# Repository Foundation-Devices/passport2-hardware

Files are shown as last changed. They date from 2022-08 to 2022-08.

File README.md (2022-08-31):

# Passport Electromechanical Design

This repository contains the electromechanical design files for Passport.

Passport

## Folder Organization
This repo contains the following folders:

- **`electronics`** - The Passport PCB design files.
- **`mechanical`** - The Passport enclosure design files, including front cover, mid-housing, rear cover and keypad parts.
- **`bill-of-materials`** - Spreadsheet list of all custom and stock physical components used to assemble Passport.

## Licensing
License information can be found in each folder.

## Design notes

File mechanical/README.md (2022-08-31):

# Passport Mechanical

This repository contains the full production assembly for Passport, an open source Bitcoin hardware wallet made by Foundation Devices.

Passport

### Folder Organization
This repo contains the following folders:
- **`STEP Files`** - a set of 3D models for Passport in STEP format.

### Documenting Changes
This repository includes a CHANGES.txt file. We will document all design changes in this file. If you submit a pull request that makes changes to the circuit designs, please update CHANGES.txt with a brief description of your changes.

## Security Vulnerability Disclosure
Please report suspected security vulnerabilities in private to security@foundationdevices.com. Please do NOT create publicly viewable issues for suspected security vulnerabilities.

## Licensing
The hardware in this project, including all mechanical and electrical design files, is licensed under CERN-OHL-S v2 – a viral, copyleft, open source license. CERN-OHL-S v2 is similar in goals to GPLv3, but is specifically designed for hardware projects.

The software in this project, as detailed in the passport-firmware submodule, is licensed under numerous software licenses but must be treated as copyleft due to the inclusion of GPLv3 licensed code.

You are welcome to use these designs for any purpose, but you must comply with the terms of the licenses. This includes licensing derivative work as CERN-OHL-S v2 and GPLv3, preserving copyright notices, and more. Instructions are included in LICENSE_GUIDE.txt. Feel free to contact us with any questions about licensing.

Included in this repository in LICENSE.txt is the full text of CERN-OHL-S v2.

### License Notice
You may redistribute and modify this source and make products using it
under the terms of the CERN-OHL-S v2 (https://ohwr.org/cern_ohl_s_v2.txt).

This source is distributed WITHOUT ANY EXPRESS OR IMPLIED WARRANTY,
INCLUDING OF MERCHANTABILITY, SATISFACTORY QUALITY AND FITNESS FOR A
PARTICULAR PURPOSE. Please see the CERN-OHL-S v2 for applicable conditions.

Source location: foundationdevices.com/passport-assembly

As per CERN-OHL-S v2 section 4, should You produce hardware based on this
source, You must where practicable and applicable maintain the Source Location
visible (1) on the packaging of the hardware, (2) on the circuit board(s) via
silkscreen or copper, (3) on the plastic and metal components, (4) in any documentation, 
and (5) on other products you make using this source.

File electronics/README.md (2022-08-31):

# Passport Electronics

This repository contains the production circuit designs for Passport 2, an open source Bitcoin hardware wallet made by Foundation Devices.

main board block diagram

Above is a basic block diagram for Passport's circuit Board.

## Project Structure

### Folder Organization
The circuit board files are in several sub-folders under the `PCB` folder.

- Assembly
- Documentation
- Fabrication
- Source Files

**Assembly** contains data for assembling components onto a bare circuit board. It includes drawings, bill of materials, and coordinates for pick-and-place and test points.

**Documentation** contains simple PDF overview documents of the schematics and board design.

**Fabrication** contains data for the circuit board fabricator. It includes drawings, Gerber files, and coordinates for drilling and test points.

**Source Files** contains circuit board designs. It includes circuit schematics and Altium design files.

Circuit designs can only be opened with Altium. We are exploring exporting these designs in multiple file formats, including formats that can be used with open source PCB design software.

If you are interested in using KiCAD, you may try this Altium to KiCAD converter: https://github.com/thesourcerer8/altium2kicad/.

### Documenting Changes
This repository includes a CHANGES.txt file. We will document all design changes in this file. If you submit a pull request that makes changes to the circuit designs, please update CHANGES.txt with a brief description of your changes.

## Open Source Components
Passport's Main Board incorporates an open-source schematic from the [Betrusted project](https://github.com/betrusted-io/betrusted-hardware-xt). Specifically, we implemented Betrusted's [Avalance Noise Source](https://betrusted.io/avalanche-noise) design into Passport to serve as a true random number generator that does not rely on black-box silicon. Thank you to the Betrusted team for open sourcing their excellent work.

## Security Vulnerability Disclosure
Please report suspected security vulnerabilities in private to security@foundationdevices.com. Please do NOT create publicly viewable issues for suspected security vulnerabilities.

## Licensing
This project, and every file included in this repository, is licensed under CERN-OHL-S v2 – a viral, copyleft, open source license. CERN-OHL-S v2 is similar in goals to GPLv3, but is specifically designed for hardware projects.

You are welcome to use these designs for any purpose, but you must comply with the terms of the license. This includes licensing derivative work as CERN-OHL-S v2, preserving copyright notices, and more. Instructions are included in LICENSE_GUIDE.txt. Feel free to contact us with any questions about licensing.

Included in this repository in LICENSE.txt is the full text of CERN-OHL-S v2.

### License Notice
You may redistribute and modify this source and make products using it
under the terms of the CERN-OHL-S v2 (https://ohwr.org/cern_ohl_s_v2.txt).

This source is distributed WITHOUT ANY EXPRESS OR IMPLIED WARRANTY,
INCLUDING OF MERCHANTABILITY, SATISFACTORY QUALITY AND FITNESS FOR A
PARTICULAR PURPOSE. Please see the CERN-OHL-S v2 for applicable conditions.

Source location: foundationdevices.com/passport-electronics

As per CERN-OHL-S v2 section 4, should You produce hardware based on this
source, You must where practicable and applicable maintain the Source Location
visible (1) on the packaging of the hardware, (2) on the circuit board(s) via
silkscreen or copper, (3) in any documentation, and (4) on other products you
make using this source.

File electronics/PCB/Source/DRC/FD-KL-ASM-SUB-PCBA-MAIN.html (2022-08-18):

Altium

# Design Rule Verification Report

Date: | | 12/11/2021
Time: | | 8:59:33 PM
Elapsed Time: | | 00:00:12
Filename: | | C:\Users\matth\AppData\Local\TempReleases\Snapshot\6\FD-KL-ASM-SUB-PCBA-MAIN.PcbDoc

Warnings: | | 0
Rule Violations: | | 0

## Summary

Warnings | Count
Total | 0

Rule Violations | Count
Clearance Constraint (Gap=0.1mm) ((InNetClass('DCMI') or InNet('DCMI_VREF1') or InNet('DCMI_VREF2') or InNet('+DCMI_AVDD') or InNet('+DCMI_DOVDD') or InNet('I2C1_SDA') or InNet('I2C1_SCL')) and Onlayer('L4') or InNet('+2V8_CAM_AVDD')),(All) | 0
Clearance Constraint (Gap=0.15mm) (InComponent('SW*')),(All) | 0
Clearance Constraint (Gap=0.1mm) (InNet('+VBAT') or InNet('+VBAT_MCU')),(All) | 0
Clearance Constraint (Gap=0.1mm) (InComponent('FID1') or InComponent('FID2') or InComponent('FID3') or InComponent('FID4') or InComponent('FID5') or InComponent('FID6')),(All) | 0
Clearance Constraint (Gap=0.2mm) (All),(All) | 0
Short-Circuit Constraint (Allowed=No) (All),(All) | 0
Un-Routed Net Constraint ( (All) ) | 0
Modified Polygon (Allow modified: No), (Allow shelved: No) | 0
Width Constraint (Min=0.1mm) (Max=1mm) (Preferred=0.1mm) (InNetClass('DCMI') or InNet('I2C1_SCL') or InNet('I2C1_SDA') or InNet('GND')) | 0
Width Constraint (Min=0.1mm) (Max=5mm) (Preferred=0.15mm) (All) | 0
Routing Layers(All) | 0
Routing Via (MinHoleWidth=0.2mm) (MaxHoleWidth=0.4mm) (PreferredHoleWidth=0.3mm) (MinWidth=0.4mm) (MaxWidth=0.8mm) (PreferedWidth=0.6mm) (All) | 0
Differential Pairs Uncoupled Length using the Gap Constraints (Min=0.2mm) (Max=0.2mm) (Prefered=0.2mm) and Width Constraints (Min=0.2mm) (Max=0.2mm) (Prefered=0.2mm) (All) | 0
SMD Neck-Down Constraint (Percent=100%) (All) | 0
Power Plane Connect Rule(Relief Connect )(Expansion=0.508mm) (Conductor Width=0.254mm) (Air Gap=0.254mm) (Entries=4) (All) | 0
Minimum Annular Ring (Minimum=0.099mm) (All) | 0
Hole Size Constraint (Min=0.2mm) (Max=5.5mm) (All) | 0
Pads and Vias to follow the Drill pairs settings | 0
Hole To Hole Clearance (Gap=0.2mm) (All),(All) | 0
Minimum Solder Mask Sliver (Gap=0.049mm) (All),(All) | 0
Silk To Solder Mask (Clearance=0.08mm) (IsPad),(All) | 0
Silk to Silk (Clearance=0.1mm) (All),(All) | 0
Net Antennae (Tolerance=0mm) (All) | 0
Board Clearance Constraint (Gap=0mm) (All) | 0
Board Clearance Constraint (Gap=0mm) (OnLayer('Top Overlay')) | 0
Vias Under SMD Constraint (Allowed=Not Allowed) ((not InNet('GND'))) | 0
Component Clearance Constraint ( Horizontal Gap = -1mm, Vertical Gap = -1mm ) (InComponent('R53')),(InComponent('R57')) | 0
Component Clearance Constraint ( Horizontal Gap = -1mm, Vertical Gap = -1mm ) (InComponent('R54')),(InComponent('R61')) | 0
Component Clearance Constraint ( Horizontal Gap = -1mm, Vertical Gap = -1mm ) (InComponent('R63')),(InComponent('R68')) | 0
Component Clearance Constraint ( Horizontal Gap = -1mm, Vertical Gap = -1mm ) (InComponent('R71')),(InComponent('R72')) | 0
Component Clearance Constraint ( Horizontal Gap = -1mm, Vertical Gap = -1mm ) (InComponent('R2')),(InComponent('R64')) | 0
Component Clearance Constraint ( Horizontal Gap = -1mm, Vertical Gap = -1mm ) (InComponent('R58')),(InComponent('R67')) | 0
Component Clearance Constraint ( Horizontal Gap = -1mm, Vertical Gap = -1mm ) (Identifier='FD-1842_Assem_v05_2020-06-12'),(All) | 0
Component Clearance Constraint ( Horizontal Gap = -1mm, Vertical Gap = -1mm ) (InComponent('R9')),(InComponent('R73')) | 0
Component Clearance Constraint ( Horizontal Gap = -1mm, Vertical Gap = -1mm ) ((Identifier='FD-KL-HOUSING-FRONT') or (Identifier='FD-KL-FG-HOUSING-MID') or (Identifier='FD-KL-LATCH-BATTERY') or (Identifier='FD-KL-LENS-LIGHTPIPE') or (Identifier='FD-KL-ASM-FG-DISPLAY-LCD-IPS-2-INCH') or (Identifier='FD-KL-ASM-FG-KEYPAD') or (Identifier='FD-KL-ACTUATOR-BUTTON-POWER') or (Identifier='FD-KL-FG-COVER-REAR')),(All) | 0
Component Clearance Constraint ( Horizontal Gap = 0.1mm, Vertical Gap = 0.1mm ) (All),(All) | 0
Component Clearance Constraint ( Horizontal Gap = -1mm, Vertical Gap = -1mm ) (InComponent('R53')),(InComponent('R54')) | 0
Component Clearance Constraint ( Horizontal Gap = -1mm, Vertical Gap = -1mm ) (InComponent('R62')),(InComponent('C51')) | 0
Component Clearance Constraint ( Horizontal Gap = -1mm, Vertical Gap = -1mm ) (InComponent('R69')),(InComponent('R70')) | 0
Height Constraint (Min=0mm) (Max=25.4mm) (Prefered=12.7mm) (All) | 0
Height Constraint (Min=0mm) (Max=1mm) (Prefered=0.5mm) (TouchesRoom('BatteryClearance')) | 0
Total | 0

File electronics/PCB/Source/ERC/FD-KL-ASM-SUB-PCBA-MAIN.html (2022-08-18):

Altium

# Electrical Rule Check Report

Date: | | 12/11/2021
Time: | | 8:59:49 PM
Filename: | | C:\Users\matth\AppData\Local\TempReleases\Snapshot\6\Sources\ERC\FD-KL-ASM-SUB-PCBA-MAIN.html

Class | Document | Message
Warning | STM32H753.SchDoc | Net BRDREV0 has no driving source (Pin R2-1, Pin R64-2, Pin TP53-1, Pin U2-58)
Warning | Title.SchDoc | Net LCD_TE has no driving source (Pin J2-2, Pin TP66-1, Pin U2-91)
Warning | Charger.SchDoc | Net NetC66_2 has no driving source (Pin C66-2, Pin R84-1, Pin U27-D3)
Warning | Charger.SchDoc | Net NetC67_1 has no driving source (Pin C67-1, Pin C68-2, Pin R87-2, Pin U27-A1)
Warning | Charger.SchDoc | Net NetC67_2 has no driving source (Pin C67-2, Pin C69-1, Pin R88-2, Pin U27-B1)
Warning | Charger.SchDoc | Net NetR86_1 has no driving source (Pin R86-1, Pin TP73-1, Pin U23-5)
Warning | Power.SchDoc | Net PS_3V0_FB has no driving source (Pin C54-2, Pin R30-1, Pin R32-1, Pin U11-10)
Warning | Title.SchDoc | Net PWR_SW_MCU has no driving source (Pin D1-A, Pin R37-2, Pin TP75-1, Pin U2-34)
Warning | Title.SchDoc | Net SYS_RST# has no driving source (Pin C52-1, Pin J4-8, Pin R3-1, Pin TP43-1, Pin U2-14)
Warning | Title.SchDoc | Net USART2_RX has no driving source (Pin J4-11, Pin TP46-1, Pin U2-25)
Warning | Camera.SchDoc | Nets Wire GND has multiple names (Power Object GND (123), Power Object GND_A (6))

Back to top

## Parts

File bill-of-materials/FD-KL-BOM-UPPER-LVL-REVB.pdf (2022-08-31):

Assembly / Sub Assembly | LVL CAD Name / Foundation SKU | REV | Description | QTY | Custom Manufacturer | MFG P/N
1 FD-KL Asm Sub PCBA Main | 1 | FD-KL-ASM-SUB-PCBA-MAIN | A5.2 | Populated main circuit board sub assembly | 1 | N/A | -- | FD-KL-ASM-SUB-PCBA-MAIN
1 FD-KL Asm Sub PCBA Main | 2 | FD-KL-PCB-MAIN | A3 | Unpopulated, bare, main circuit board | 1 | Y | -- | FD-KL-PCB-MAIN
1 FD-KL Asm Sub PCBA Main | 2 | FD-KL-EE-BOM | A | All electronic components that get placed on the bare PCB | 1 | N | See PCBA BOM | See PCBA BOM
2 FD-KL Asm Sub Housing Mid | 1 | FD-KL-ASM-SUB-HOUSING-MID | B | Completed mid housing sub assembly | 1 | N/A | -- | FD-KL-ASM-SUB-HOUSING-MID
2 FD-KL Asm Sub Housing Mid | 2 | FD-KL-FG-HOUSING-MID
| | (FD-KL-MAGNET-DISC-0.125-0.625-REV-A x4) (FD-KL-ACTUATOR-BUTTON-POWER-REV-B x1) (FD-KL-LEAF-SPRING-0.15-REV-B x1) | A | Die casted zinc alloy that is sandblasted, polished, electroplated with copper, and then e-coated with protective clear coating
| | | | 4x magnets , a thin sheet metal leaf spring, and a metal power button (same process as above) get installed into this mid housing component | 1 | Y | -- | FD-KL-FG-HOUSING-MID
2 FD-KL Asm Sub Housing Mid | 2 | FD-KL-LENS-CAMERA | B | Optically clear PC plastic camera lens, printed black one side | 1 | Y | -- | FD-KL-LENS-CAMERA
2 FD-KL Asm Sub Housing Mid | 2 | FD-KL-ASM-SUB-PCBA-MAIN | A | Populated main circuit board sub assembly | 1 | Y | -- | FD-KL-ASM-SUB-PCBA-MAIN
2 FD-KL Asm Sub Housing Mid | 2 | FD-KL-SCREW-18-8-M1.6 | A | M1.6-0.35 x 6 mm Machine Screw / Phillips / Flat Head / 18-8 | 4 | N | Fastener Superstore 577418
2 FD-KL Asm Sub Housing Mid | 2 | FD-KL-KAPTON-TAPE | A | Kapton® Tape - 1 Mil, 1 ⁄" | 1 | N | ULINE | S-17210
2 FD-KL Asm Sub Housing Mid | 2 | FD-KL-MEMBRANE | B | Clear polyester film membrane with adhesive | 1 | Y | -- | FD-KL-MEMBRANE
2 FD-KL Asm Sub Housing Mid | 2 | FD-KL-FOAM-KEYPAD | D | Black compressible EPDM foam with adhesive | 4 | Y | -- | FD-KL-FOAM-KEYPAD
2 FD-KL Asm Sub Housing Mid | 2 | FD-KL-DISPLAY-BACKER | A | Clear PETG plastic rails with adhesive | 2 | Y | -- | FD-KL-DISPLAY-BACKER
2 FD-KL Asm Sub Housing Mid | 2 | FD-KL-ASM-FG-DISPLAY-LCD-IPS-2-INCH
| | (FD-KL-SCREEN-LCD-IPS-2-INCH-REV-C x1) (FD-KL-GASKET-LCD-IPS-2-INCH-REV-A x1) (FD-KL-DISPLAY-LCD-IPS-2-INCH-REV-A x1) | C | LCD module with strong cover glass, perimeter gasket, LCD display with backlight, and FPC connector | 1 | Y | -- | FD-KL-ASM-FG-DISPLAY-LCD-IPS-2-INCH
3 FD-KL Asm Sub Housing Front | 1 | FD-KL-ASM-SUB-HOUSING-FRONT | B | Completed front housing sub assembly | 1 | N/A | -- | FD-KL-ASM-SUB-HOUSING-FRONT
3 FD-KL Asm Sub Housing Front | 2 | FD-KL-FG-HOUSING-FRONT
| | (FD-KL-LENS-LIGHTPIPE x1) | B | Black PC/ABS plastic front housing with heat-staked lightpipe lens for LED light diffusion | 1 | Y | -- | FD-KL-HOUSING-FRONT
3 FD-KL Asm Sub Housing Front | 2 | FD-KL-KEYPAD-UPPER
| | (FD-KL-NAV-CENTER-REV-B x1) (FD-KL-NAV-RIGHT-REV-A x1) (FD-KL-NAV-LEFT-REV-A x1) | B | Die casted zinc alloy that is sandblasted, polished, electroplated in copper, and then e-coated with protective clear coating | 1 | Y | -- | FD-KL-NAV-CENTER FD-KL-NAV-RIGHT FD-KL-NAV-LEFT
3 FD-KL Asm Sub Housing Front | 2 | FD-KL-KEYPAD-LOWER | B | Black ABS plastic keys overmolded with black TPE material, pad printed with white text, and UV coated with a protective clear coating | 1 | Y | -- | FD-KL-KEYPAD-LOWER
4 FD-KL Asm Sub Rear Cover | 1 | FD-KL-ASM-SUB-COVER-REAR | D | Completed rear cover sub assembly | 1 | N/A | -- | FD-KL-ASM-SUB-COVER-REAR
4 FD-KL Asm Sub Rear Cover | 2 | FD-KL-FG-COVER-REAR
| | (FD-KL-COVER-REAR x1) (FD-KL-MAGNET-DISC-0.125-0.625 x4) | D | White PC/ABS plastic rear cover with heat transfer wordmark and 4x magnets installed | 1 | Y | -- | FD-KL-FG-COVER-REAR
5 FD-KL ASM TOP LVL DEVICE | 1 | FD-KL-ASM-TOP-LVL-DEVICE | B | Sub-assembled top level device ready for packout/shipping | 1 | N/A | -- | FD-KL-ASM-TOP-LVL-DEVICE
5 FD-KL Asm Sub Rear Cover | 2 | FD-KL-SCREW-THREADFORMING-0-.25 | A | No. 0 - 1/4" Flat Head Torx Plus Threadforming Screw 18-8 | 2 | N | DB Roberts | 3BT-F9030-00
5 FD-KL ASM TOP LVL DEVICE | 2 | FD-KL-LABEL-COVER | A | Battery area regulatory/informational cover label | 1 | Y | -- | FD-KL-LABEL-COVER
5 FD-KL ASM TOP LVL DEVICE | 2 | FD-KL-BATTERY-LITHIUM-RECHARGEABLE | A | Rechargeable and user-removeable lithium ion battery | 1 | Y | -- | BL-5C
6 FD-KL Asm Sub Packout Box | 1 | FD-KL-ASM-SUB-PACKOUT | B | Completed packout sub assembly | 1 | N/A | -- | FD-KL-ASM-SUB-PACKOUT
6 FD-KL Asm Sub Packout Box | 2 | FD-KL-FG-BOX-SETUP-BRANDED
| | (FD-KL-PKG-BOX-LID x1) (FD-KL-PKG-INSERT-STYRENE-TOP x1) (FD-KL-PKG-INSERT-STYRENE-BOTTOM x1) (FD-KL-PKG-BOX-BOTTOM x1) | A | Branded setup box with base, lid, and two plastic trays that hold the accessories, paper collateral, and the final device | 1 | Y | -- | FD-KL-BOX-SETUP-BRANDED
6 FD-KL Asm Sub Packout Box | 2 | FD-KL-CABLE-USBC | A | Black power-only USBC to USBC cable | 1 | Y | -- | FD-KL-CABLE-USBC
6 FD-KL Asm Sub Packout Box | 2 | FD-KL-CASE-&-CARD-MICROSD | A | Industrial grade MicroSD card with clear plastic carrying case 1 | N | Western Digital | SDSDQAF3-008G-XI-J
6 FD-KL Asm Sub Packout Box | 2 | FD-KL-READER-USBC-MICROSD | A | Black MicroSD card reader/adapter for USBC devices | 1 | Y | -- | FD-KL-READER-USBC-MICROSD
6 FD-KL Asm Sub Packout Box | 2 | FD-KL-READER-LIGHTNING-MICROSD | A | Black MicroSD card reader/adapter for Apple devices | 1 | Y | -- | FD-KL-READER-LIGHTNING-MICROSD
6 FD-KL Asm Sub Packout Box | 2 | FD-KL-CARD-QS | A | Premium card stock quick start guide | 1 | Y | -- | FD-KL-CARD-QS
6 FD-KL Asm Sub Packout Box | 2 | FD-KL-CARD-BACKUP | B | Premium card stock backup card (perforated) | 1 | Y | -- | FD-KL-CARD-SECURITY
6 FD-KL Asm Sub Packout Box | 2 | FD-KL-STICKERS-LOGO | A | 2x Foundation logo stickers on a release film | 1 | Y | -- | FD-KL-STICKERS-LOGO
6 FD-KL Asm Sub Packout Box | 2 | FD-KL-SHRINK | A | Shrink wrap that seals branded packaging box | 1 | N | ULINE | S-16357
7 FD-KL ASM TOP LVL PRODUCT | 1 | FD-KL-PRODUCT-PP | A | Final QC'd device, in branded packaging with accessories and paper collateral, shrink wrapped, ready for shipping | 1 | N/A | -- | FD-KL-PRODUCT-PP
7 FD-KL ASM TOP LVL PRODUCT | 2 | FD-KL-BOX-OVERPACK | A | White indestructo cardboard overpack box mailer | 1 | N | ULINE | S-430
7 FD-KL ASM TOP LVL PRODUCT | 2 | FD-KL-TAPE-TAMPER | A | Blue tamper evident tape used to seal overpack box | 1 | N | ULINE | S-16981BLU
7 FD-KL ASM TOP LVL PRODUCT | 2 | FD-KL-LABEL-AIR-LITHIUM | A | Regulatory lithium air label for shipping >2 devices at once | 1 | N | ULINE | S-23263

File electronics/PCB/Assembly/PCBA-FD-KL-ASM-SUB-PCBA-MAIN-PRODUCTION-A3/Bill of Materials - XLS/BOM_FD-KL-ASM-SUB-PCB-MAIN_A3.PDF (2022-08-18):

Line # | Rev | Fitted | Name | Description | Designator | Quantity | Manufacturer 1 | Manufacturer Part Number 1 | Manufacturer 2 | Manufacturer Part Number 2 | Manufacturer 3 | Manufacturer Part Number 3
1 | A3 | Fitted | FD-KL-ASM-SUB-PCB-MAIN | Printed Circuit Board | PCB1 | 1
2 | Fitted | 114-00841-68 | 10 (8 + 2) Position Card Connector Secure Digital - microSD™ Surface Mount, Right Angle Gold | J1 | | 1 Amphenol | 114-00841-68
3 | Fitted | 503480-2200 | 22 Position FFC, FPC Connector Contacts, Top and Bottom 0.020" (0.50mm) Surface Mount, Right Angle | J2 | | 1 Molex | 503480-2200
4 | Fitted | 009155003301006-2 | 3 Position Spring Battery Contact Connector Surface Mount, Right Angle | J3 | | 1 AVX | 009155003301006
5 | Fitted | ADP2503ACPZ-R7 | Buck-Boost Switching Regulator IC Positive Adjustable 2.8V 1 Output 600mA 10-VFDFN Exposed Pad, CSP | U11 | | 1 Analog Devices | ADP2503ACPZ-R7
6 | Fitted | ADP5587ACPZ-R7 | I/O Expander 18 I²C 400kHz 24-LFCSP-WQ (4x4) | U4 | | 1 Analog Devices | ADP5587ACPZ-R7
7 | Not Fitted | ATECC608A-MAHCZ-T | Cryptographic Co-Processor with Secure Hardware-Based Key Storage 1-Wire Interface 8-Pin UDFN T/R | U10 | | 0 Microchip | ATECC608A-MAHCZ-T
8 | Fitted | ATECC608A-SSHCZ-T | Cryptographic Co-Processor with Secure Hardware-Based Key Storage 1-Wire Interface 8-Pin SOIC T/R | U5 | | 1 Microchip | ATECC608A-SSHCZ-T
9 | Fitted | BCR421UFD-7 | LED Driver IC 1Output Linear - PWM Dimming 350mA U-DFN2020-6 | U32 | | 1 Diodes | BCR421UFD-7
10 | Fitted | BLM18PG221SH1D | FERRITE BEAD 220OHM 0603 1LN | L5, L6 | | 2 Murata | BLM18PG221SH1D | Bourns | MH1608-221Y
11 | Fitted | BQ25050DQCR | Charger IC Lithium Ion 10-WSON (3x2) | U23 | | 1 Texas Instruments BQ25050DQCR | | Texas Instruments BQ25050DQCT
12 | Fitted | BQ27520YZFR-G4 | Battery Battery Monitor IC Lithium Ion 15-DSBGA | U27 | | 1 Texas Instruments BQ27520YZFR-G4
13 | Fitted | BZT585B15T-7 | Zener Diode 15V 350mW ±2% Surface Mount SOD-523 | D2, D3 | | 2 Diodes | DDZ9703T-7 | MCC | BZT52C15T-TP | Diodes | BZT585B15T-7
14 | Fitted | CAP CER 0.01uF 50V 10% X7R 0402 | 10000pF ±10% 50V Ceramic Capacitor X7R 0402 (1005 Metric) | C2, C34 | | 2 Samsung | CL05B103KB5NNNC | Yageo | CC0402KRX7R9BB103 | Murata | GRM155R71H103KA88D
15 | Fitted | CAP CER 0.033uF 25V 10% X7R 0402 | 0.033µF ±10% 25V Ceramic Capacitor X7R 0402 (1005 Metric) | C64 | | 1 Yageo | CC0402KRX7R8BB333 | KEMET | C0402C333K3RACTU | Murata | GCM155R71E333KA55D
16 | Fitted | CAP CER 0.047uF 10V 10% X7R 0402 | 0.047µF ±10% 10V Ceramic Capacitor X7R 0402 (1005 Metric) | C53, C84, C88 | | 3 Murata | GRM155R71A473KA01D | Yageo | CC0402KRX7R6BB473 | KEMET | C0402C473K8RACTU
17 | Fitted | CAP CER 0.1uF 16V 10% X7R 0402 | 0.1µF ±10% 16V Ceramic Capacitor X7R 0402 (1005 Metric) | C3, C5, C6, C7, C8, C9, C10, C11, C12, C14, C15, C18, C20, C21, C22, C23, C25, C28, C29, C33, C37, C38, C39, C43, C48, C52, C56, C60, C61, C62, C65, C66, C67, C68, C69, C72, C73, C76, C77, C79, C80, C82, C87 | 43 Murata | | GCM155R71C104KA55D | TDK | C1005X7R1C104K050BC | KEMET | C0402C104K4RACAUTO
17 | Not Fitted | CAP CER 0.1uF 16V 10% X7R 0402 | 0.1µF ±10% 16V Ceramic Capacitor X7R 0402 (1005 Metric) | C26 | | 0 Murata | GCM155R71C104KA55D | TDK | C1005X7R1C104K050BC | KEMET | C0402C104K4RACAUTO
18 | Fitted | CAP CER 1uF 25V 10% X5R 0402 | 1uF ±10% 25V Ceramic Capacitor X5R 0402 (1005 Metric) | C44, C45, C59, C63 | | 4 Yageo | CC0402KRX5R8BB105 | Taiyo Yuden | UMK105CBJ105KV-F | Samsung | CL05A105KA5NQNC
18 | Not Fitted | CAP CER 1uF 25V 10% X5R 0402 | 1uF ±10% 25V Ceramic Capacitor X5R 0402 (1005 Metric) | C86 | | 0 Yageo | CC0402KRX5R8BB105 | Taiyo Yuden | UMK105CBJ105KV-F | Samsung | CL05A105KA5NQNC
19 | Fitted | CAP CER 1.5pF 50V C0G 0402 | 1.5pF ±0.25pF 50V Ceramic Capacitor C0G, NP0 0402 (1005 Metric) | C49, C55 | | 2 Kyocera AVX | 04025A1R5CAT2A | KEMET | C0402C159C5GACTU | Murata | GJM1555C1H1R5CB01D
19 | Not Fitted | CAP CER 1.5pF 50V C0G 0402 | 1.5pF ±0.25pF 50V Ceramic Capacitor C0G, NP0 0402 (1005 Metric) | C54 | | 0 Kyocera AVX | 04025A1R5CAT2A | KEMET | C0402C159C5GACTU | Murata | GJM1555C1H1R5CB01D
20 | Fitted | CAP CER 4.7UF 10V 20% X5R 0402 | 4.7µF ±20% 10V Ceramic Capacitor X5R 0402 (1005 Metric) | C16, C35, C36, C70, C71, C74, C75, C81, C89 | | 9 Samsung | CL05A475MP5NRNC | Murata | ZRB15XR61A475ME01D | TDK | C1005X5R1A475M050BC
21 | Fitted | CAP CER 10uF 6.3V 20% X5R 0603 | 10µF ±20% 6.3V Ceramic Capacitor X5R 0603 (1608 Metric) | C30, C31, C32 | | 3 Murata | GRM188R60J106ME47D | Kyocera AVX | 06036D106MAT2A | Yageo | CC0603MRX5R5BB106
22 | Not Fitted | CAP CER 10uF 10V 20% X5R 0402 | 10µF ±20% 10V Ceramic Capacitor X5R 0402 (1005 Metric) | C85 | | 0 Samsung | CL05A106MP8NUB8
23 | Fitted | CAP CER 22uF 6.3V 20% X5R 0603 | 22µF ±20% 6.3V Ceramic Capacitor X5R 0603 (1608 Metric) | C19, C78 | | 2 Samsung | CL10A226MQ8NRNE
23 | Not Fitted | CAP CER 22uF 6.3V 20% X5R 0603 | 22µF ±20% 6.3V Ceramic Capacitor X5R 0603 (1608 Metric) | C24, C27 | | 0 Samsung | CL10A226MQ8NRNE
24 | Fitted | CAP CER 220pF 50V 5% C0G 0402 | 220pF ±5% 50V Ceramic Capacitor C0G, NP0 0402 (1005 Metric) | C42, C47 | | 2 Samsung | CL05C221JB5NNNC | Kyocera AVX | 04025A221JAT2A | Murata | GCM1555C1H221JA16D
25 | Fitted | CAP CER 1000pF 1000V 10% X7R 0805 | 1000pF ±10% 1000V (1kV) Ceramic Capacitor X7R 0805 (2012 Metric) | C17, C57 | | 2 KEMET | C0805C102KDRACTU
26 | Fitted | CAP CER 1500pF 50V 10% X7R 0402 | 1500pF ±10% 50V Ceramic Capacitor X7R 0402 (1005 Metric) | C41, C46, C51 | | 3 Murata | GCM155R71H152KA37D
27 | Fitted | CAP CER 2.2uF 6.3V 10% X5R 0402 | 2.2µF ±10% 6.3V Ceramic Capacitor X5R 0402 (1005 Metric) | C4, C13, C40, C50, C58, C83 | | 6 KEMET | C0402C225K9PACTU | Samsung | CL05A225KQ5NSNC | Kyocera AVX | 04026D225KAT2A
28 | Fitted | CAT24C04C4ATR | EEPROM Memory IC 4Kb (512 x 8) I²C 400kHz 900ns 4-WLCSP (0.84x0.86) | U3 | | 1 ON Semiconductor | CAT24C04C4ATR
29 | Fitted | CSTNE8M00G550000R0 | 8MHz Ceramic Resonator Built in Capacitor 33pF ±0.2% 40 Ohms -40°C ~ 85°C Surface Mount | X2 | | 1 Murata | CSTNE8M00G550000R0 | Abracon | AWSCR-8.00CELB-C10-T3 | ECS International | ECS-CTE-8.00-10-TR
30 | Fitted | D5V0M1U2S9-7 | 12V Clamp 9A (8/20µs) Ipp Tvs Diode Surface Mount SOD-923 | D5, D6 | | 2 Diodes | D5V0M1U2S9-7
31 | Fitted | DMP2104LP-7 | P-Channel 20 V 1.5A (Ta) 500mW (Ta) Surface Mount 3-DFN1411 (1.4x1.1) | Q1, Q2 | | 2 Diodes | DMP2104LP-7
32 | Fitted | ECS-.327-6-12-TR | Parallel - Fundamental Quartz Crystal, 0.032768MHz Nom | X1 | | 1 ECS International | ECS-.327-6-12-C-TR | ECS International | ECS-.327-6-12-TR
33 | Not Fitted | FH34SRJ-16S-0.5SH(50) | 16 Position FFC, FPC Connector Contacts, Top and Bottom 0.020" (0.50mm) Surface Mount, Right Angle | J4 | | 0 Hirose | FH34SRJ-16S-0.5SH(50)
34 | Fitted | IN-S63AT5A | Amber 605nm LED Indication - Discrete 1.9V 0603 (1608 Metric) | LED9 | | 1 Inolux | IN-S63AT5A
34 | Not Fitted | IN-S63AT5A | Amber 605nm LED Indication - Discrete 1.9V 0603 (1608 Metric) | LED8 | | 0 Inolux | IN-S63AT5A
35 | Fitted | IN-S63AT5UW | White - LED Indication - Discrete 3V 0603 (1608 Metric) | LED10 | | 1 Inolux | IN-S63AT5UW
36 | Fitted | KB DELPS2.DI-THVG-2J8L-Z555 | Blue 466nm LED Indication - Discrete 2.8V 2-SMD 0603 | LED2 | | 1 Osram Opto | KB DELPS2.DI-THVG-2J8L-Z555
37 | Fitted | KRL3216T4A-M-R010-F-T1 | Fixed Resistor, Metal Foil, 1W, 0.01ohm, 1% +/-Tol, 35ppm/Cel, Surface Mount, 1206 | R89 | | 1 Susumu | KRL3216T4A-M-R010-F-T1
38 | Fitted | LMV981TLX/NOPB | General Purpose Amplifier 1 Circuit Rail-to-Rail 6-DSBGA (1.5x1.3) | U16, U18 | | 2 TI National Semiconductor | LMV981TLX/NOPB
39 | Fitted | LTST-C191KRKT | Red 631nm LED Indication - Discrete 2V 0603 (1608 Metric) | LED1 | | 1 Vishay Lite-On | LTST-C191KRKT
40 | Fitted | MAKK2016T1R0M | 1 µH Shielded Wirewound Inductor 2.2 A 75mOhm Max 0806 (2016 Metric) | L2 | | 1 Taiyo Yuden | MAKK2016T1R0M
41 | Fitted | MAKK2520H1R5M | 1.5 µH Shielded Wirewound Inductor 2.4 A 78mOhm Max 1008 (2520 Metric) | L1 | | 1 Taiyo Yuden | MAKK2520H1R5M
42 | Fitted | MCP1501T-25E/RW | Series Voltage Reference IC 2.5V ±0.1% 8-WDFN (2x2) | U20 | | 1 Microchip | MCP1501T-25E/RW
43 | Fitted | MLZ1608M220WT000 | 22µH Shielded Multilayer Inductor 150mA 2.4Ohm 0603 (1608 Metric) | L4 | | 1 TDK | MLZ1608M220WT000
44 | Fitted | NCP15WB473F03RC | NTC Thermistor 47k 0402 (1005 Metric) | R86 | | 1 Murata | NCP15WB473F03RC
45 | Fitted | NTCG103JF103FT1 | NTC Thermistor 10k 0402 (1005 Metric) | R85 | | 1 TDK | NTCG103JF103FT1
46 | Fitted | NTK3043NT1G | N-Channel 20V 210mA (Ta) 310mW (Ta) Surface Mount SOT-723 | U8, U14, U22, U28 | | 4 ON Semiconductor | NTK3043NT1G
46 | Not Fitted | NTK3043NT1G | N-Channel 20V 210mA (Ta) 310mW (Ta) Surface Mount SOT-723 | U26 | | 0 ON Semiconductor | NTK3043NT1G
47 | Fitted | OVM7690-RYAA | SENSOR CAMERA CMOS 20CAMERACUBE | U29 | | 1 OmniVision Technologies | OVM7690-RYAA | OmniVision Technologies | OVM7690-R20A
48 | Fitted | PTS530GN055SMTRLFS | Tactile Switch SPST-NO Top Actuated Surface Mount | SW1, SW2, SW3, SW4, SW5, SW6, SW7, SW8, SW9, SW10, SW11, SW12, SW13, SW14, SW15, SW16, SW17, SW18 | 18 ITT C&K | | PTS530GN055SMTRLFS
49 | Fitted | PUSB3AB4Z | TVS DIODE 3.3V 5V DFN2510A-10 | U6, U7 | | 2 Nexperia | PUSB3AB4Z | Nexperia | PUSB3FR4Z
50 | Fitted | RB751S40T1G | Diode Schottky 30V 30mA (DC) Surface Mount SOD-523 | D1, D4 | | 2 ON Semiconductor | RB751S40T1G
51 | Fitted | RES 0OHM JUMPER 1/10W 0603 | 0Ohms Jumper 0.1W, 1/10W Chip Resistor 0603 (1608 Metric) | R71 | | 1 Stackpole Electronics | RMCF0603ZT0R00 | Vishay | CRCW06030000ZSTA
51 | Not Fitted | RES 0OHM JUMPER 1/10W 0603 | 0Ohms Jumper 0.1W, 1/10W Chip Resistor 0603 (1608 Metric) | R72, R79 | | 0 Stackpole Electronics | RMCF0603ZT0R00 | Vishay | CRCW06030000ZSTA
52 | Fitted | RES 0OHM JUMPER 1/16W 0402 | 0Ohms Jumper 0.063W, 1/16W Chip Resistor 0402 (1005 Metric) | R9, R57, R61, R75 | | 4 Stackpole Electronics | RMCF0402ZT0R00 | Yageo | RC0402JR-070RP | Vishay | CRCW04020000Z0ED
52 | Not Fitted | RES 0OHM JUMPER 1/16W 0402 | 0Ohms Jumper 0.063W, 1/16W Chip Resistor 0402 (1005 Metric) | R53, R54, R62, R73 | | 0 Stackpole Electronics | RMCF0402ZT0R00 | Yageo | RC0402JR-070RP | Vishay | CRCW04020000Z0ED
53 | Fitted | RES 1.0K 1/16W 1% 0402 | 1 kOhms ±0.5% 0.063W, 1/16W Chip Resistor 0402 (1005 Metric) Automotive AEC-Q200 Thin Film | R77, R84 | | 2 Vishay Dale | CRCW04021K00DHEDP | Yageo | RC0402FR-071KL | Panasonic | ERA-2AED102X
53 | Not Fitted | RES 1.0K 1/16W 1% 0402 | 1 kOhms ±0.5% 0.063W, 1/16W Chip Resistor 0402 (1005 Metric) Automotive AEC-Q200 Thin Film | R78 | | 0 Vishay Dale | CRCW04021K00DHEDP | Yageo | RC0402FR-071KL | Panasonic | ERA-2AED102X
54 | Fitted | RES 1.0M 1/4W 5% 1206 | 1 MOhms ±5% 0.25W, 1/4W Chip Resistor 1206 (3216 Metric) Moisture Resistant Thick Film | R8, R24 | | 2 KOA Speer | RK73B2BTTD105J | Yageo | RC1206JR-071ML
55 | Fitted | RES 1.8M 1/16W 1% 0402 | 1.8 MOhms ±1% 0.063W, 1/16W Chip Resistor 0402 (1005 Metric) | R76 | | 1 Stackpole Electronics | RMCF0402FT1M80 | Vishay | CRCW04021M80FKED
56 | Fitted | RES 2.2K 1/16W 1% 0402 | 2.2 kOhms ±1% 0.063W, 1/16W Chip Resistor 0402 (1005 Metric) | R10, R11, R27, R34 | | 4 Bourns | CR0402-FX-2201GLF | Samsung | RC1005F222CS | Yageo | AC0402FR-072K2L
57 | Fitted | RES 4.7K 1/16W 1% 0402 | 4.7 kOhms ±1% 0.063W, 1/16W Chip Resistor 0402 (1005 Metric) Automotive AEC-Q200 Thick Film | R7, R12, R13, R36, R55, R59, R60, R66 | | 8 Yageo | RC0402FR-134K7L | Stackpole Electronics | RMCF0402FT4K70
57 | Not Fitted | RES 4.7K 1/16W 1% 0402 | 4.7 kOhms ±1% 0.063W, 1/16W Chip Resistor 0402 (1005 Metric) Automotive AEC-Q200 Thick Film | R14, R15, R26, R35 | | 0 Yageo | RC0402FR-134K7L | Stackpole Electronics | RMCF0402FT4K70
58 | Fitted | RES 5.1K 1/16W 1% 0402 | 5.1 kOhms ±1% 0.063W, 1/16W Chip Resistor 0402 (1005 Metric) | R23, R28 | | 2 Yageo | RC0402FR-075K1L | Bourns | CR0402-FX-5101GLF | Vishay | CRCW04025K10FKED
59 | Fitted | RES 5.1M 1/16W 1% 0402 | 5.1 MOhms ±1% 0.1W, 1/10W Chip Resistor 0402 (1005 Metric) | R43, R48 | | 2 Yageo | RC0402FR-075M1L | Bourns | CR0402-JW-515GLF | Vishay | CRCW04025M10FKED
60 | Fitted | RES 10K 1/16W 1% 0402 | 10 kOhms ±1% 0.063W, 1/16W Chip Resistor 0402 (1005 Metric) | R3, R16, R17, R18, R19, R20, R21, R22, R33, R37, R46, R51, R64, R67, R68, R70 | 16 Yageo | | AC0402FR-0710KL | Bourns | CR0402-FX-1002GLF | Samsung | RC1005F103CS
60 | Not Fitted | RES 10K 1/16W 1% 0402 | 10 kOhms ±1% 0.063W, 1/16W Chip Resistor 0402 (1005 Metric) | R2, R58, R63, R82 | | 0 Yageo | AC0402FR-0710KL | Bourns | CR0402-FX-1002GLF | Samsung | RC1005F103CS
61 | Fitted | RES 15OHM 1% 1/16W 0402 | 15Ohms ±1% 0.063W, 1/16W Chip Resistor 0402 (1005 Metric) | R5, R41, R74 | | 3 TE Connectivity | CRGCQ0402F15R | Stackpole Electronics | RMCF0402FT15R0 | Yageo | RC0402FR-0715RL
62 | Fitted | RES 18.2K 1/16W 1% 0402 | 18.2 kOhms ±1% 0.063W, 1/16W Chip Resistor 0402 (1005 Metric) | R83 | | 1 Yageo | RC0402FR-0718K2L | Vishay | CRCW040218K2FKED
63 | Fitted | RES 21.5K 1/16W 1% 0402 | 21.5 kOhms ±1% 0.063W, 1/16W Chip Resistor 0402 (1005 Metric) | R6, R25, R32, R52 | | 4 Vishay | CRCW040221K5FKED | Stackpole Electronics | RMCF0402FT21K5
64 | Fitted | RES 100OHM 1/16W 1% 0402 | 100Ohms ±1% 0.063W, 1/16W Chip Resistor 0402 (1005 Metric) Thick Film | R87, R88 | | 2 Yageo | RC0402FR-07100RL | Vishay Dale | CRCW0402100RFKED
65 | Fitted | RES 100K 1/16W 1% 0402 | 100 kOhms ±1% 0.063W, 1/16W Chip Resistor 0402 (1005 Metric) Automotive AEC-Q200 Thick Film | R4, R30, R38, R39, R40, R42, R47, R56, R65, R69, R90, R91 | 12 Stackpole | Electronics | RMCF0402FT100K | Yageo | AC0402FR-07100KL | Vishay Dale | CRCW0402100KFKTD
66 | Fitted | RES 220K 1/16W 1% 0402 | 220 kOhms ±1% 0.063W, 1/16W Chip Resistor 0402 (1005 Metric) | R29, R31, R45, R50 | | 4 Vishay | CRCW0402220KFKED | Yageo | RC0402FR-07220KL
67 | Fitted | RES 470K 1/16W 1% 0402 | 470 kOhms ±1% 0.063W, 1/16W Chip Resistor 0402 (1005 Metric) | R44, R49 | | 2 Yageo | RC0402JR-07470KL | Vishay | CRCW0402470KFKED
68 | Fitted | STM32H753VIT6 | ARM® Cortex®-M7 STM32H7 Microcontroller IC 32-Bit 480MHz 2MB (2M x 8) FLASH 100-LQFP (14x14) | U2 | | 1 STMicroelectronic s | STM32H753VIT6
69 | Fitted | TL1014BF160QG | Tactile Switch SPST-NO Side Actuated Surface Mount, Right Angle | SW19 | | 1 E-Switch | TL1014BF160QG
70 | Not Fitted | TPS22930AYZVR | IC PWR SWITCH P-CHAN 1:1 4DSBGA | U31 | | 0 Texas Instruments TPS22930AYZVR
71 | Fitted | TPS61158DRVR | LED Driver IC 1Output DC DC Regulator Step-Up (Boost) PWM Dimming 30mA 6-WSON (2x2) | U17 | | 1 Texas Instruments TPS61158DRVR
72 | Fitted | TPS61253YFFR | Boost Switching Regulator IC Positive Fixed 5V 1Output 3.9A (Switch) 9-UFBGA, DSBGA | U13 | | 1 Texas Instruments TPS61253YFFR | | Texas Instruments TPS61253YFFT
73 | Fitted | TPS79928YZUR | Linear Voltage Regulator IC 1Output 200mA 5-DSBGA (1x1.37) | U21, U30 | | 2 Texas Instruments TPS79928YZUR
74 | Fitted | UJC-HP-3-SMT-TR | USB-C (USB TYPE-C) - Receptacle Connector 24 (6+18 Dummy) Position Surface Mount, Right Angle; Through Hole | CN1 | | 1 CUI Devices | UJC-HP-3-SMT-TR
75 | Fitted | W25Q64JVZPIQ TR | FLASH - NOR Memory IC 64Mb (8M x 8) SPI - Quad I/O 133 MHz 8-WSON (6x5) | U9 | | 1 Winbond | W25Q64JVZPIQ TR
76 | Fitted | TPS79920YZUT | Linear Voltage Regulator IC Positive Fixed 1Output 2.0V 200mA 5-DSBGA (1x1.37) | U1 | | 1 Texas Instruments TPS79920YZUT
77 | Fitted | XC6192AA05ER-G | Power Switch/Driver 1:1 P-Channel 400mA USP-8B06 | U12 | | 1 Torex | XC6192AA05ER-G | Torex | XC6192AA10ER-G

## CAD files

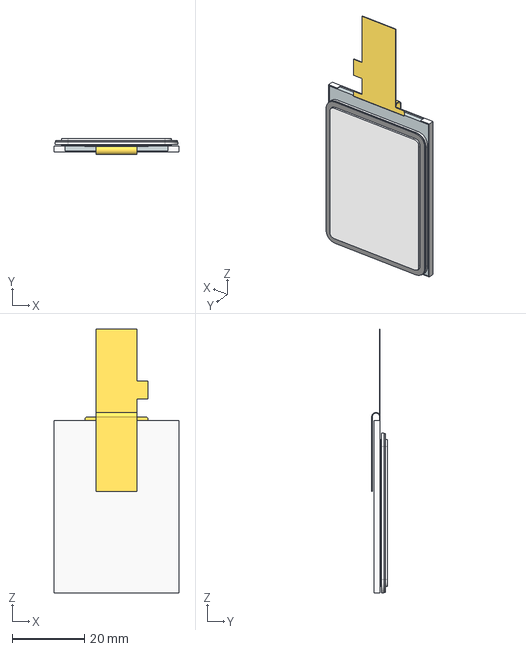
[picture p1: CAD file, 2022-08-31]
mechanical/STEP Files/FD-KL-ASM-FG-DISPLAY-LCD-IPS-2-INCH.stp
34.6 x 4.34 x 73.2 mm

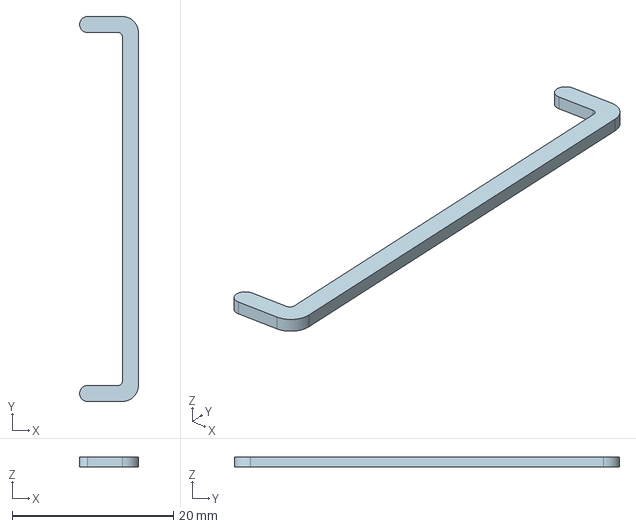
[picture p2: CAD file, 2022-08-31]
mechanical/STEP Files/FD-KL-DISPLAY-BACKER-REV-A.stp
7.30 x 47.8 x 1.20 mm

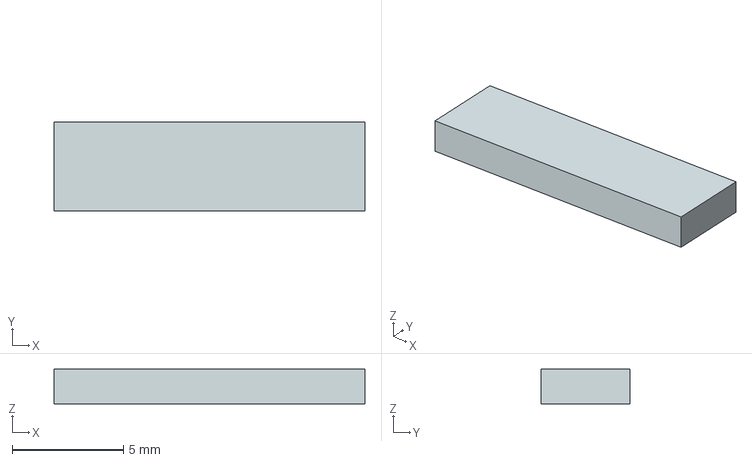
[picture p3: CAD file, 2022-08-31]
mechanical/STEP Files/FD-KL-FOAM-KEYPAD-REV-D.stp
14.0 x 4.00 x 1.57 mm

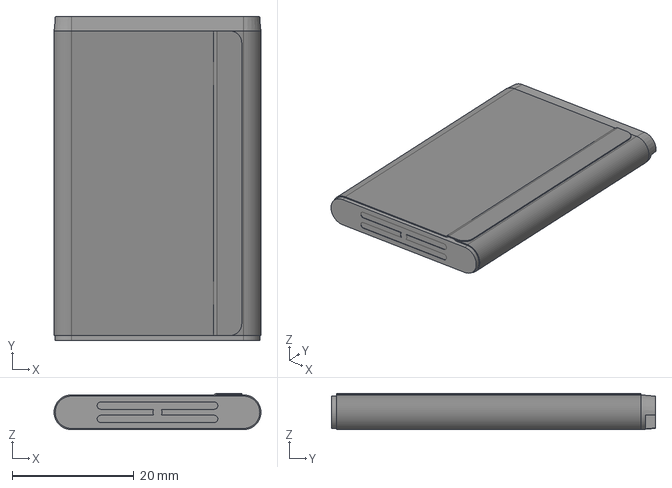
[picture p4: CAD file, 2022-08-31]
mechanical/STEP Files/FD-KL-BATTERY-LITHIUM-RECHARGEABLE.stp
34.0 x 53.1 x 5.95 mm

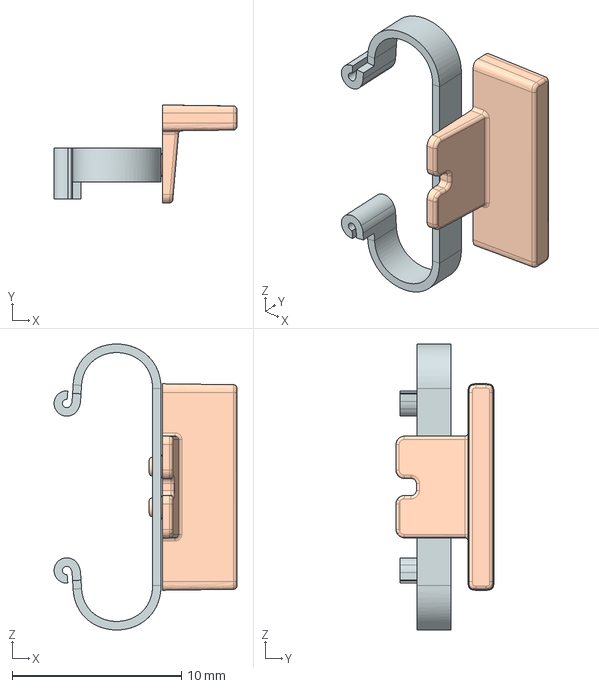
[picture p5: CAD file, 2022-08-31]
mechanical/STEP Files/FD-KL-ACTUATOR-BUTTON-POWER-REV-B.stp
10.8 x 5.79 x 16.9 mm

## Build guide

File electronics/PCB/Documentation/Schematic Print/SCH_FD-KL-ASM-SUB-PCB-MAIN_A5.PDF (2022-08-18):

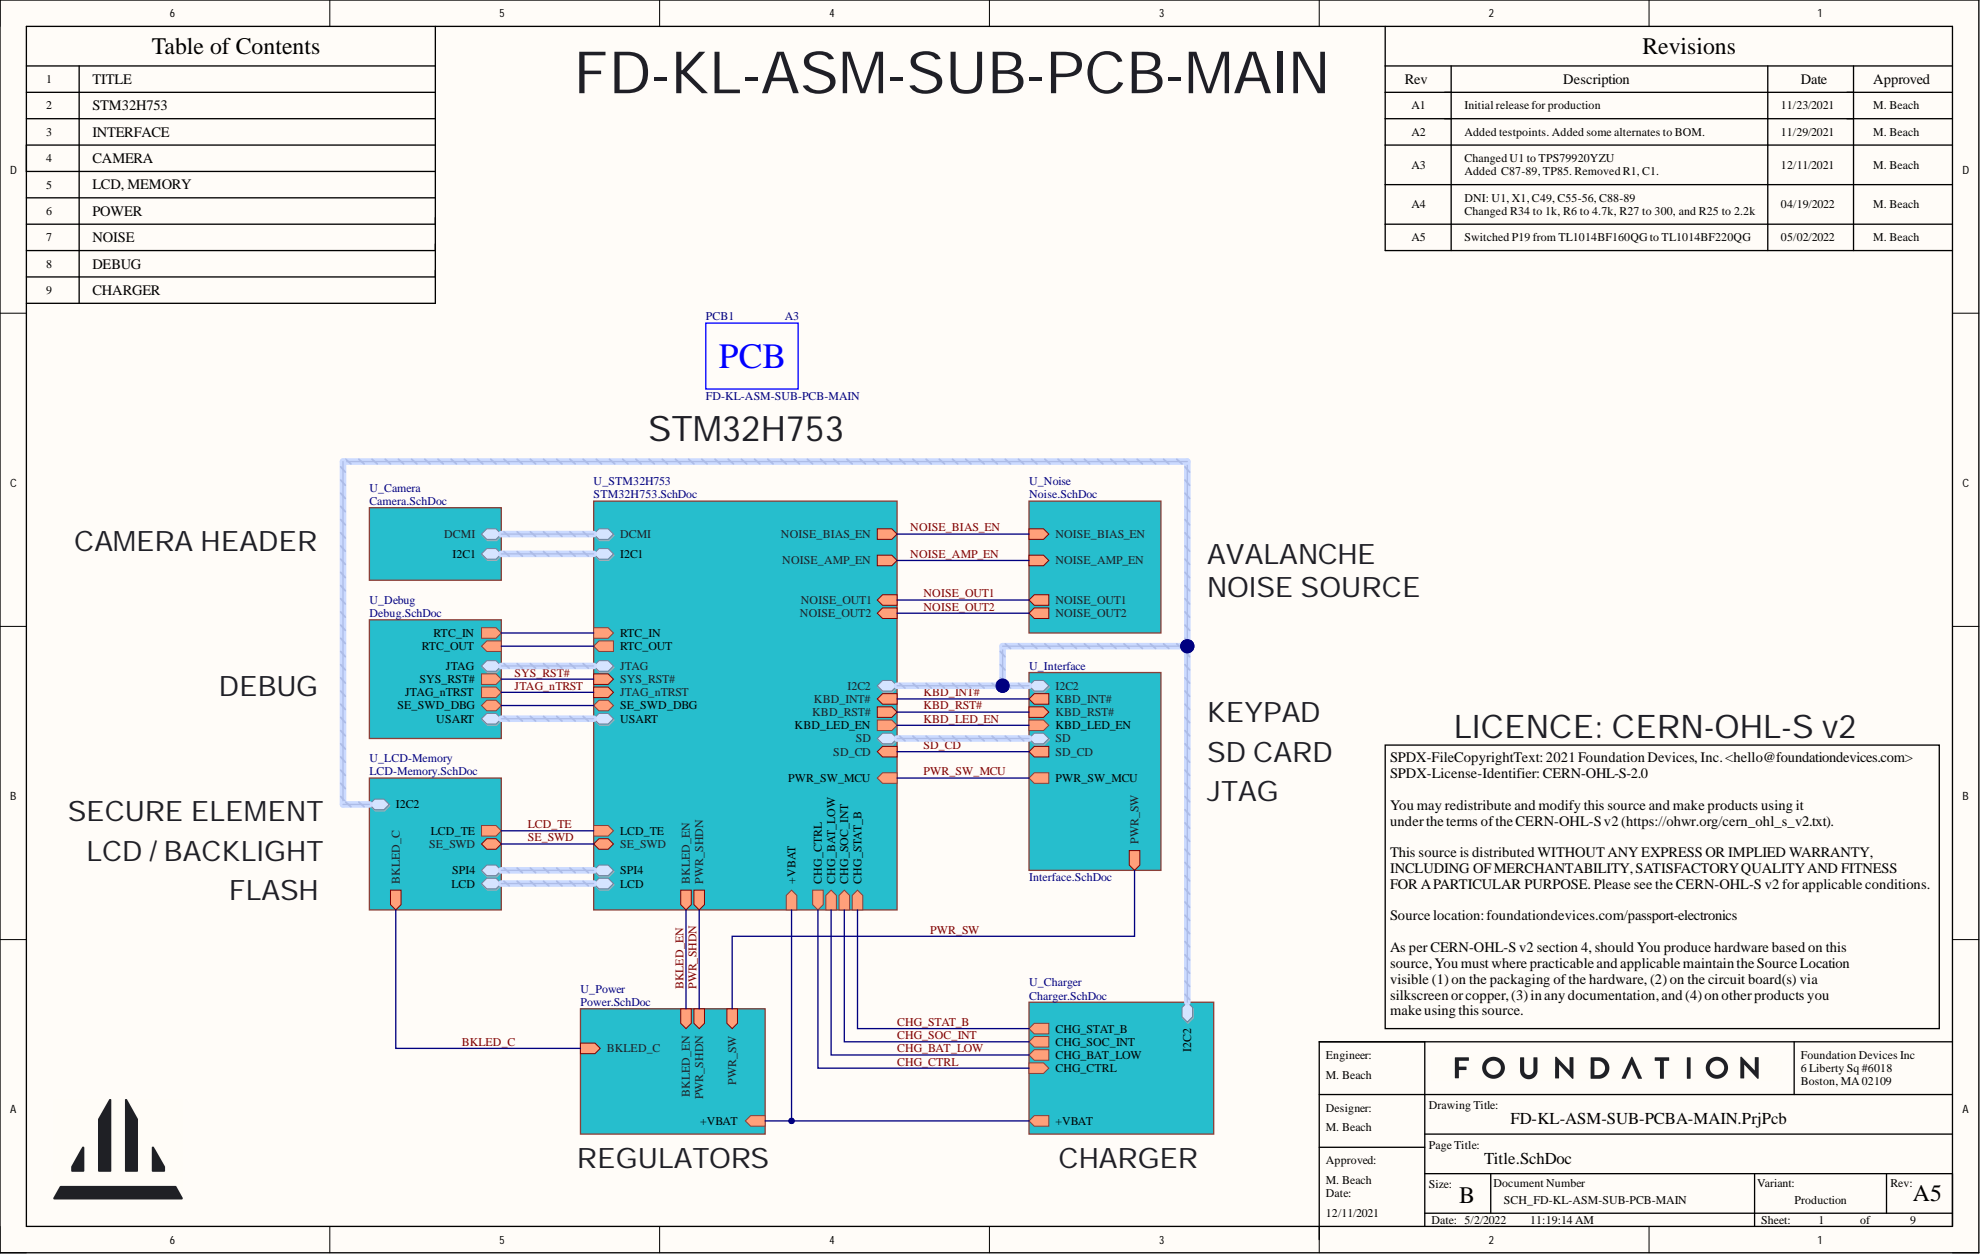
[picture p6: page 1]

Table of Contents | PCB1 A3 | Revisions

FD-KL-ASM-SUB-PCB-MAIN

TITLE | | Rev | Description | Date | Approved

STM32H753 | | A1 | Initial release for production | 11/23/2021 | M. Beach

3 | INTERFACE | | A2 | Added testpoints. Added some alternates to BOM. | 11/29/2021 | M. Beach

4 | CAMERA | | | Changed U1 to TPS79920YZU A3 | 12/11/2021 | M. Beach Added C87-89, TP85. Removed R1, C1.

5 | LCD, MEMORY

A4 | Changed R34 to 1k, R6 to 4.7k, R27 to 300, and R25 to 2.2k | 04/19/2022 | M. Beach DNI: U1, X1, C49, C55-56, C88-89

6 | POWER

7 | NOISE | | A5 | Switched P19 from TL1014BF160QG to TL1014BF220QG | 05/02/2022 | M. Beach

8 | DEBUG

9 | CHARGER

STM32H753

SPDX-FileCopyrightText: 2021 Foundation Devices, Inc. <hello@foundationdevices.com>
SPDX-License-Identifier: CERN-OHL-S-2.0

You may redistribute and modify this source and make products using it
under the terms of theCERN-OHL-S v2 (https://ohwr.org/cern_ohl_s_v2.txt).

This source is distributed WITHOUT ANY EXPRESS OR IMPLIED WARRANTY,
INCLUDING OF MERCHANTABILITY, SATISFACTORYQUALITY AND FITNESS
FOR APARTICULAR PURPOSE. Please see the CERN-OHL-S v2 for applicable conditions.

Source location: foundationdevices.com/passport-electronics

As per CERN-OHL-S v2 section 4, should You produce hardware based on this
source, You must where practicable and applicablemaintain the Source Location
visible (1) on the packaging of the hardware, (2) on the circuit board(s) via
silkscreen or copper, (3) in any documentation, and (4) on other products you
make using this source.

FD-KL-ASM-SUB-PCBA-MAIN.PrjPcb

B Size: | Document Number SCH_FD-KL-ASM-SUB-PCB-MAIN | Variant: Production | Rev: A5

Date: 5/2/2022 11:19:14 AM | | Sheet: 1 of 9

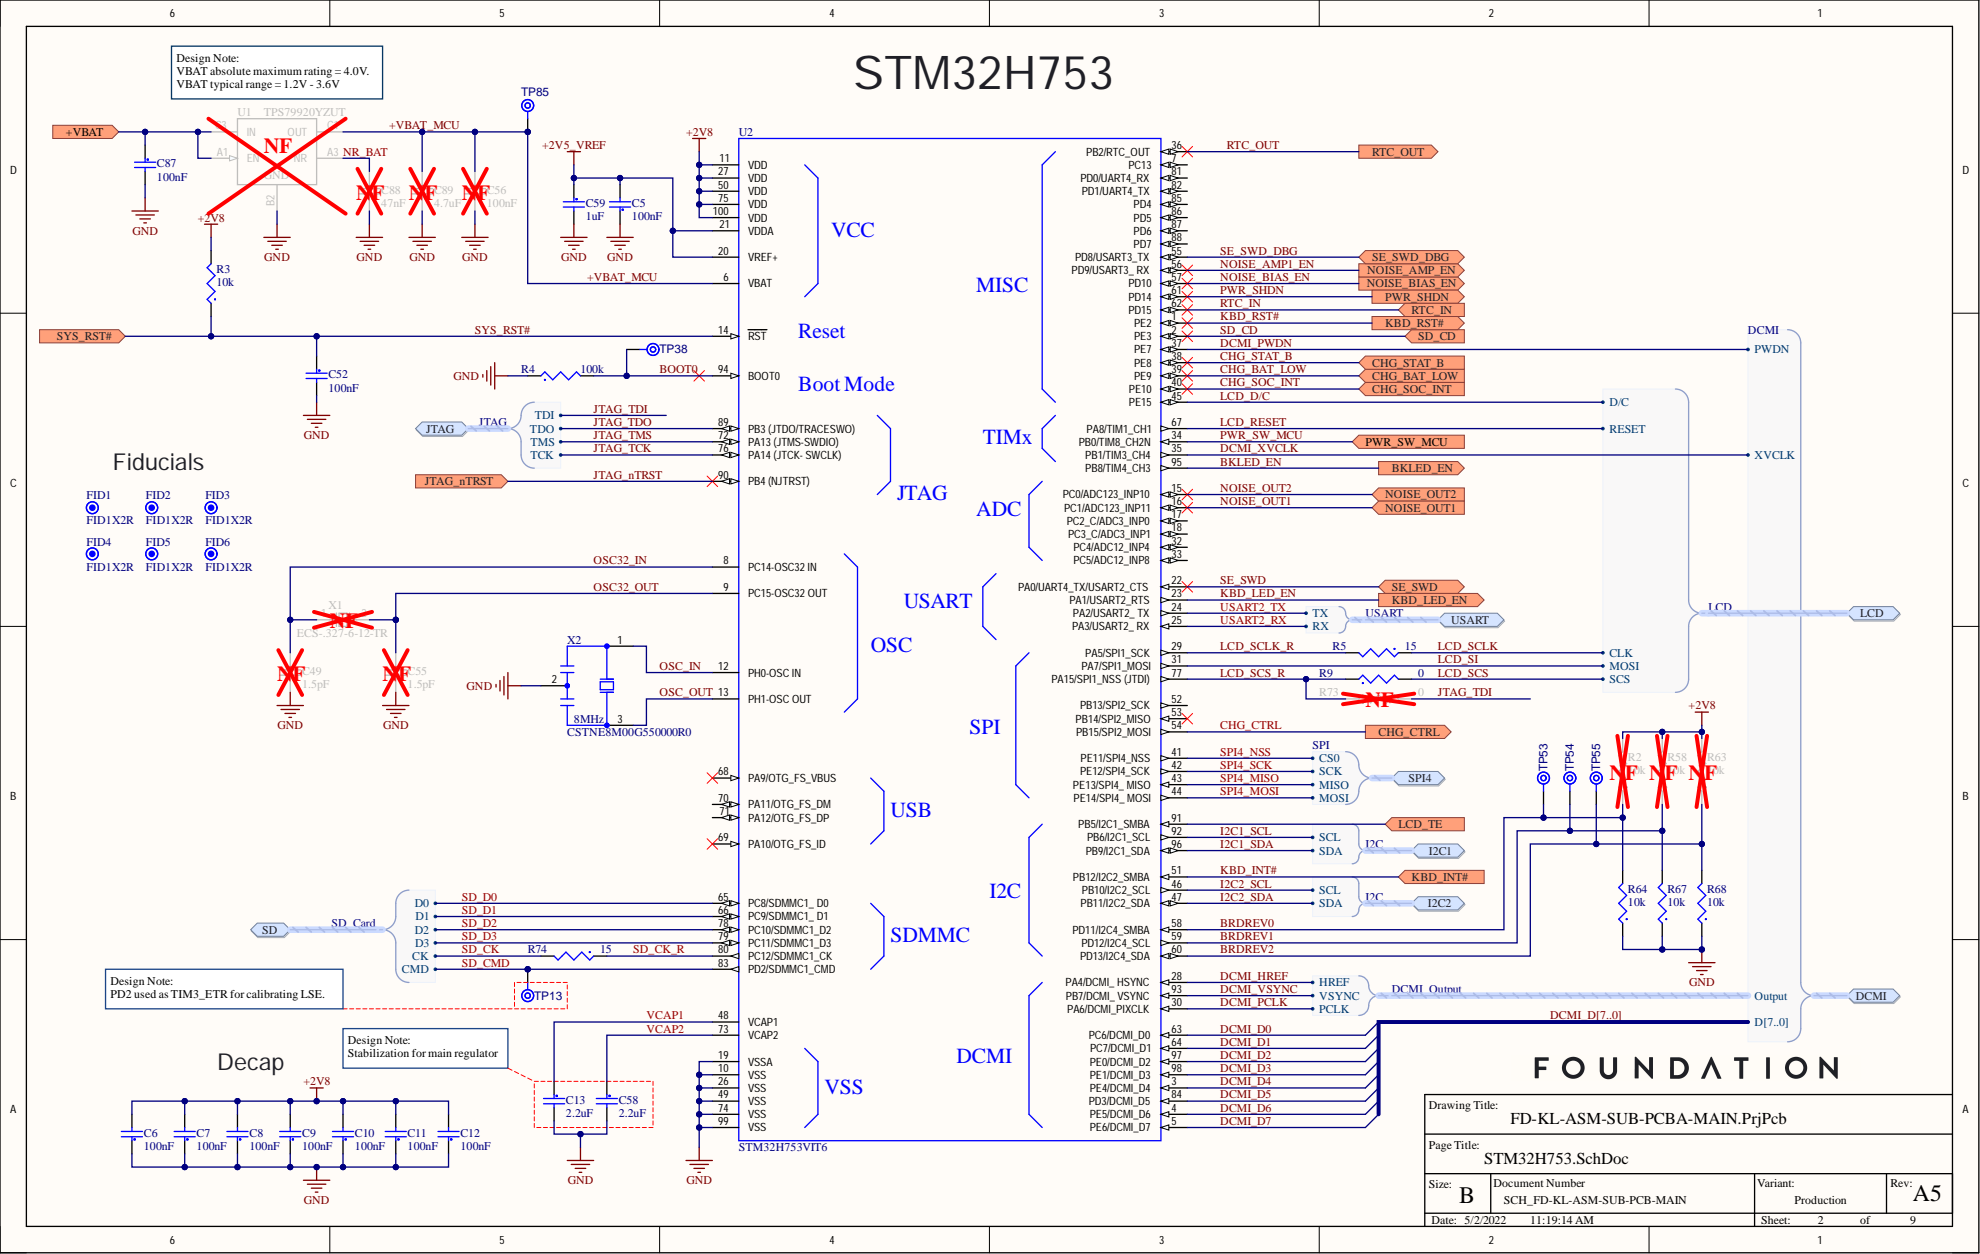
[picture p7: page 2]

OSC3 2 _ O U T

1 X 2 | PH0-OSC IN 12

VCA P 2 | VCAP2 73

VSSA 19

FD-KL-ASM-SUB-PCBA-MA

B Size : | D ocumen N umb er SCH _FD-K L-ASM-SUB-PCB-MA IN | Varian t Pro d uct i o n | Rev

Dat e / 2 A M | | Sheet f

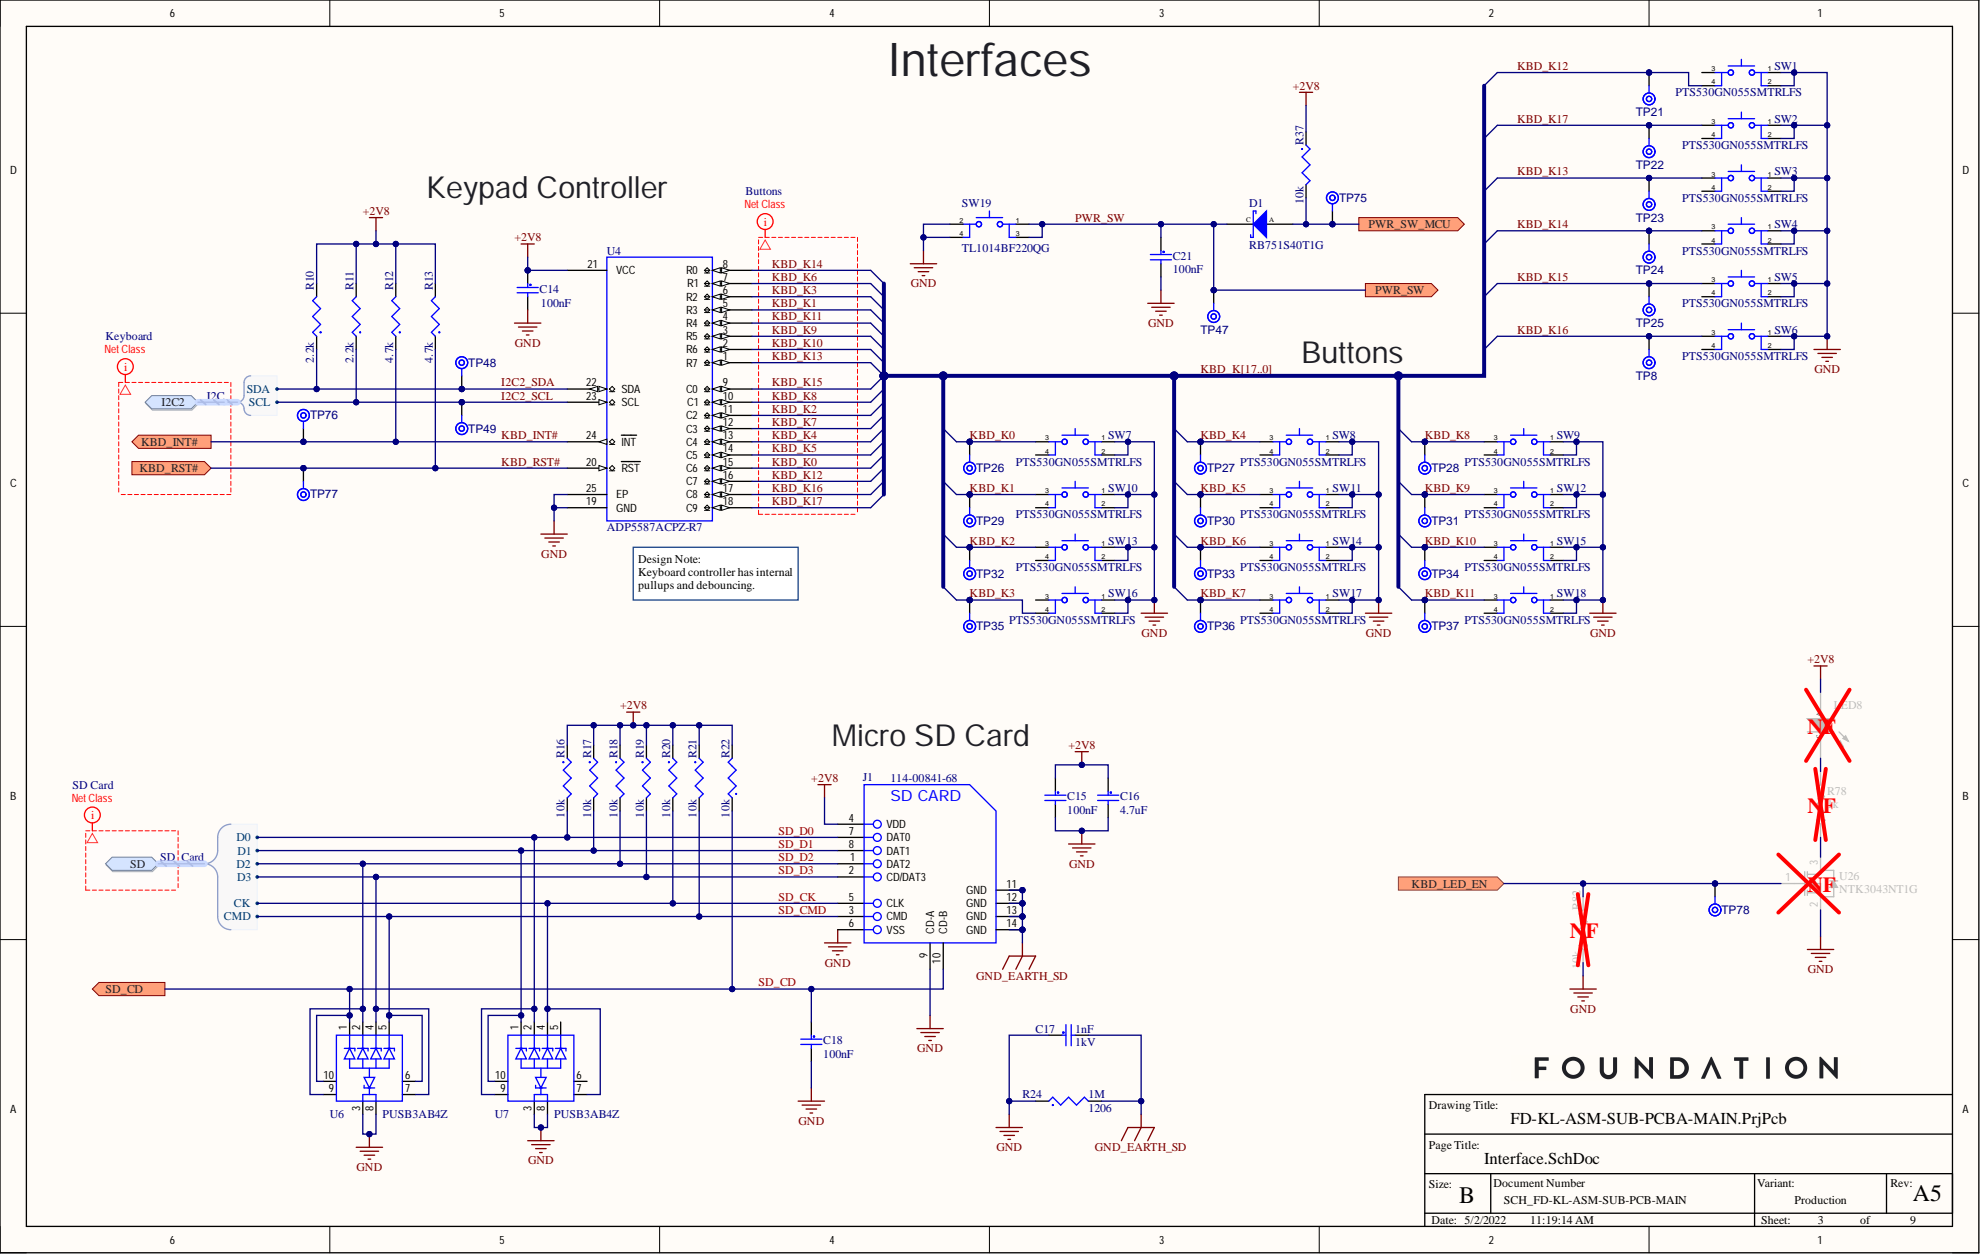
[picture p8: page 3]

Design Note:
Keyboard controller has internal
pullups and debouncing.

FD-KL-ASM-SUB-PCBA-MAIN.PrjPcb

B | | Rev: A5 Variant:

Date: 5/2/2022 11:19:14 AM | Sheet: 3 of 9

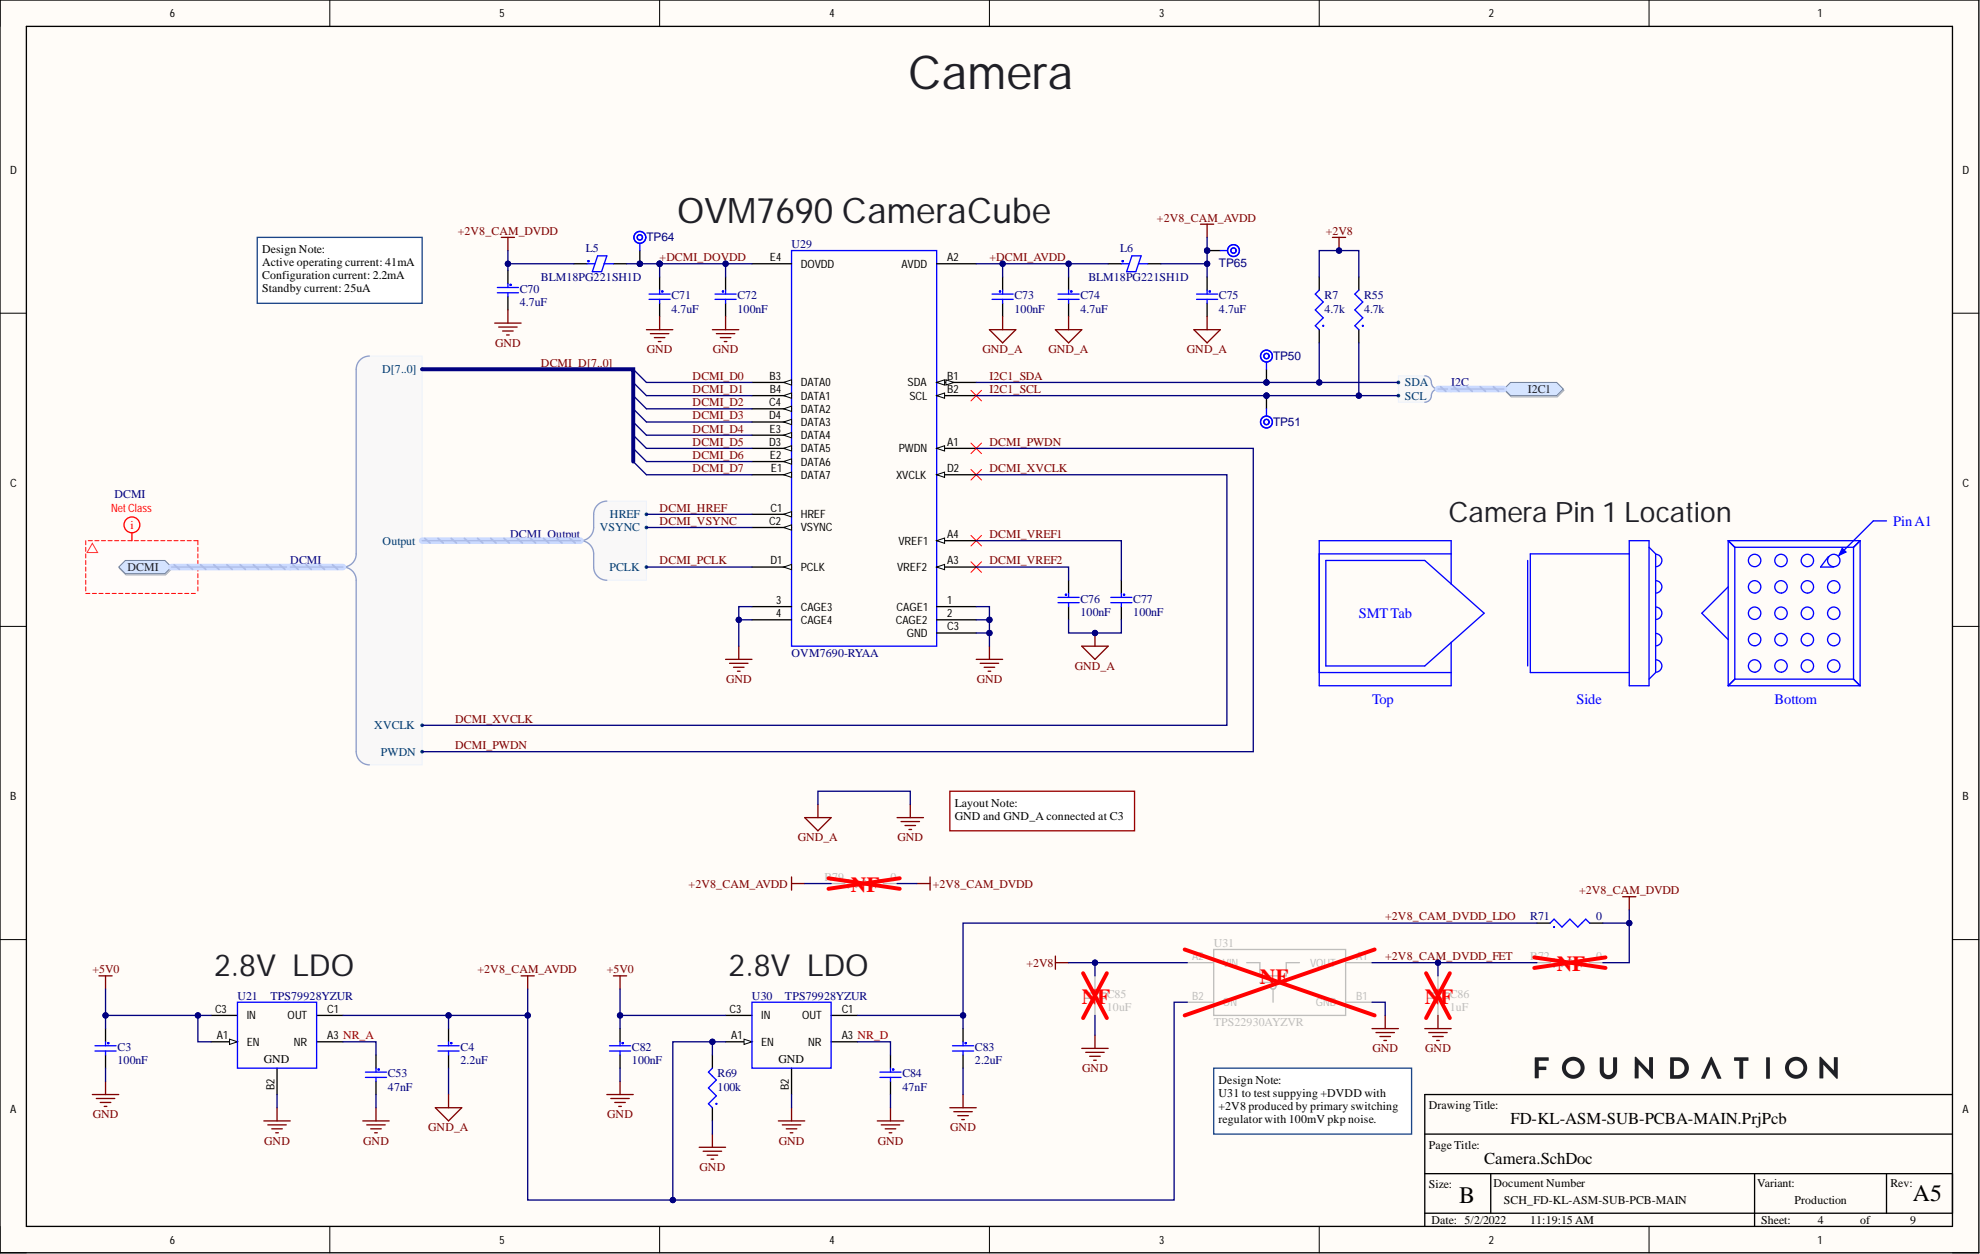
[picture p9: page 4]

DCMI_D7 | DATA7 E1 DATA6 E2 XVCLK | D2 DCMI_XVCLK

DCMI_XVCLK | HREF C1 VSYNC C2 VREF1 PCLK D1 CAGE2 | A4 DCMI_VREF1 2 CAGE3 3

Layout Note:
GND and GND_A connected at C3

Design Note:
U31 to test suppying +DVDD with
+2V8 produced by primary switching
regulator with 100mV pkp noise.

FD-KL-ASM-SUB-PCBA-MAIN.PrjPcb

B | | Rev: A5 Variant:

Date: 5/2/2022 11:19:15 AM | Sheet: 4 of 9

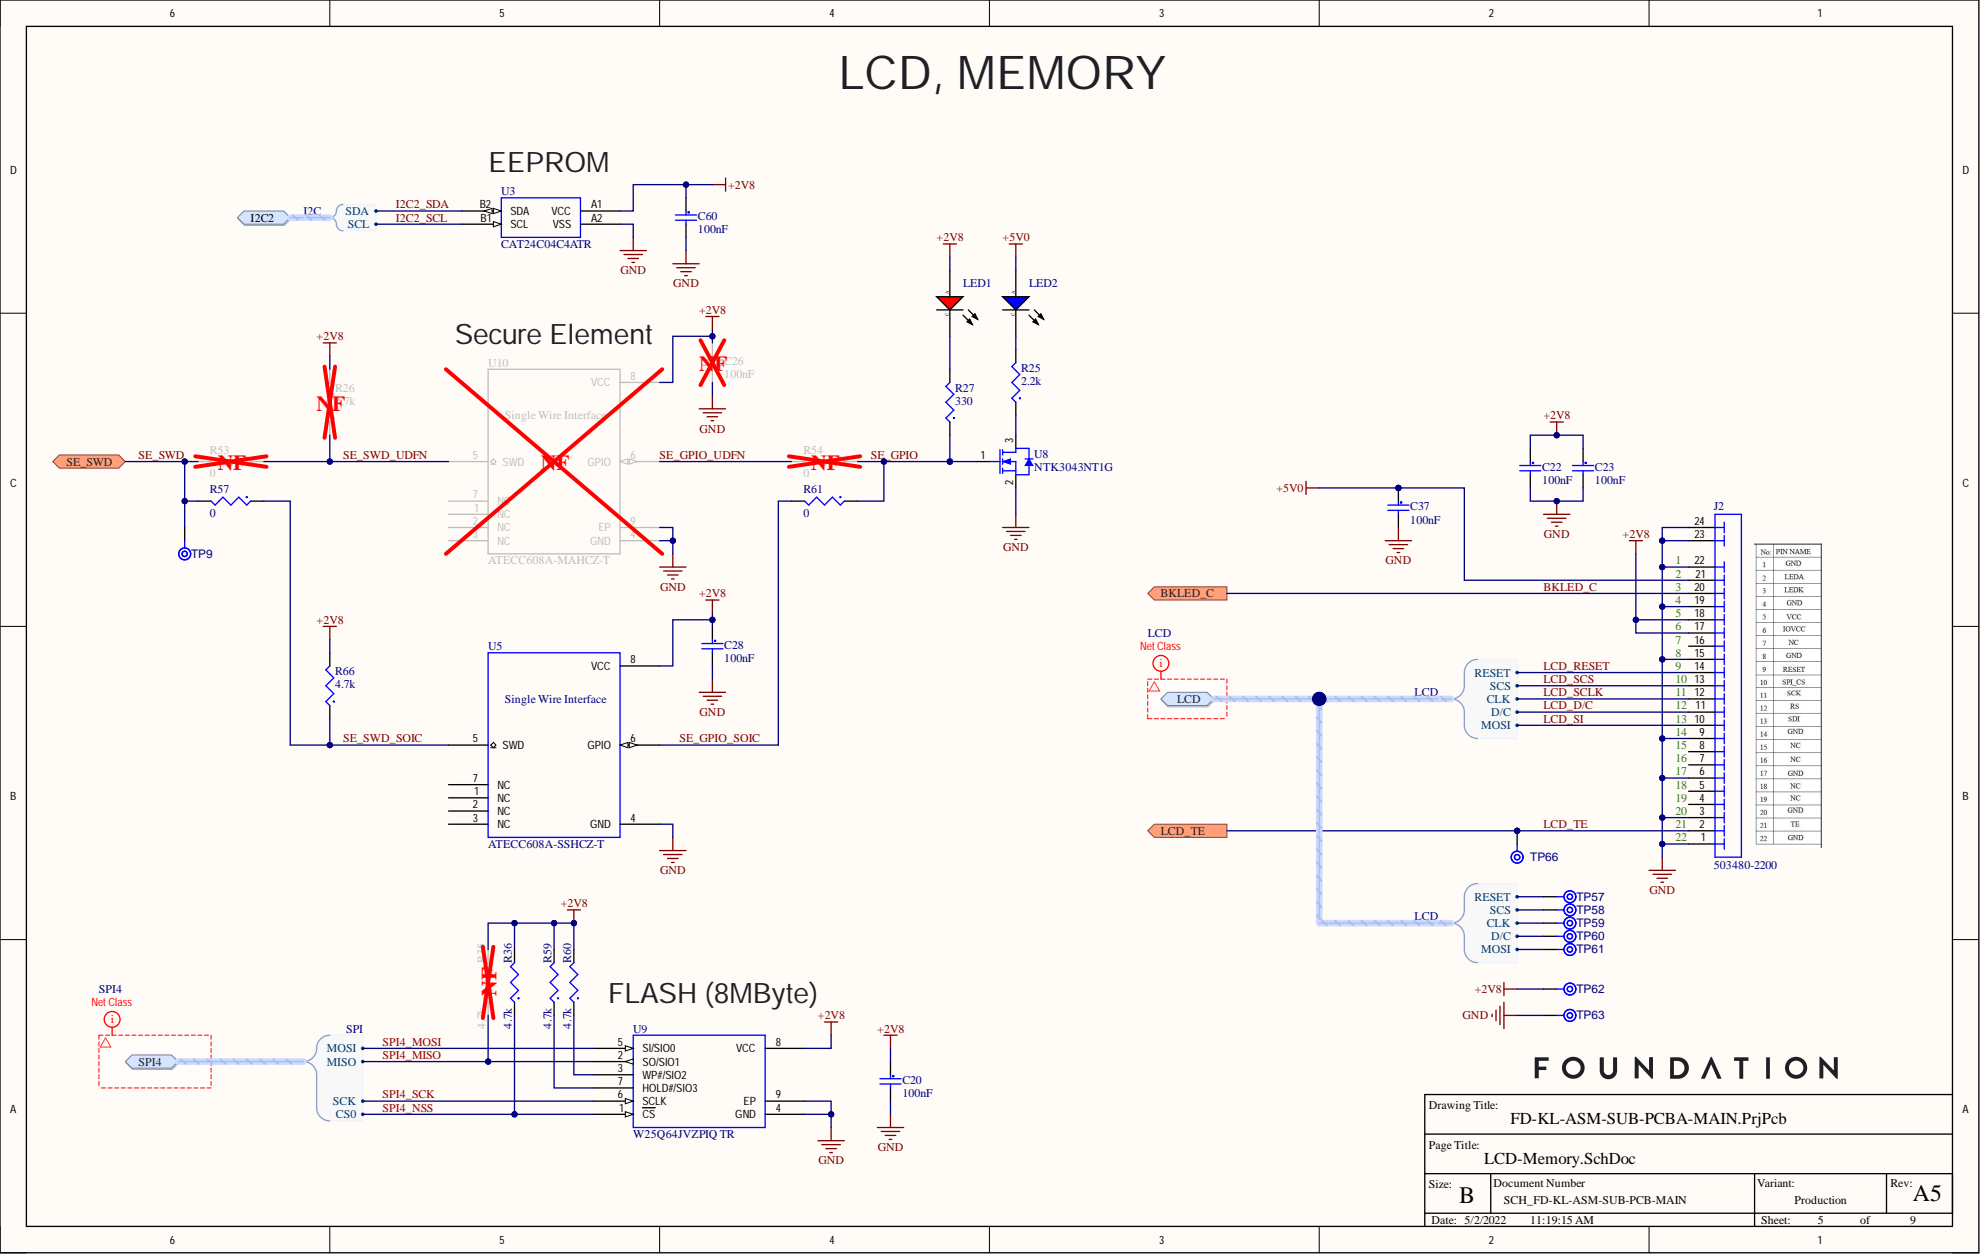
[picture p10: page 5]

2 1
2 2

FD-KL-ASM-SUB-PCBA-MA

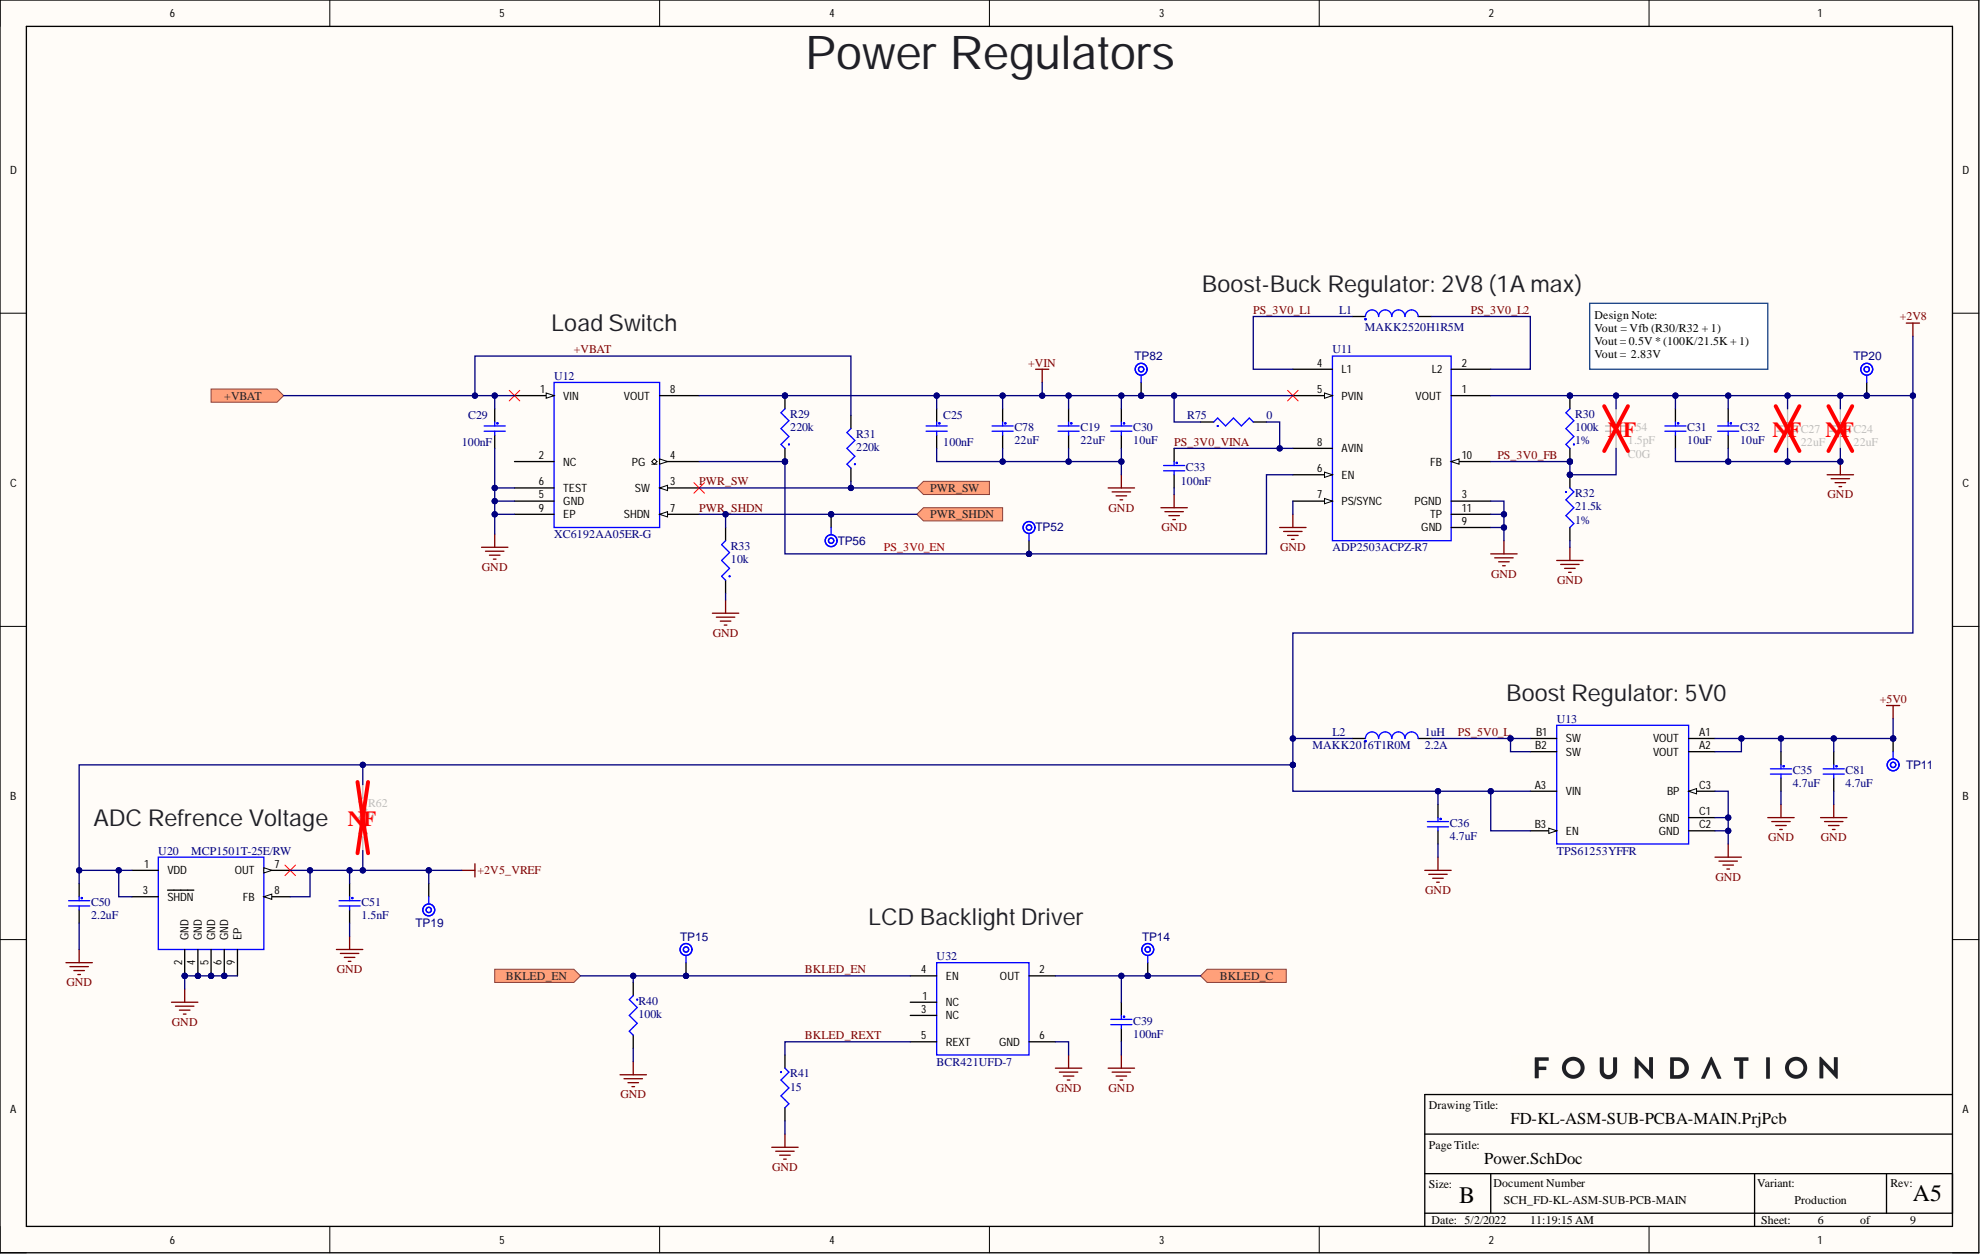
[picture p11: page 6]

Boost-Buck Regulator: 2V8 (1A max)

AVIN 8 | 100k C32 C27 +5V0

SW B2 GND

ADC Refrence Voltage NF

FD-KL-ASM-SUB-PCBA-MAIN.PrjPcb

B | | Rev: A5 Variant:

Date: 5/2/2022 11:19:15 AM | Sheet: 6 of 9

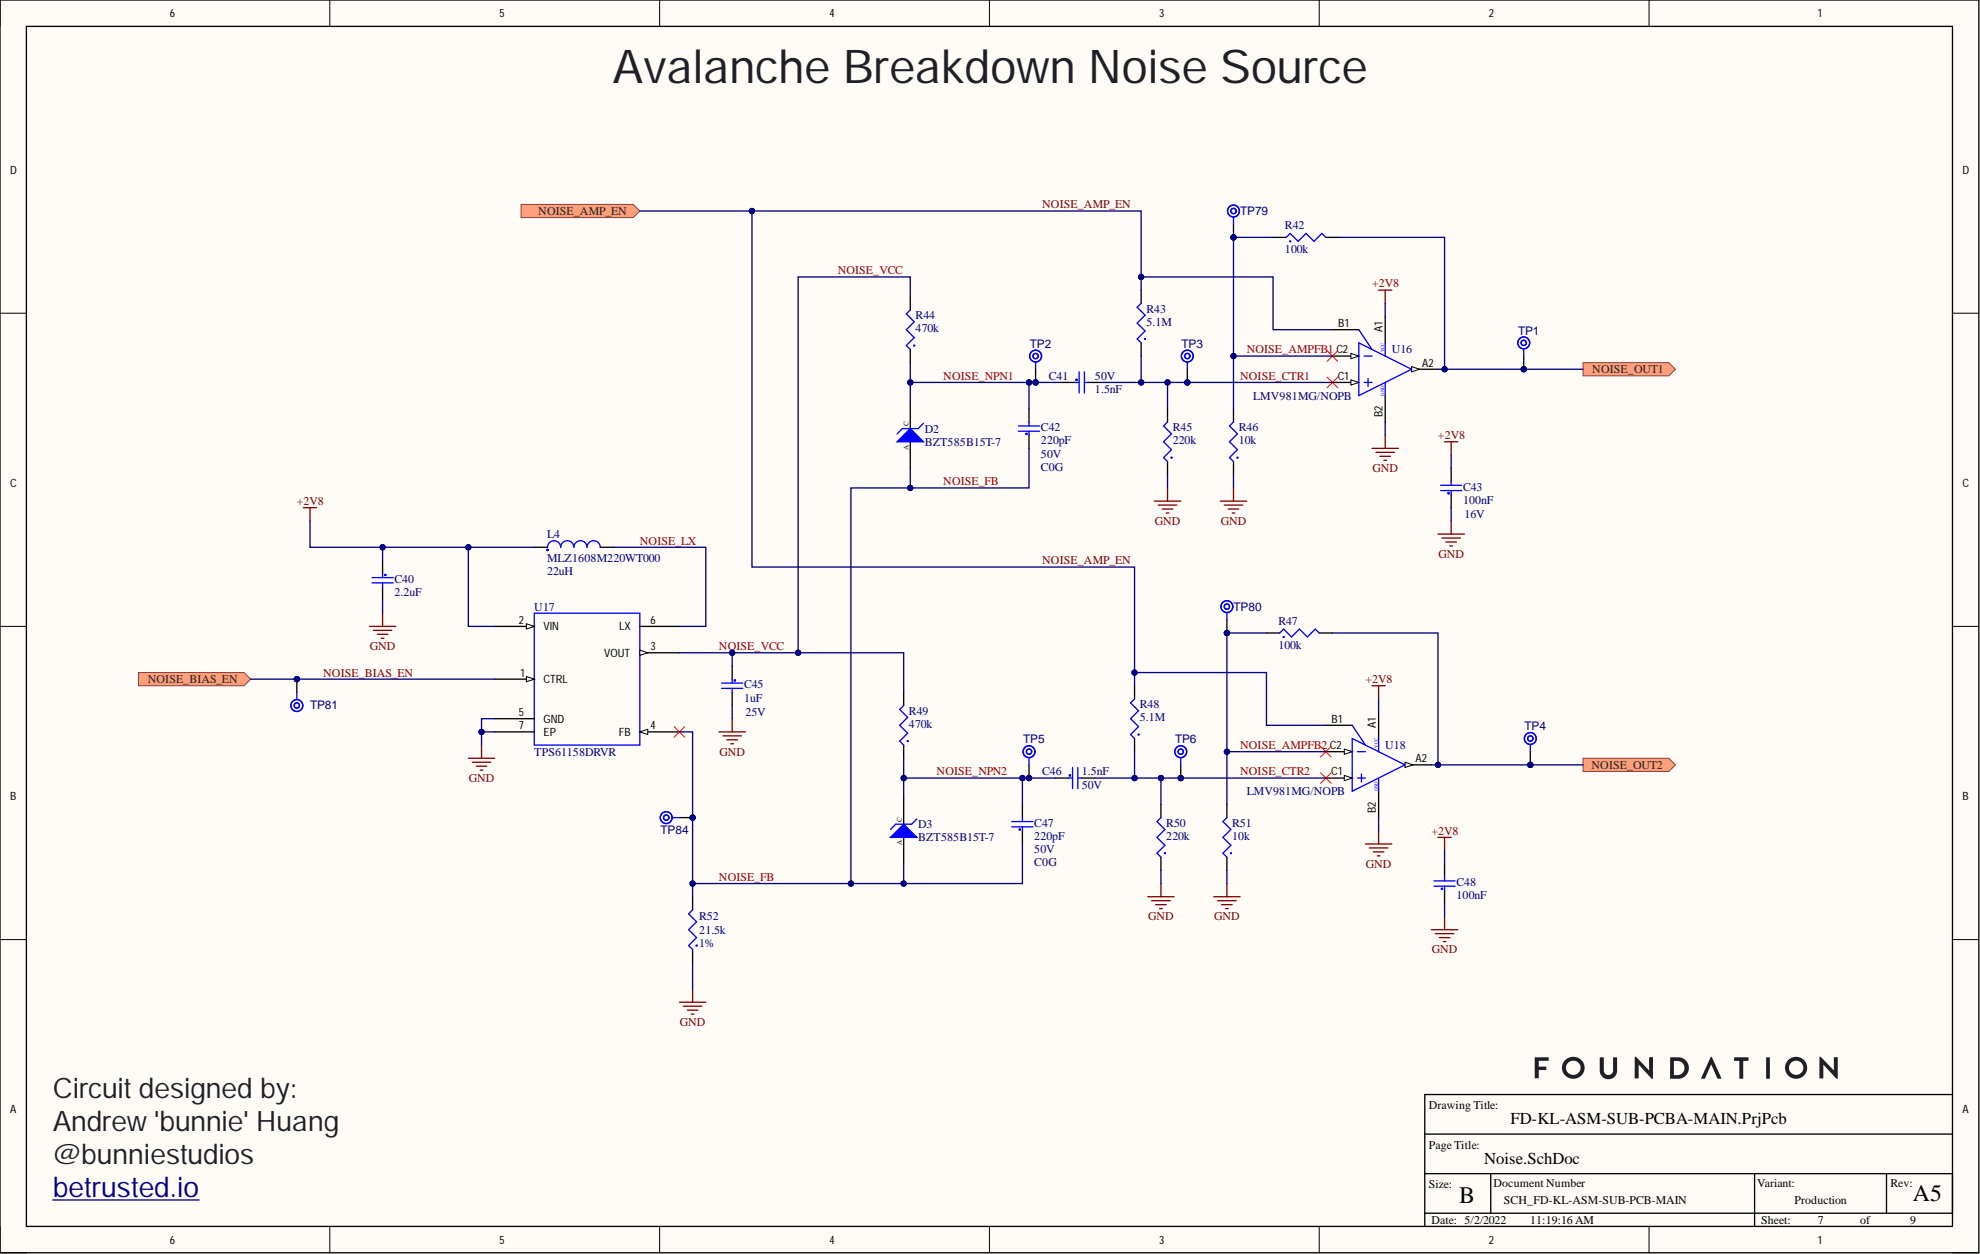
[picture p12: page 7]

Avalanche Breakdown Noise Source

N OISE _ V C C

N OISE | _ AMPF B 1

N OISE _CT R 1

N OISE | _ AMPF B 2

N OISE _CT R 2

D 3 | | | LMV 9 8 1MG/ N

FD-KL-ASM-SUB-PCBA-MA

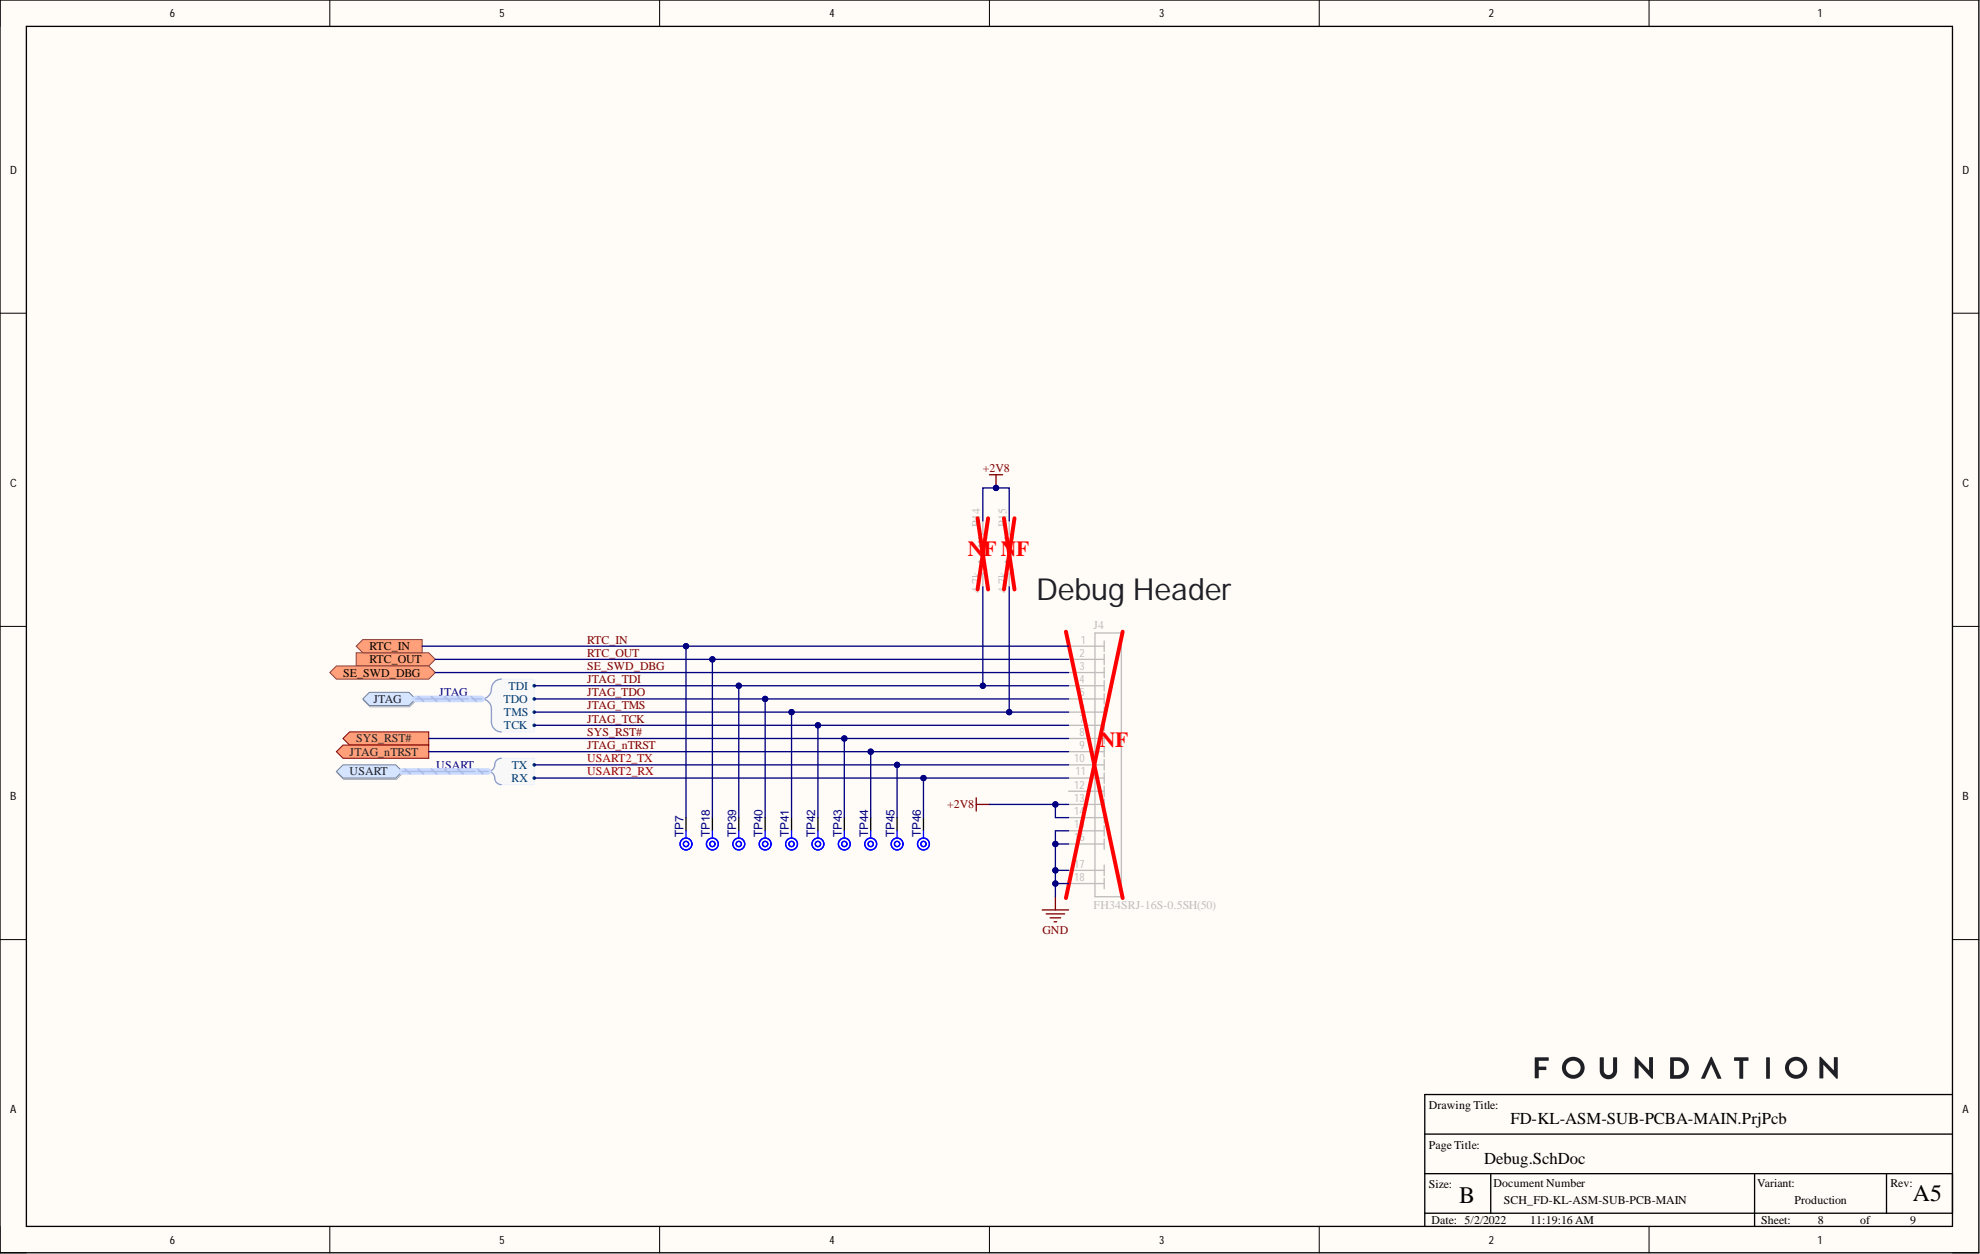
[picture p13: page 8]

FD-KL-ASM-SUB-PCBA-MA

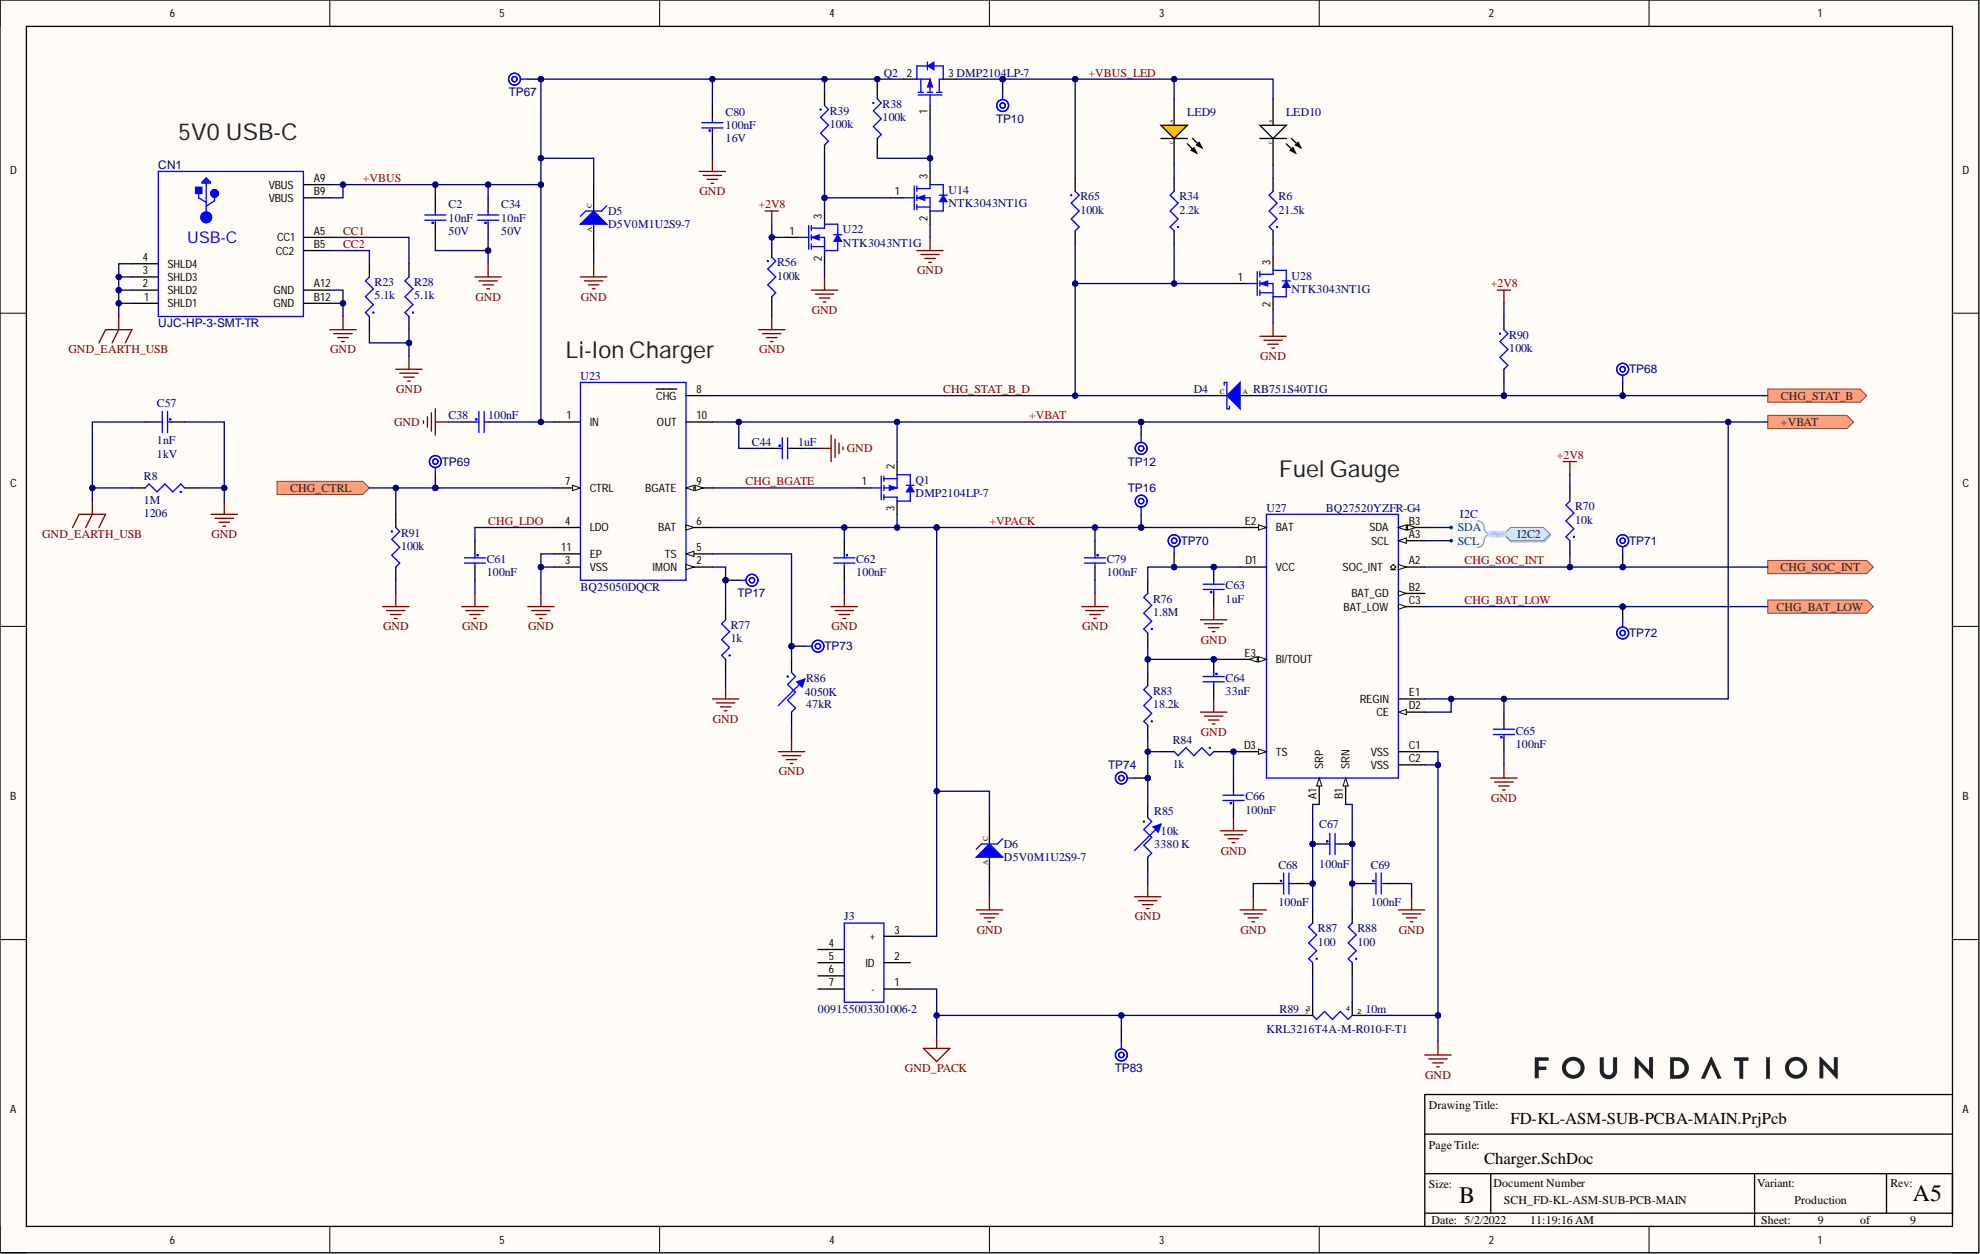
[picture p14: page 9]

FD-KL-ASM-SUB-PCBA-MA

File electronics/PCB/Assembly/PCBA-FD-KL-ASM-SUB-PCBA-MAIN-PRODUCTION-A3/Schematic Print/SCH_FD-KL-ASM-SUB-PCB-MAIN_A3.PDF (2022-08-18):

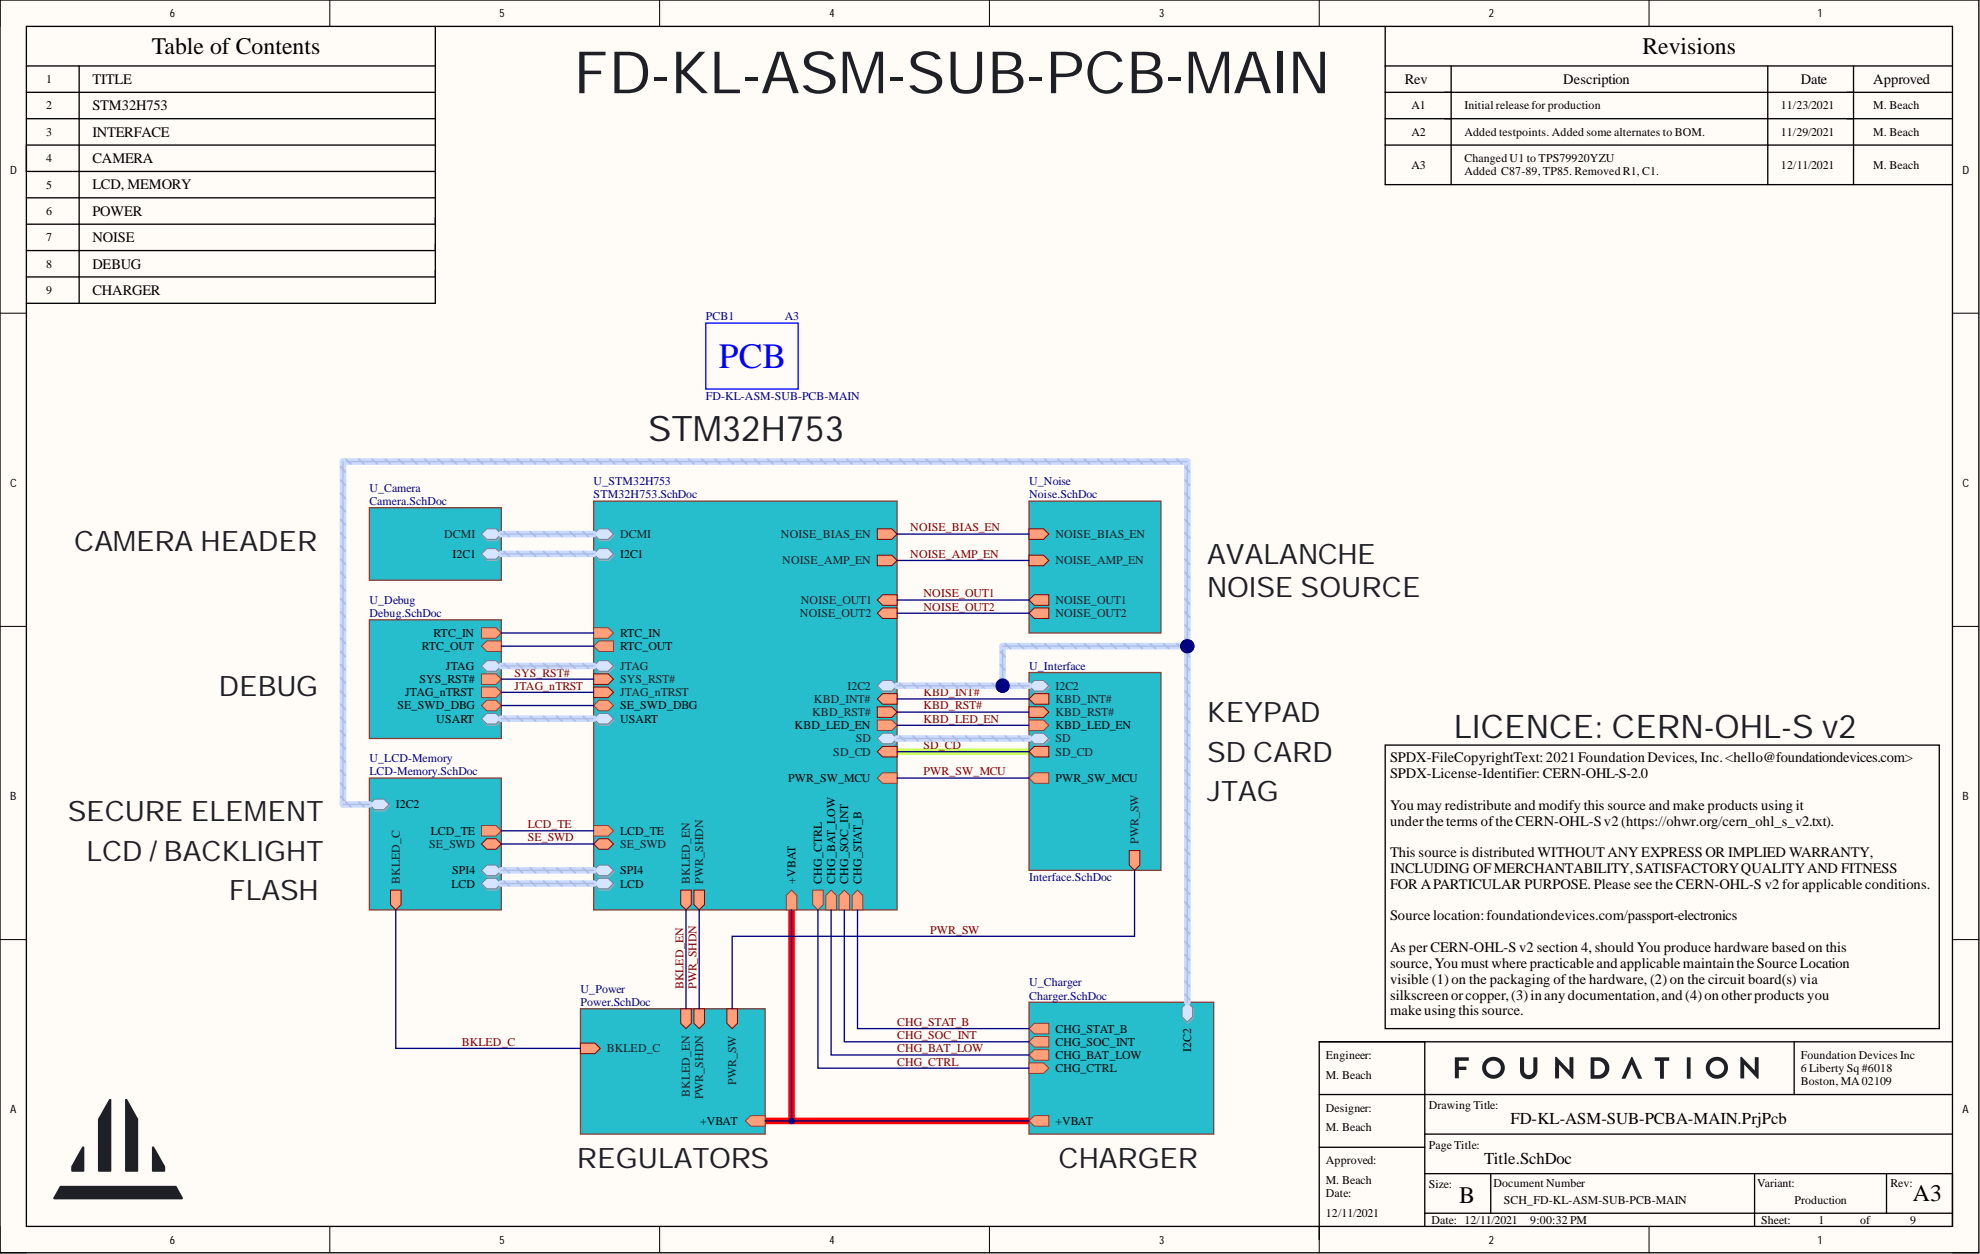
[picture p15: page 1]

Table of Contents | PCB1 A3 | Revisions

FD-KL-ASM-SUB-PCB-MAIN

TITLE | | Rev | Description | Date | Approved

STM32H753 | | A1 | Initial release for production | 11/23/2021 | M. Beach

3 | INTERFACE | | A2 | Added testpoints. Added some alternates to BOM. | 11/29/2021 | M. Beach

4 | CAMERA | | | Changed U1 to TPS79920YZU A3 | 12/11/2021 | M. Beach Added C87-89, TP85. Removed R1, C1.

5 | LCD, MEMORY

6 | POWER

7 | NOISE

8 | DEBUG

9 | CHARGER

STM32H753

SPDX-FileCopyrightText: 2021 Foundation Devices, Inc. <hello@foundationdevices.com>
SPDX-License-Identifier: CERN-OHL-S-2.0

You may redistribute and modify this source and make products using it
under the terms of theCERN-OHL-S v2 (https://ohwr.org/cern_ohl_s_v2.txt).

This source is distributed WITHOUT ANY EXPRESS OR IMPLIED WARRANTY,
INCLUDING OF MERCHANTABILITY, SATISFACTORYQUALITY AND FITNESS
FOR APARTICULAR PURPOSE. Please see the CERN-OHL-S v2 for applicable conditions.

Source location: foundationdevices.com/passport-electronics

As per CERN-OHL-S v2 section 4, should You produce hardware based on this
source, You must where practicable and applicablemaintain the Source Location
visible (1) on the packaging of the hardware, (2) on the circuit board(s) via
silkscreen or copper, (3) in any documentation, and (4) on other products you
make using this source.

FD-KL-ASM-SUB-PCBA-MAIN.PrjPcb

B Size: | Document Number SCH_FD-KL-ASM-SUB-PCB-MAIN | Variant: Production | Rev: A3

Date: 12/11/2021 9:00:32 PM | | Sheet: 1 of 9

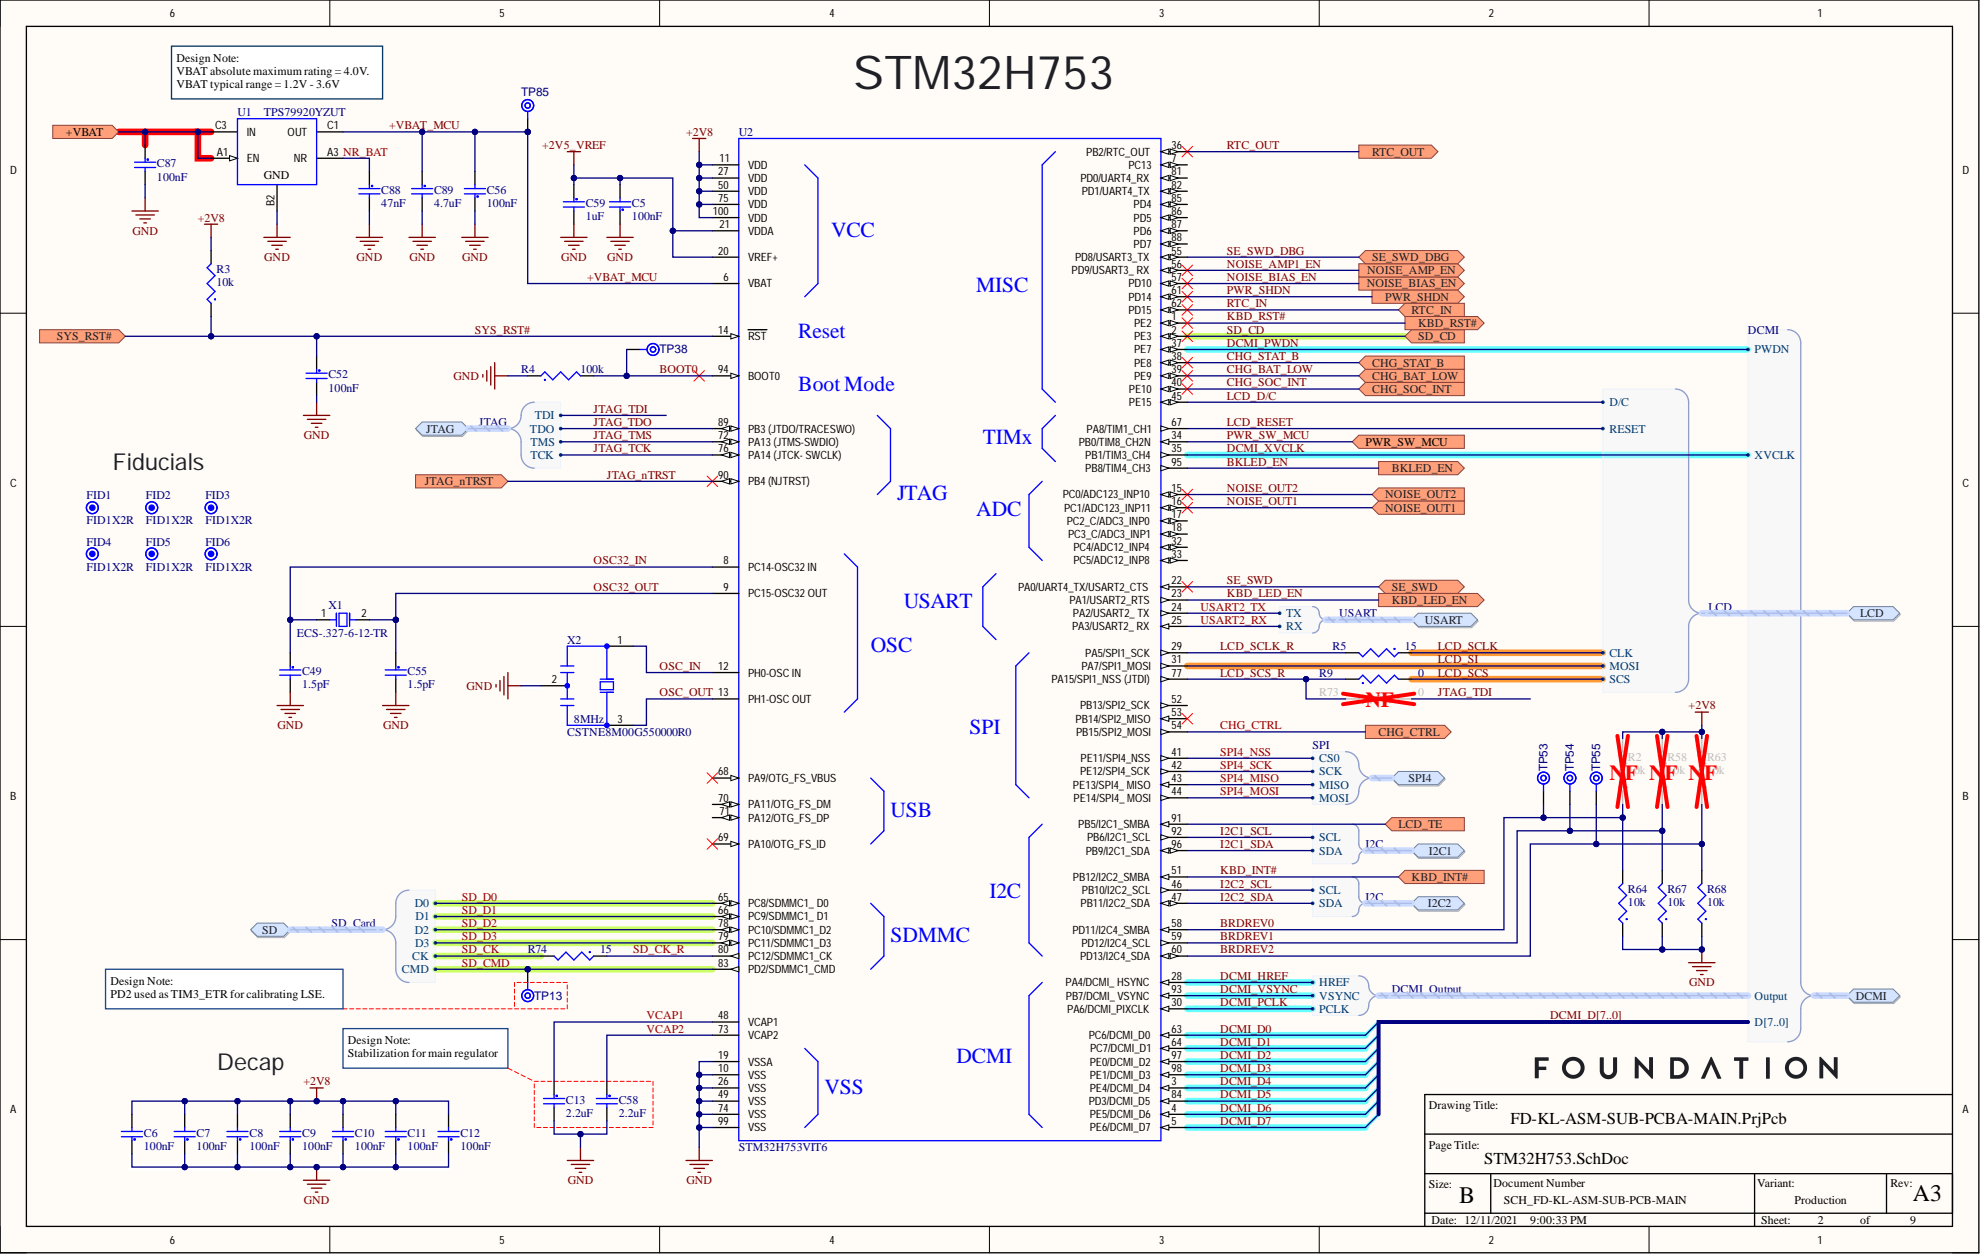
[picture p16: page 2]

OSC3 2 _ O U T

1 X 2 | PH0-OSC IN 12

VCA P 2 | VCAP2 73

VSSA 19

FD-KL-ASM-SUB-PCBA-MA

B Size : | D ocumen N umb er SCH _FD-K L-ASM-SUB-PCB-MA IN | Varian t Pro d uct i o n | Rev

Dat e / 1 PM | | Sheet f

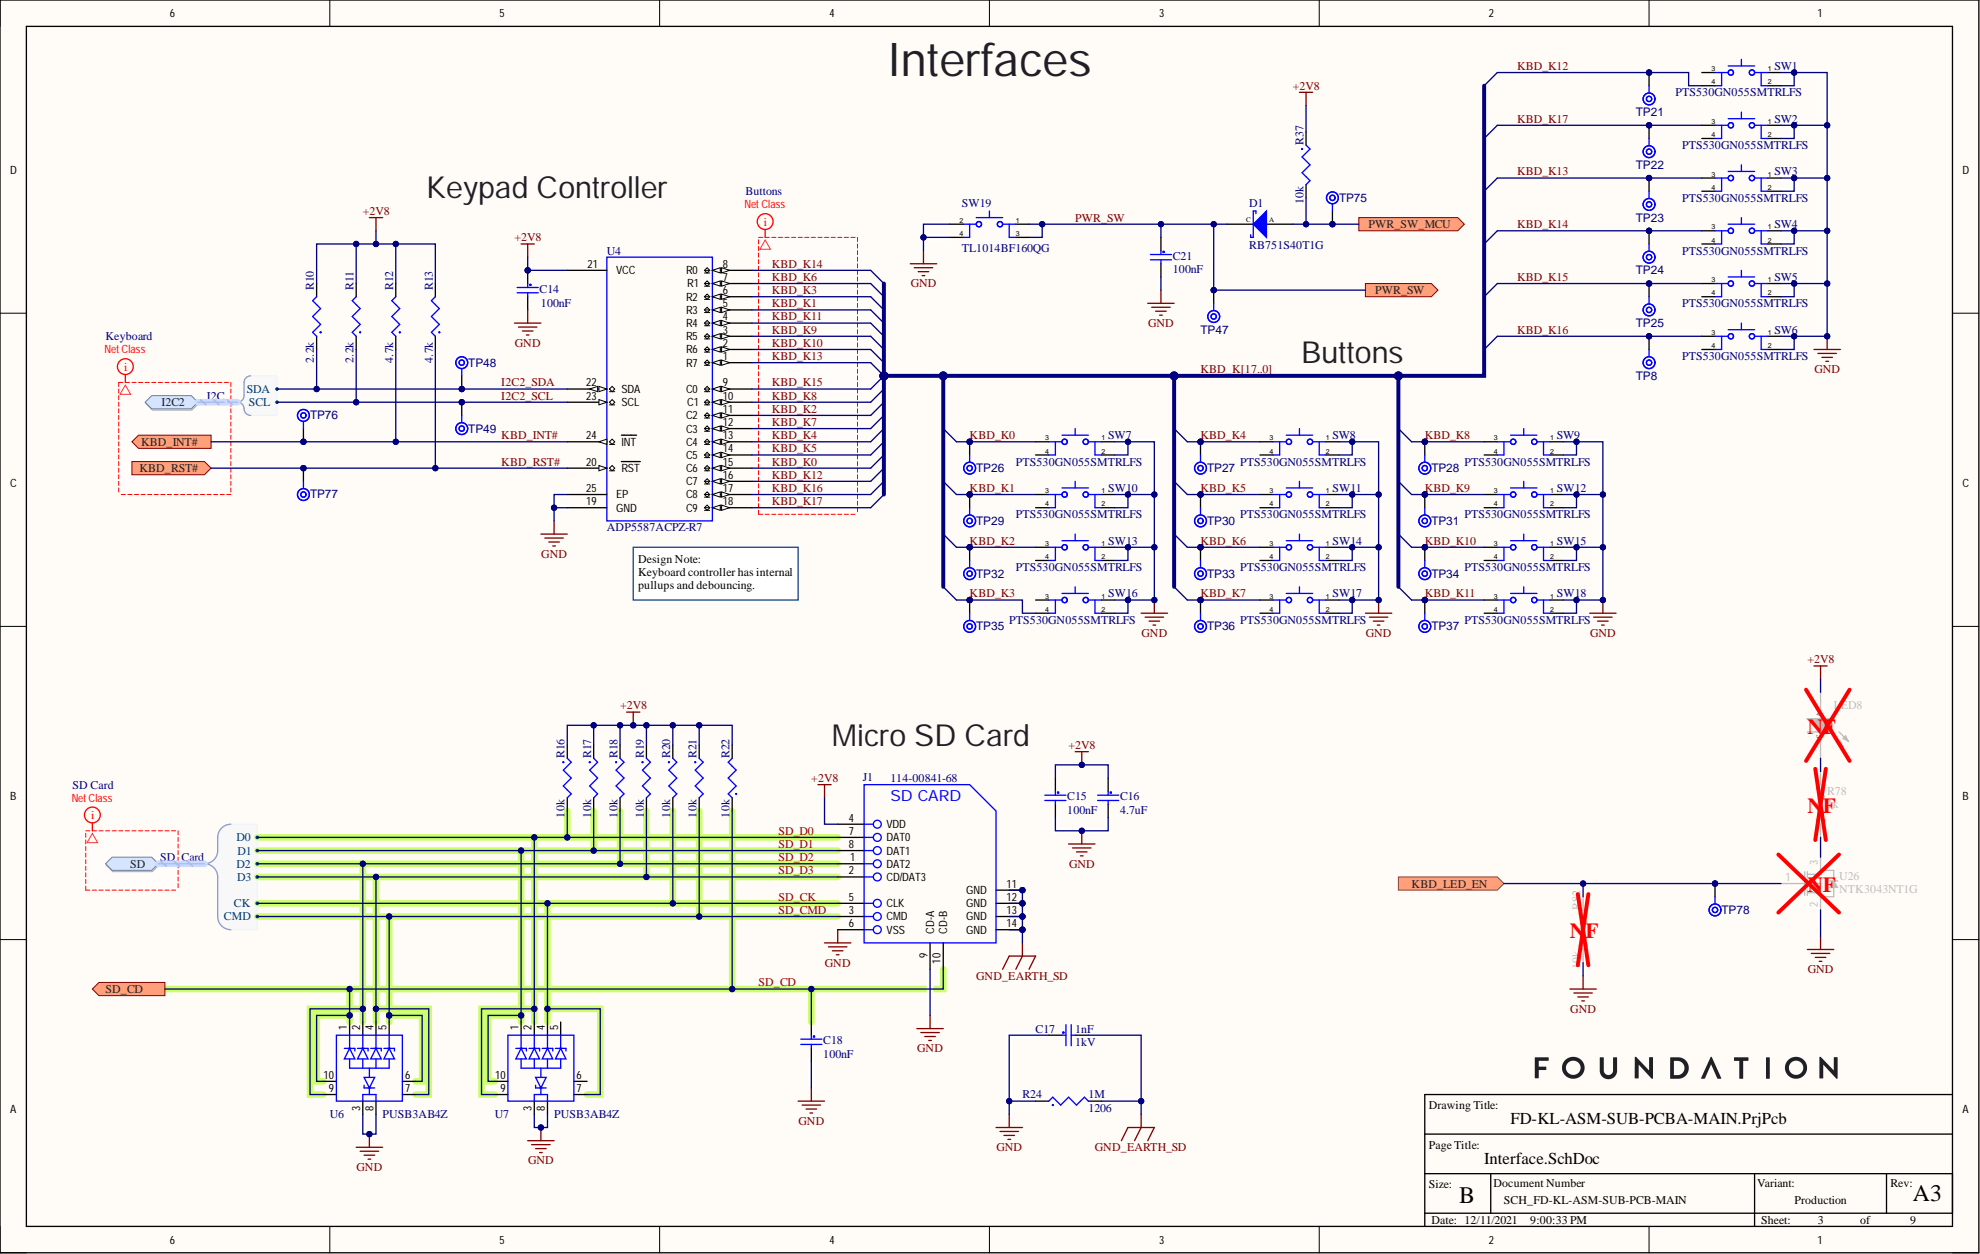
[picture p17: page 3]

Design Note:
Keyboard controller has internal
pullups and debouncing.

FD-KL-ASM-SUB-PCBA-MAIN.PrjPcb

B | | Rev: A3 Variant:

Date: 12/11/2021 9:00:33 PM | Sheet: 3 of 9

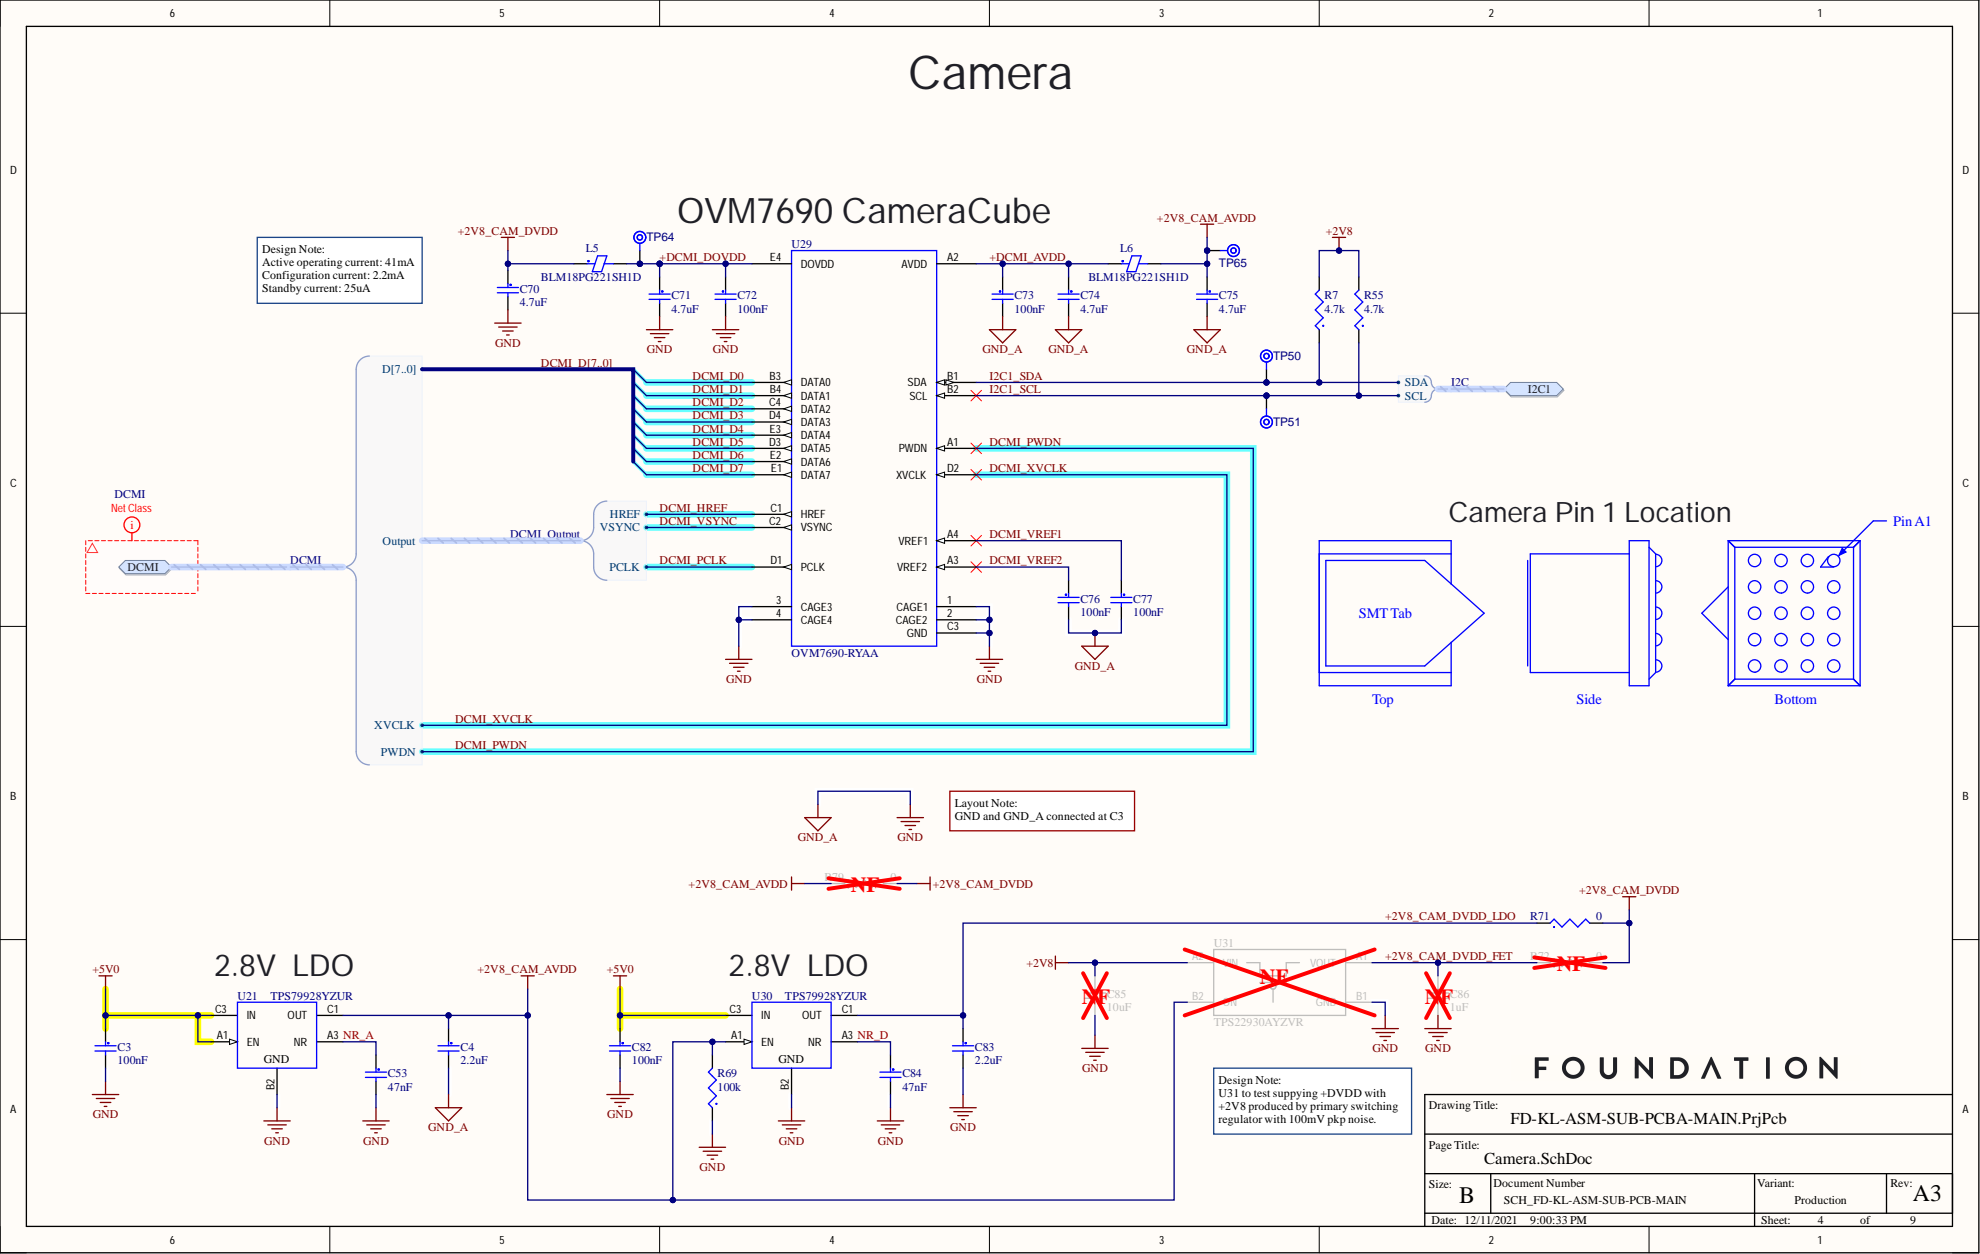
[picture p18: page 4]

DCMI_D7 | DATA7 E1 DATA6 E2 XVCLK | D2 DCMI_XVCLK

DCMI_XVCLK | HREF C1 VSYNC C2 VREF1 PCLK D1 CAGE2 | A4 DCMI_VREF1 2 CAGE3 3

Layout Note:
GND and GND_A connected at C3

Design Note:
U31 to test suppying +DVDD with
+2V8 produced by primary switching
regulator with 100mV pkp noise.

FD-KL-ASM-SUB-PCBA-MAIN.PrjPcb

B | | Rev: A3 Variant:

Date: 12/11/2021 9:00:33 PM | Sheet: 4 of 9

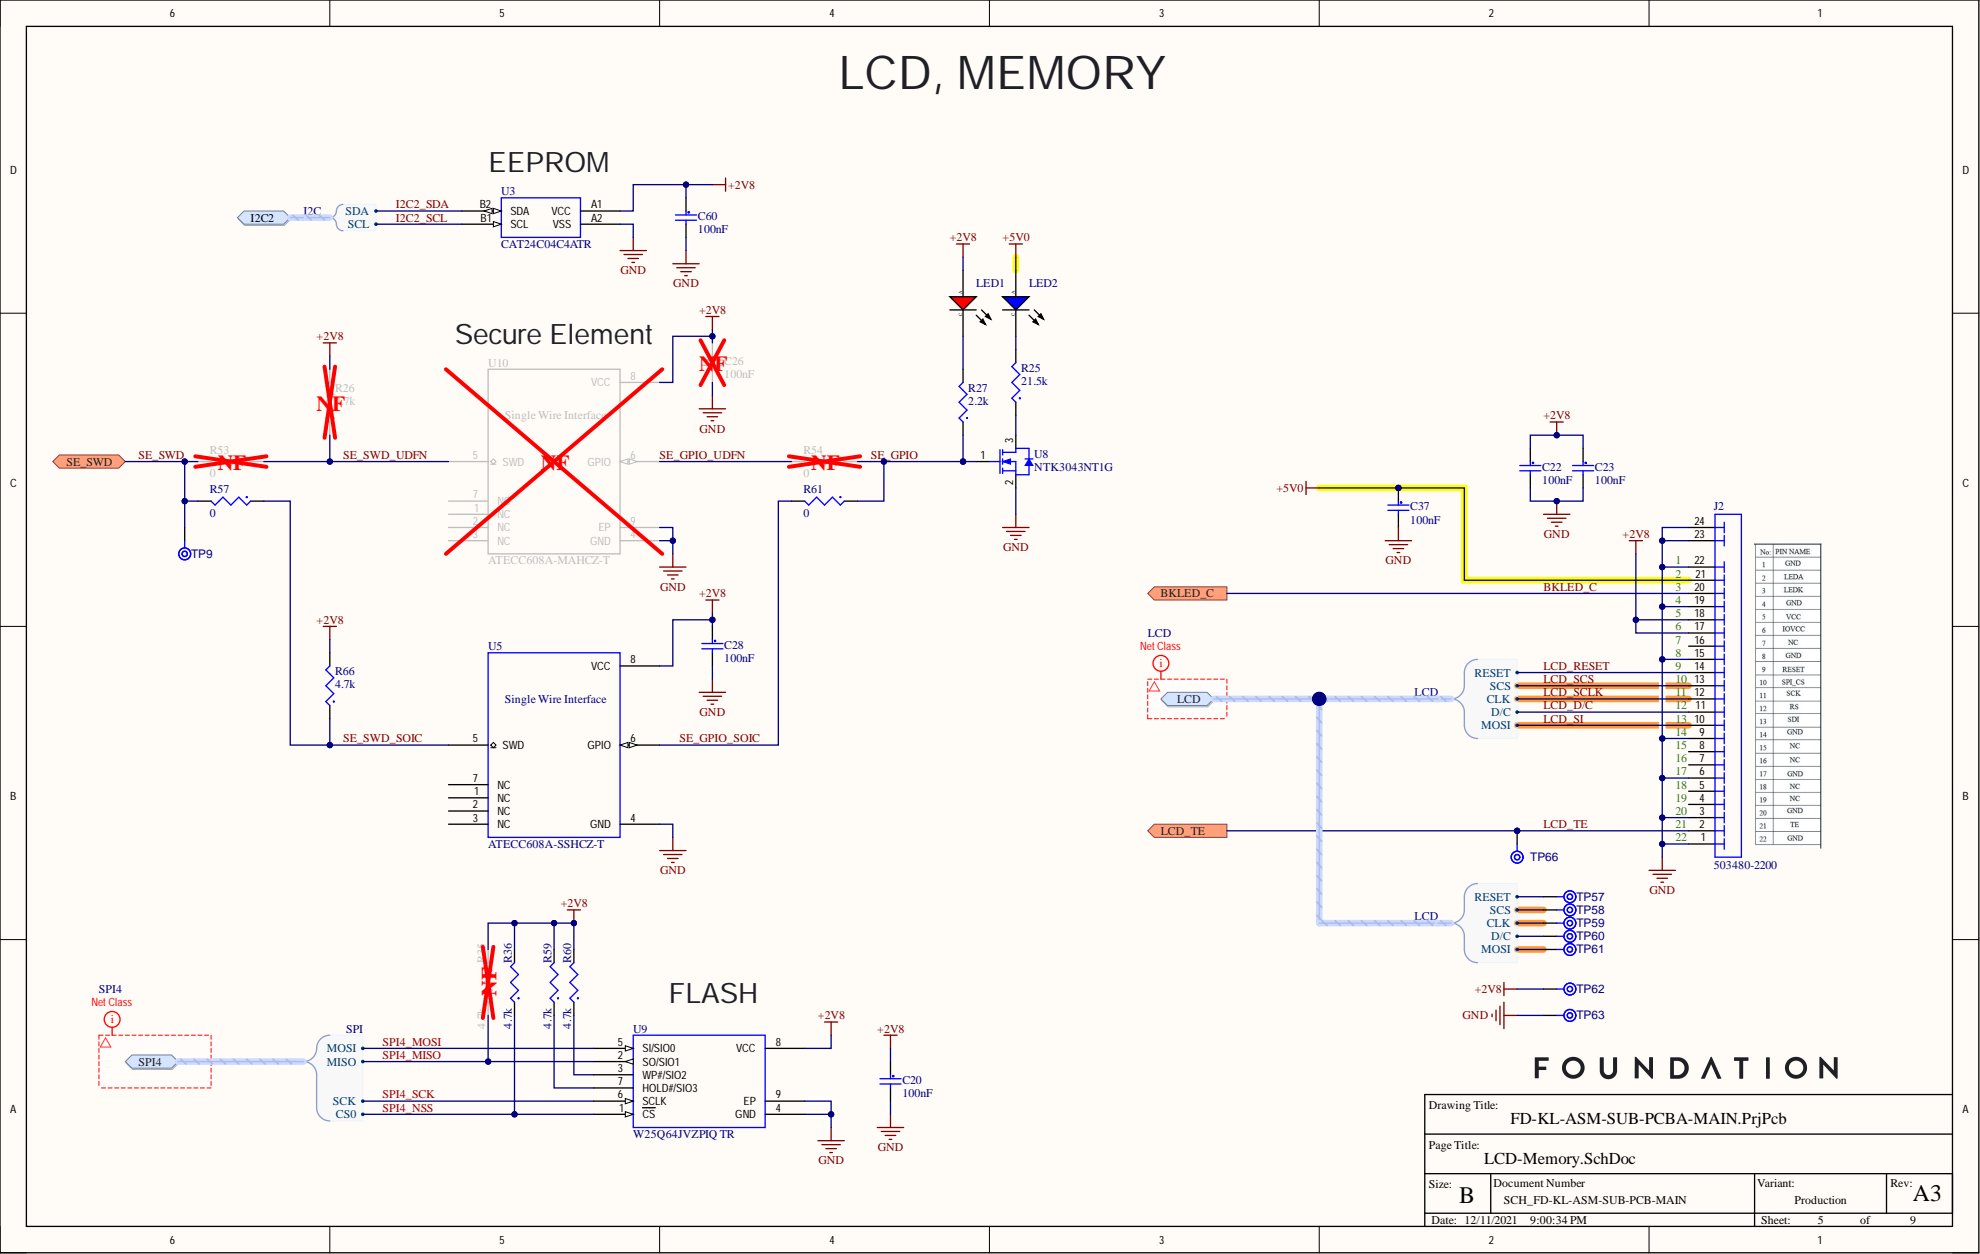
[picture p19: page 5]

2 1
2 2

FD-KL-ASM-SUB-PCBA-MA

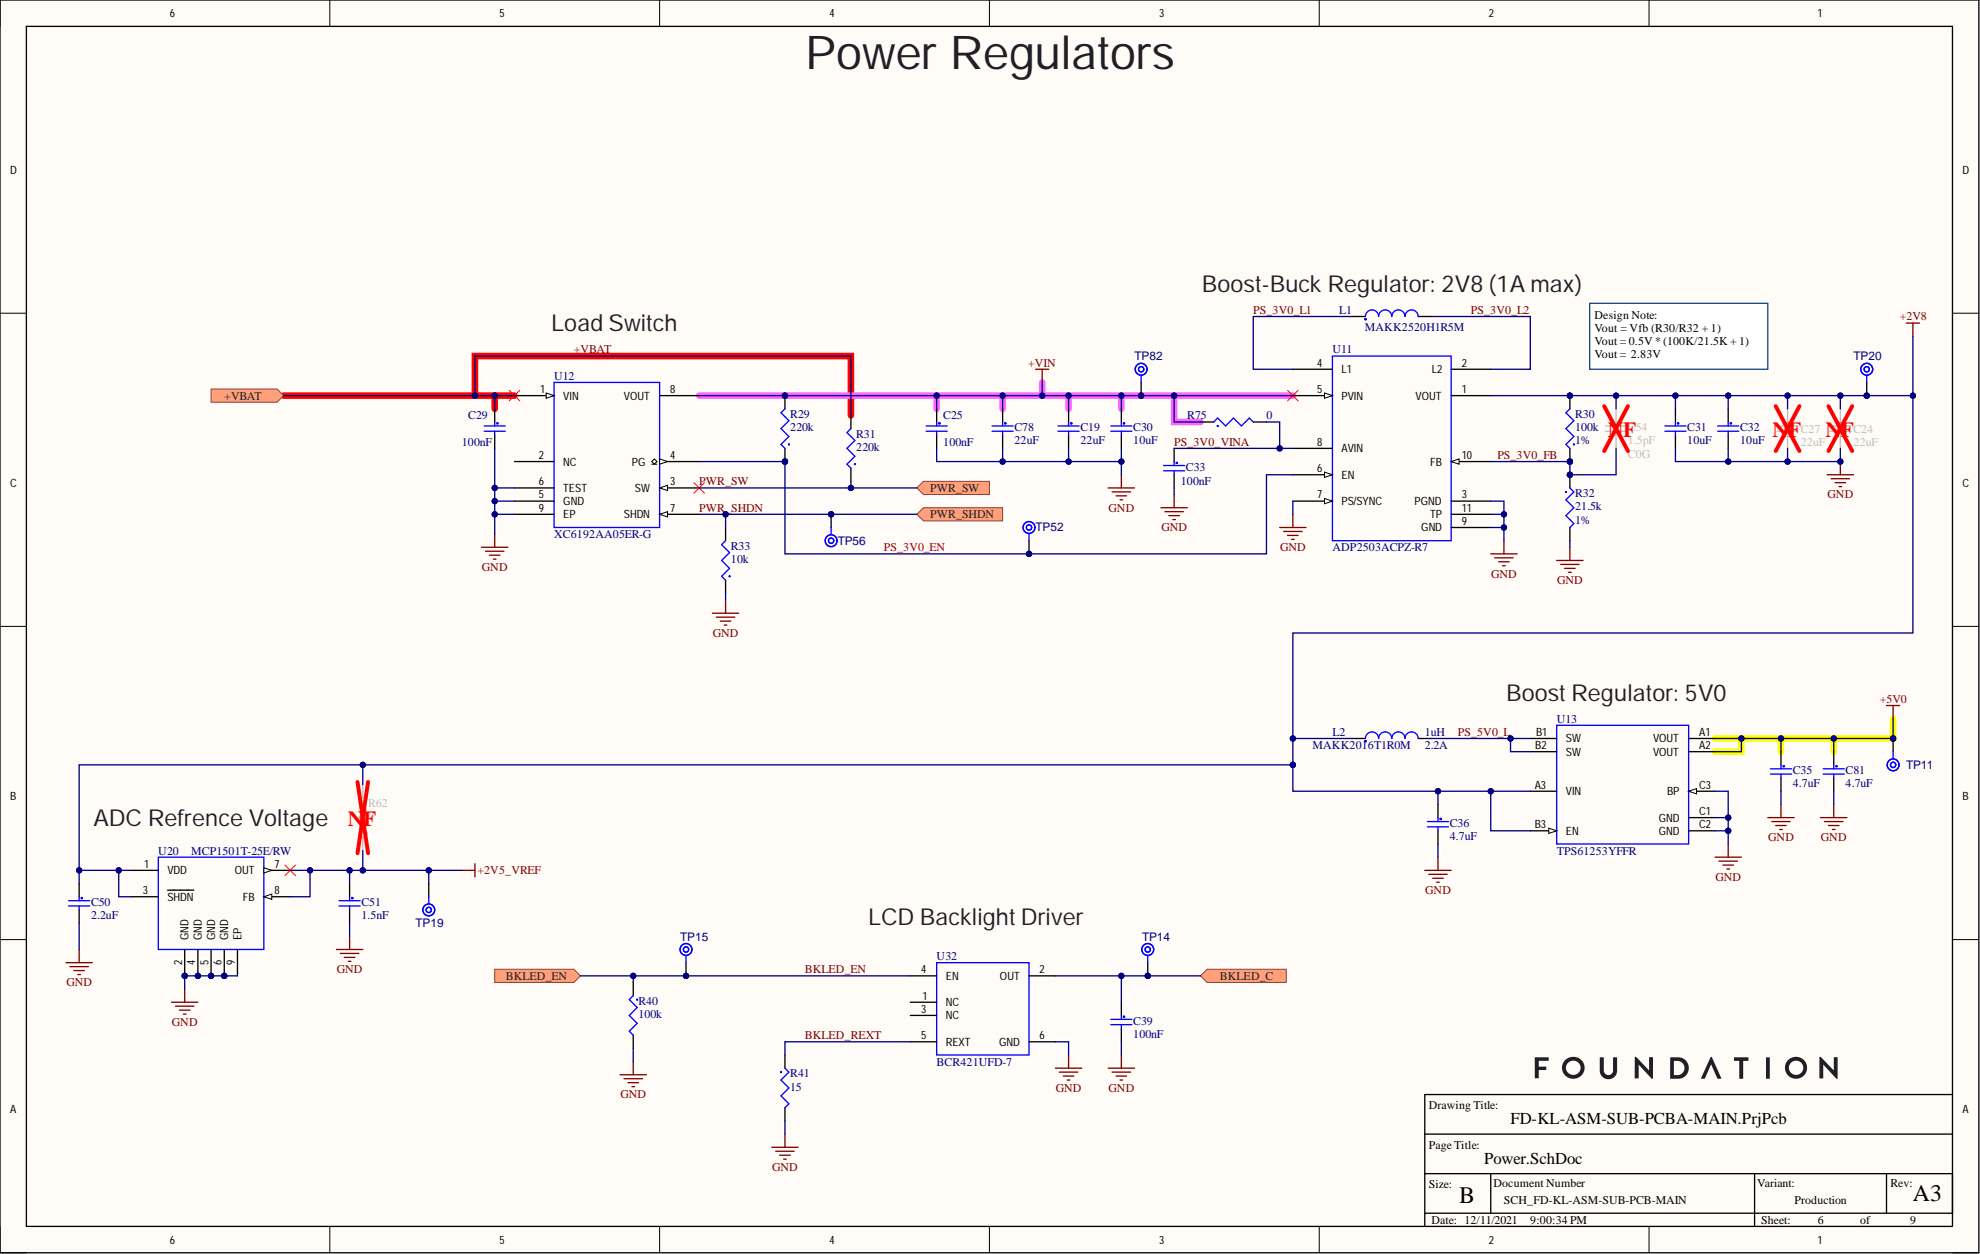
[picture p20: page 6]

Boost-Buck Regulator: 2V8 (1A max)

AVIN 8 | 100k C32 C27 +5V0

SW B2 GND

ADC Refrence Voltage NF

FD-KL-ASM-SUB-PCBA-MAIN.PrjPcb

B | | Rev: A3 Variant:

Date: 12/11/2021 9:00:34 PM | Sheet: 6 of 9

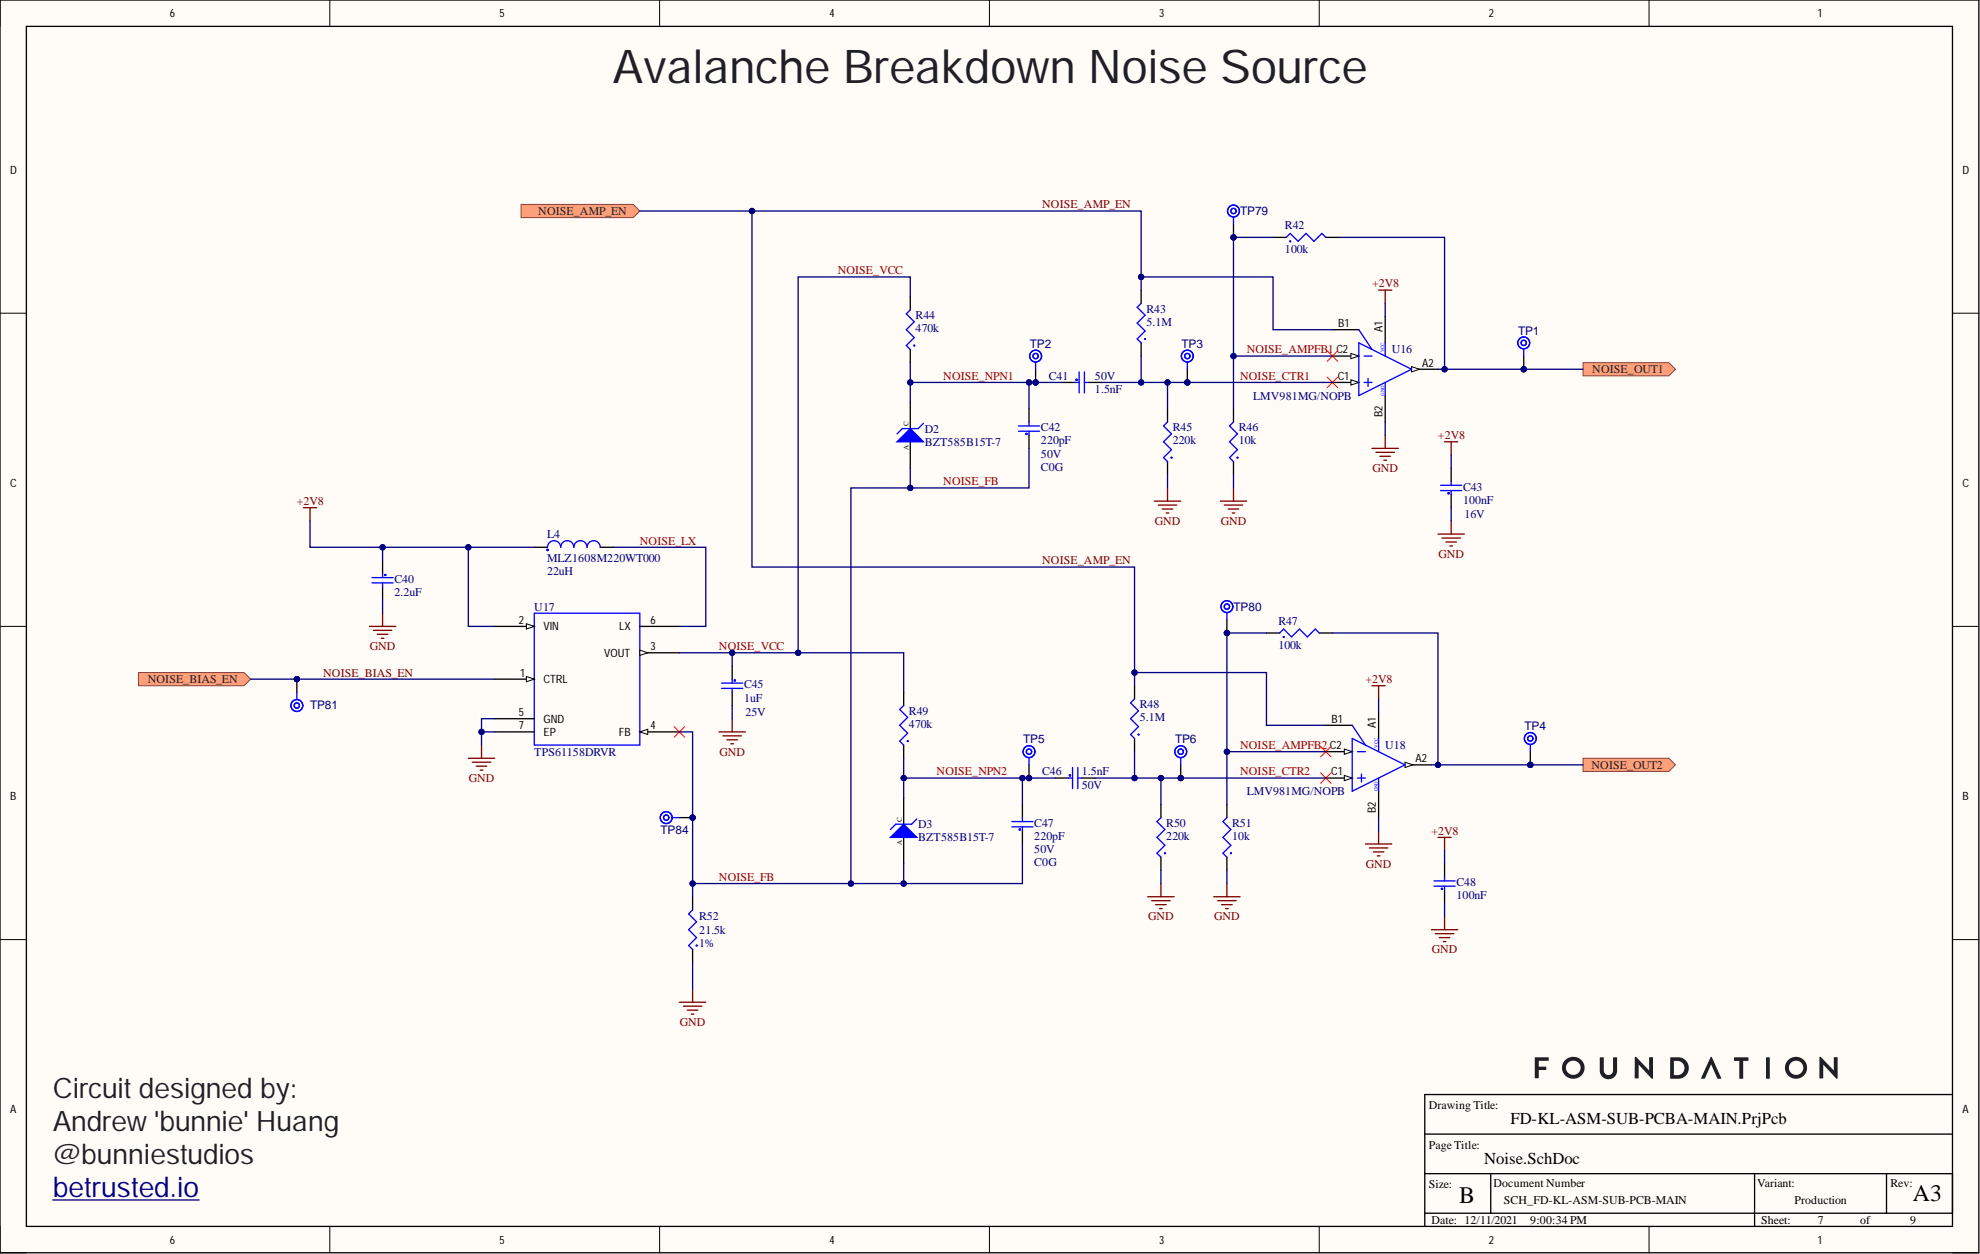
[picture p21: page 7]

Avalanche Breakdown Noise Source

N OISE _ V C C

N OISE | _ AMPF B 1

N OISE _CT R 1

N OISE | _ AMPF B 2

N OISE _CT R 2

D 3 | | | LMV 9 8 1MG/ N

FD-KL-ASM-SUB-PCBA-MA

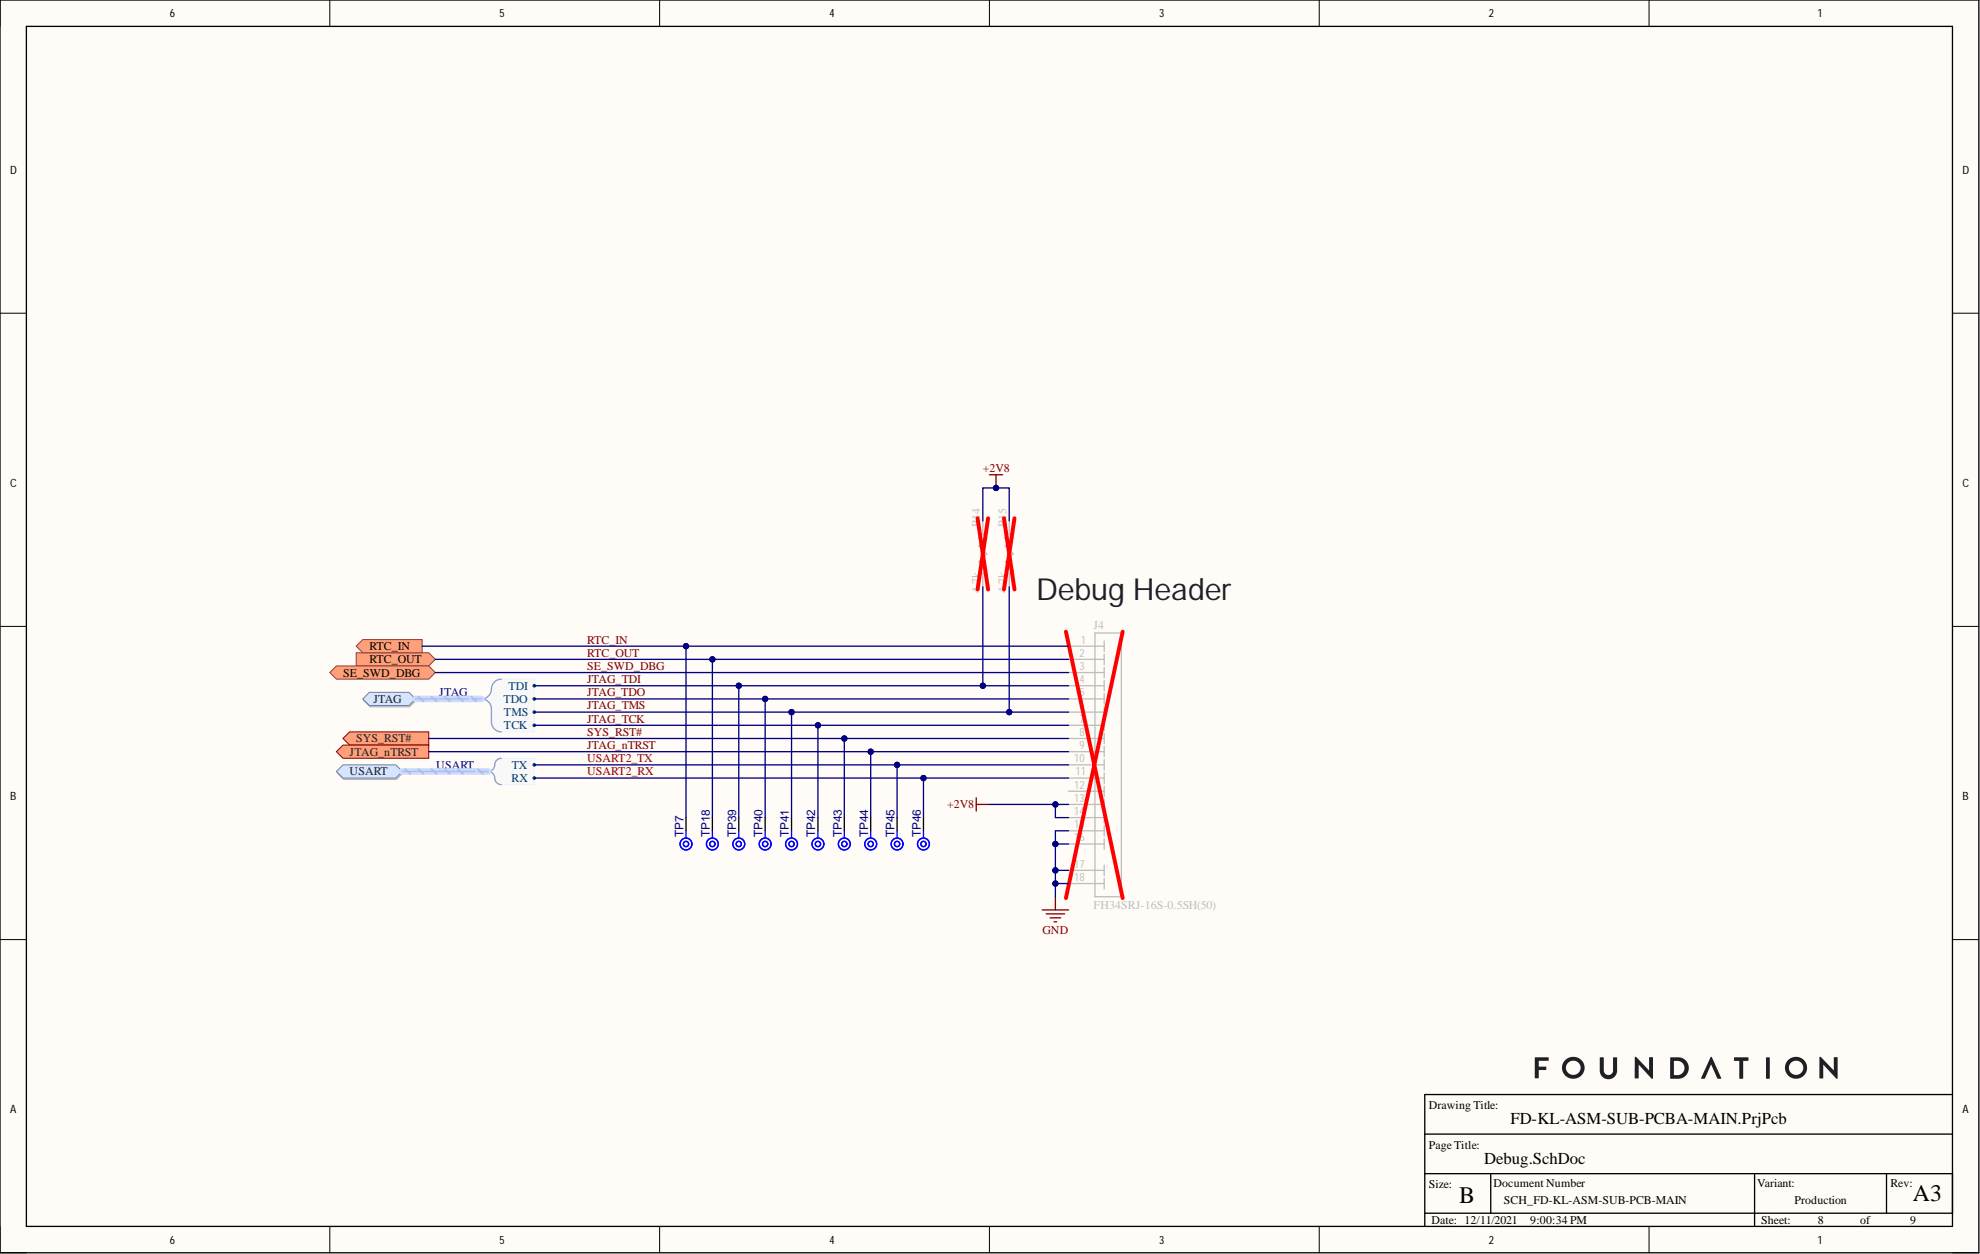
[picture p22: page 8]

FD-KL-ASM-SUB-PCBA-MA

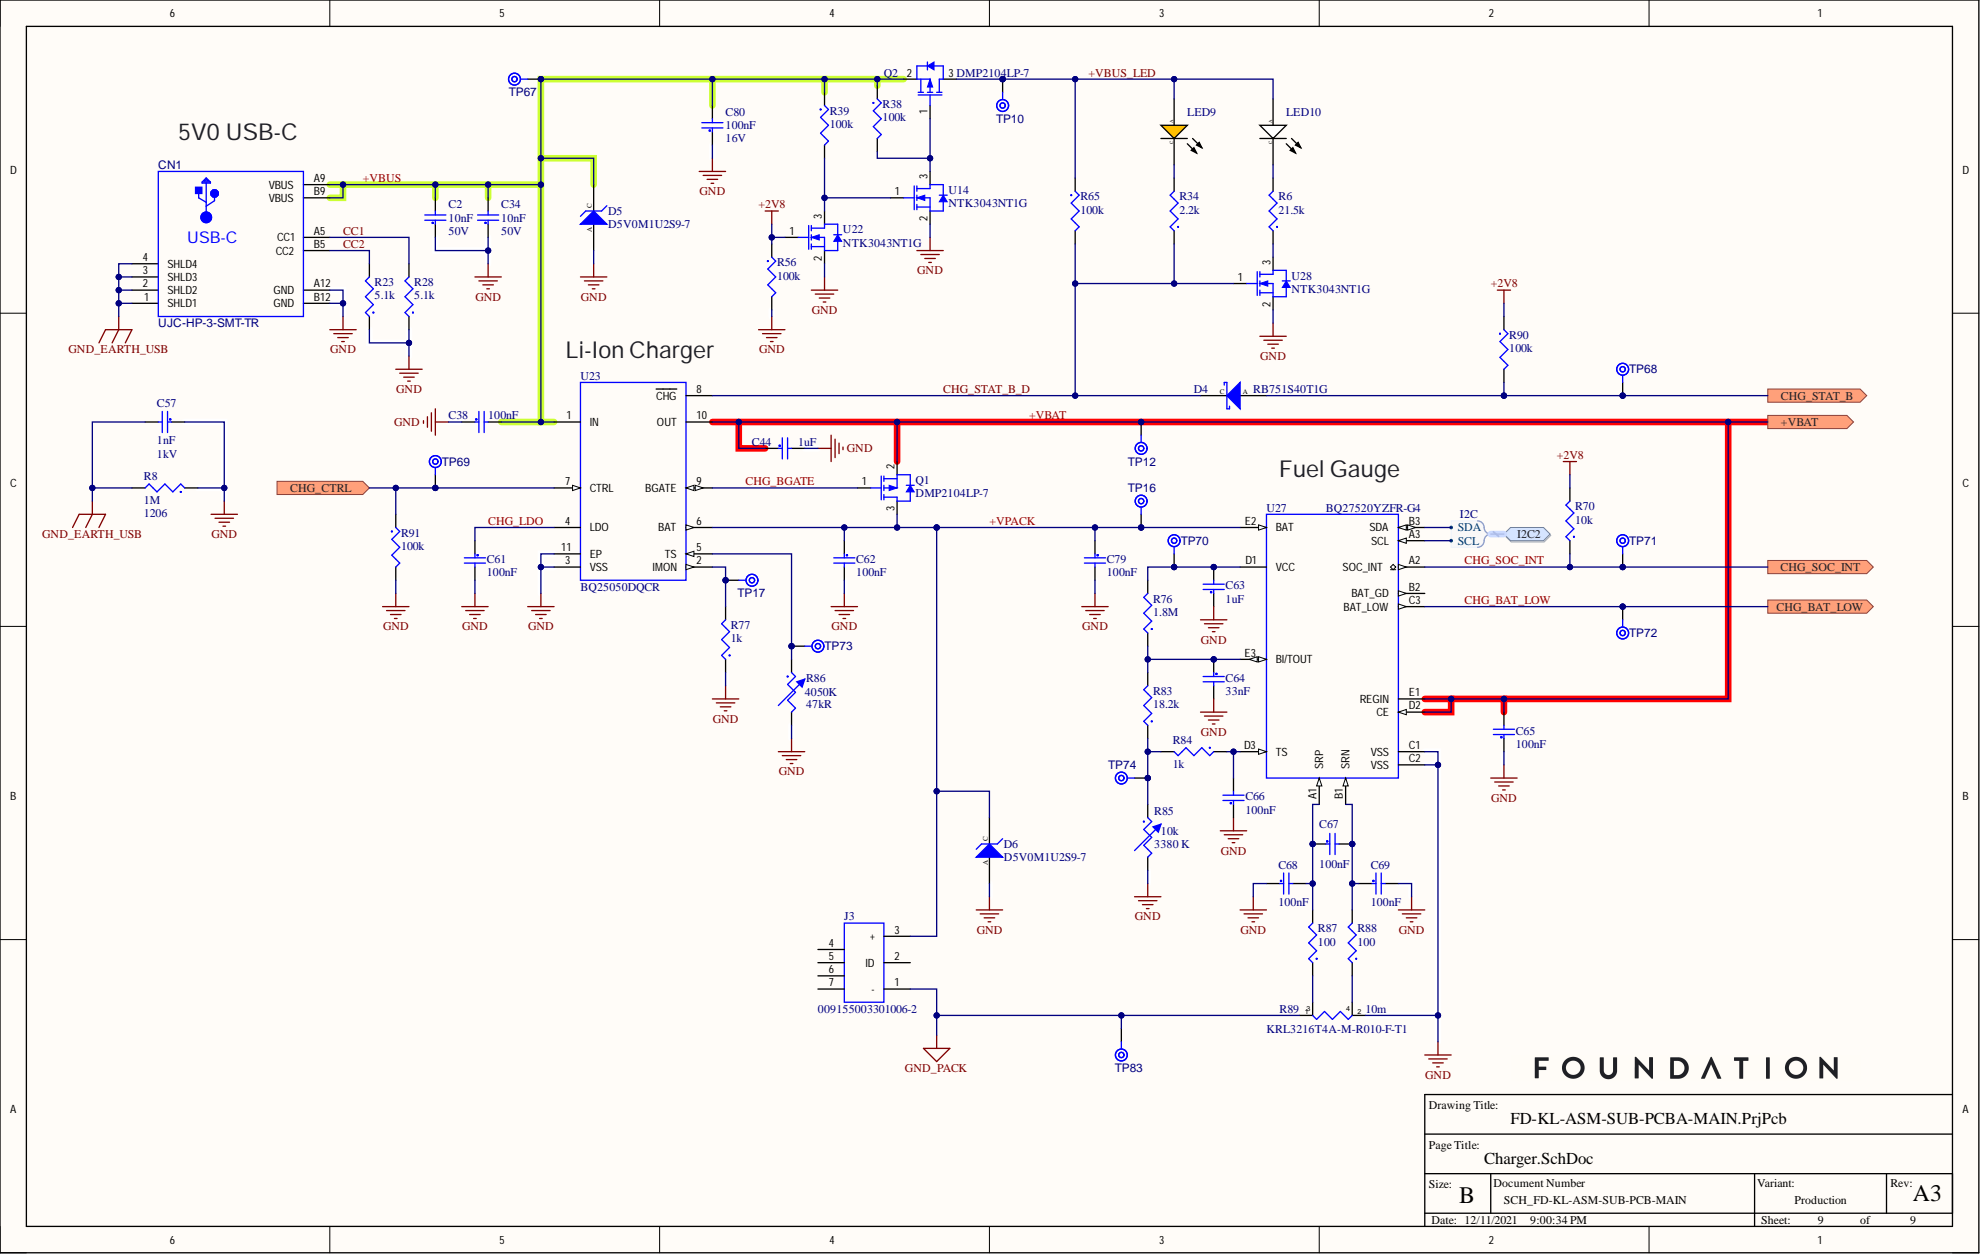
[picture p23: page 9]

FD-KL-ASM-SUB-PCBA-MA

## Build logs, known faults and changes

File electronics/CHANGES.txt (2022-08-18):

Use this file to document changes made to the designs. 

As per section 3.3.b of LICENSE.txt, information should be added but NEVER REMOVED from this file. 

When adding information, please provide a brief entry with a date and the nature of the modification for each design change.

CHANGES:

REV A1: 11/23/2022
 - Initial Release

REV A2: 11/29/2022
 - Added testpoints. Added some alternates to BOM.

REV A3: 12/11/2021
 - Changed U1 to TPS79920YZU
 - Added  C87-89, TP85. Removed R1, C1.

REV A4: 04/19/2022
 - DNI: U1, X1, C49, C55-56, C88-89
 - Changed R34 to 1k, R6 to 4.7k, R27 to 300, and R25 to 2.2k

REV A5: 05/02/2022
 - Switched P19 from TL1014BF160QG to TL1014BF220QG

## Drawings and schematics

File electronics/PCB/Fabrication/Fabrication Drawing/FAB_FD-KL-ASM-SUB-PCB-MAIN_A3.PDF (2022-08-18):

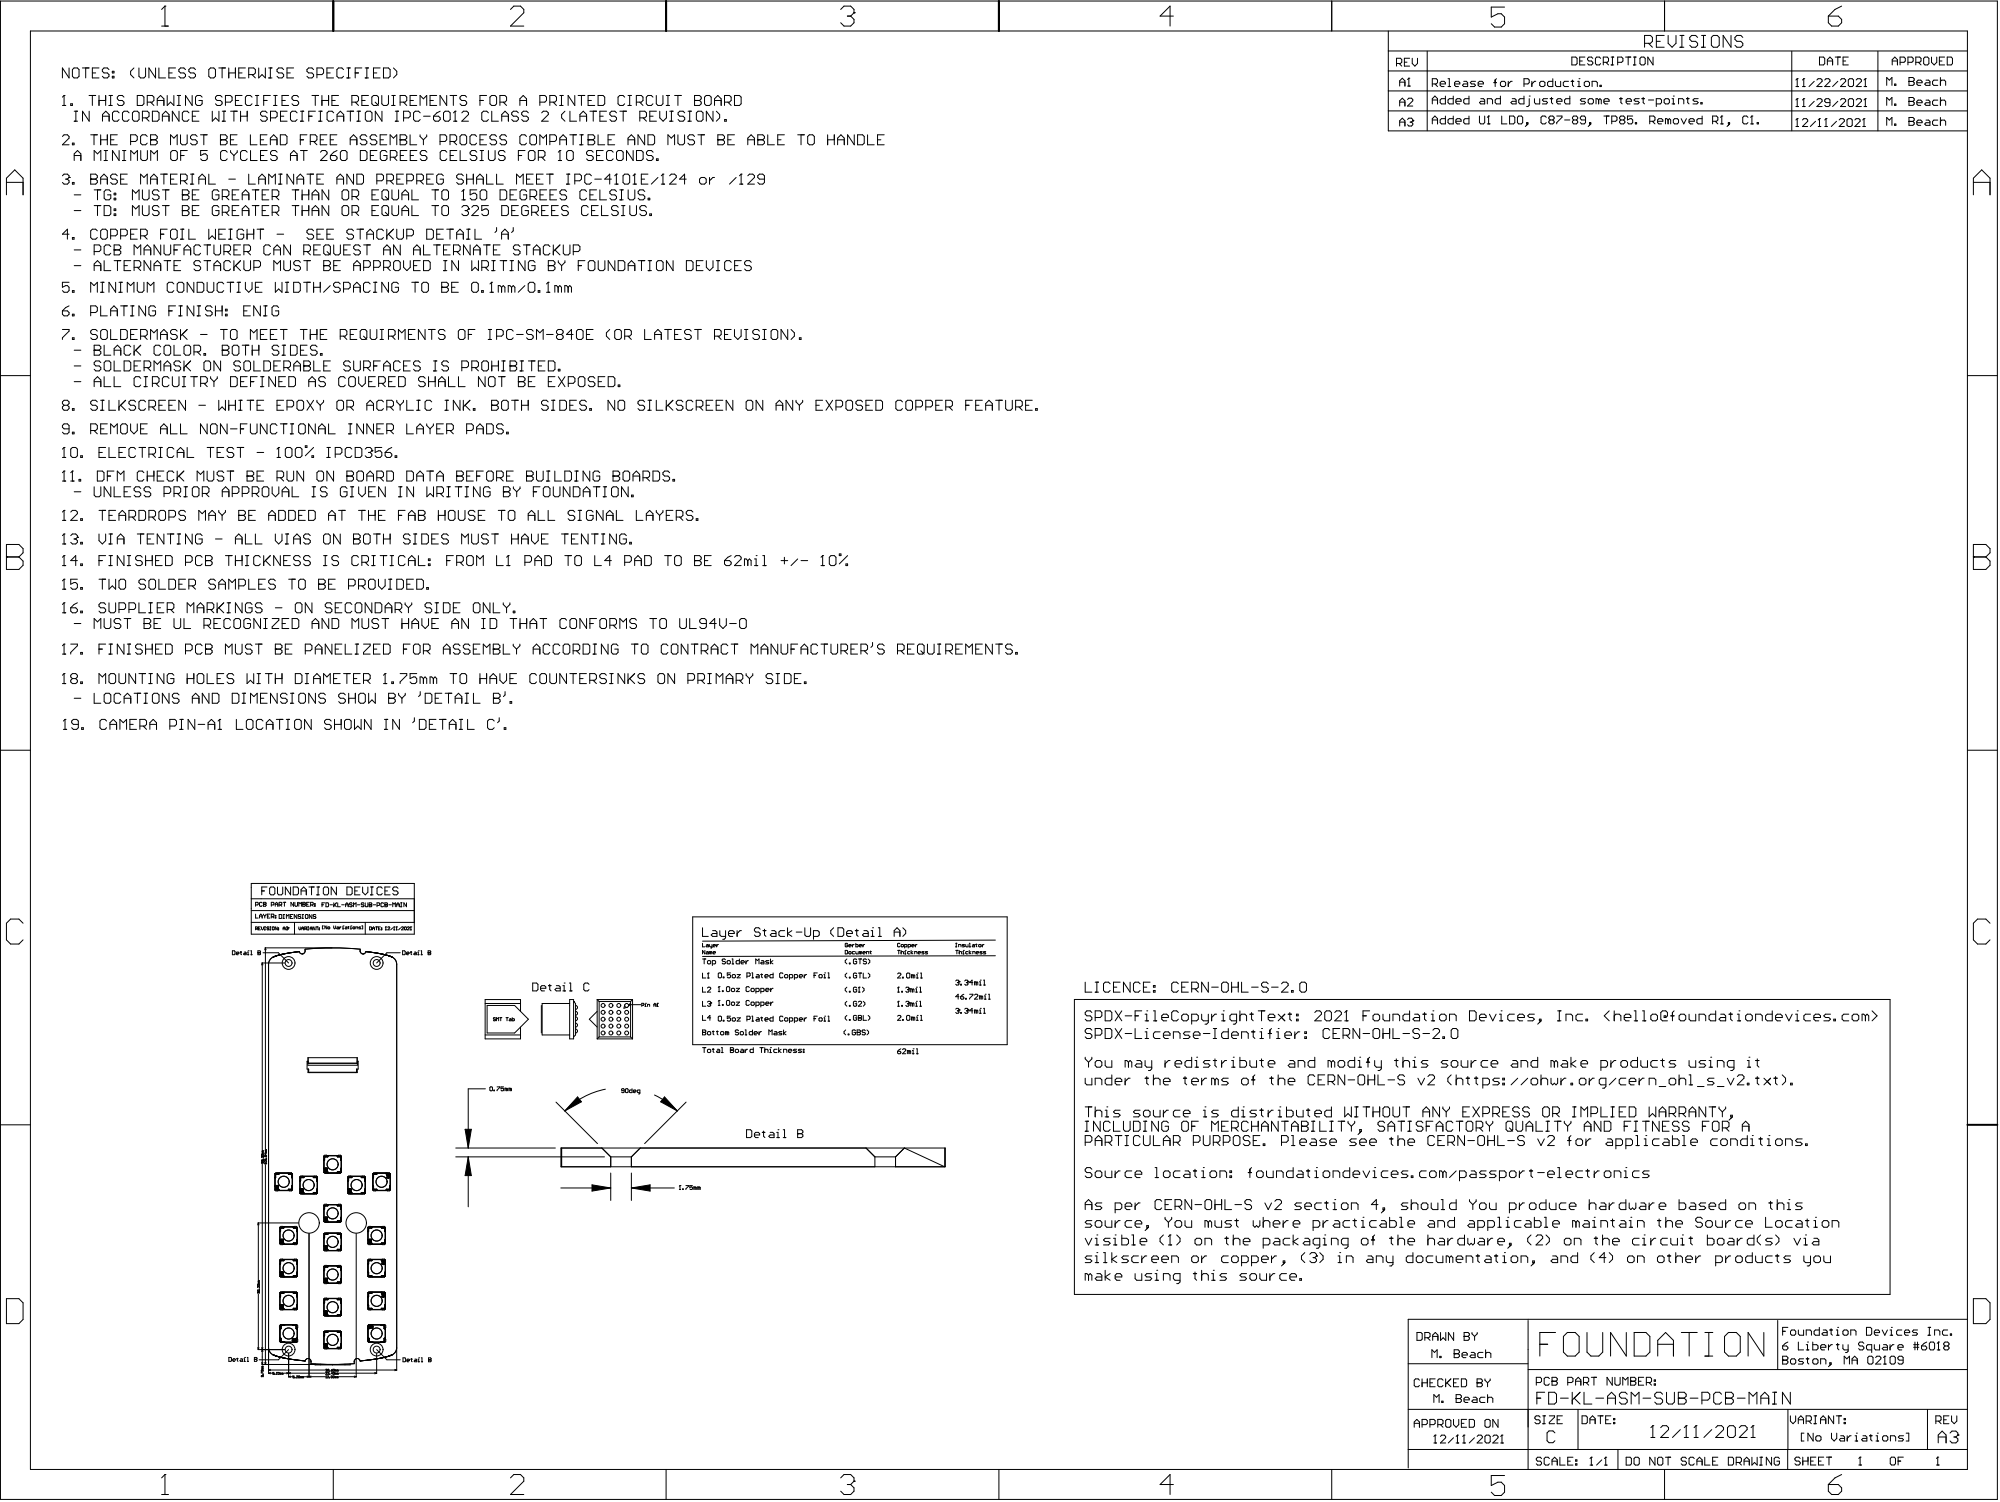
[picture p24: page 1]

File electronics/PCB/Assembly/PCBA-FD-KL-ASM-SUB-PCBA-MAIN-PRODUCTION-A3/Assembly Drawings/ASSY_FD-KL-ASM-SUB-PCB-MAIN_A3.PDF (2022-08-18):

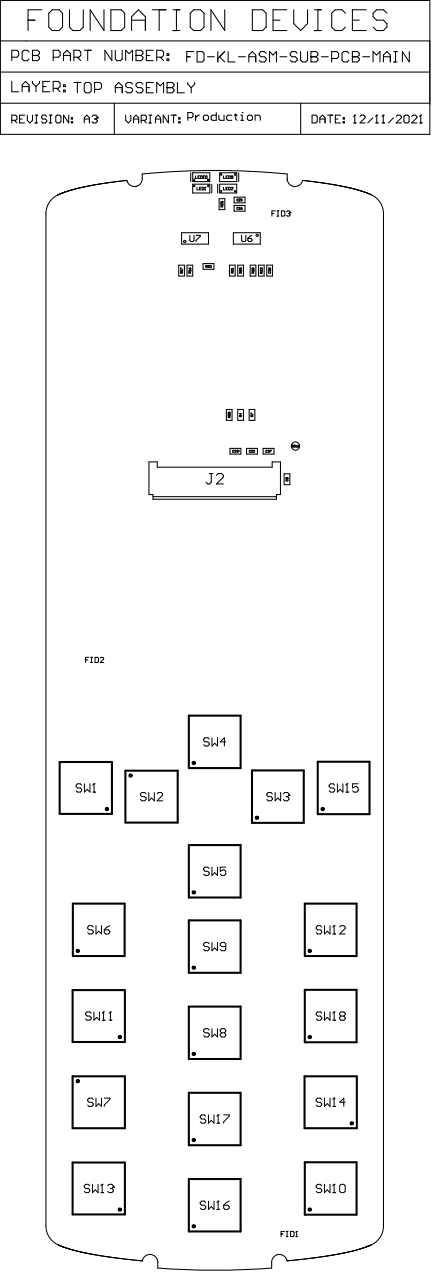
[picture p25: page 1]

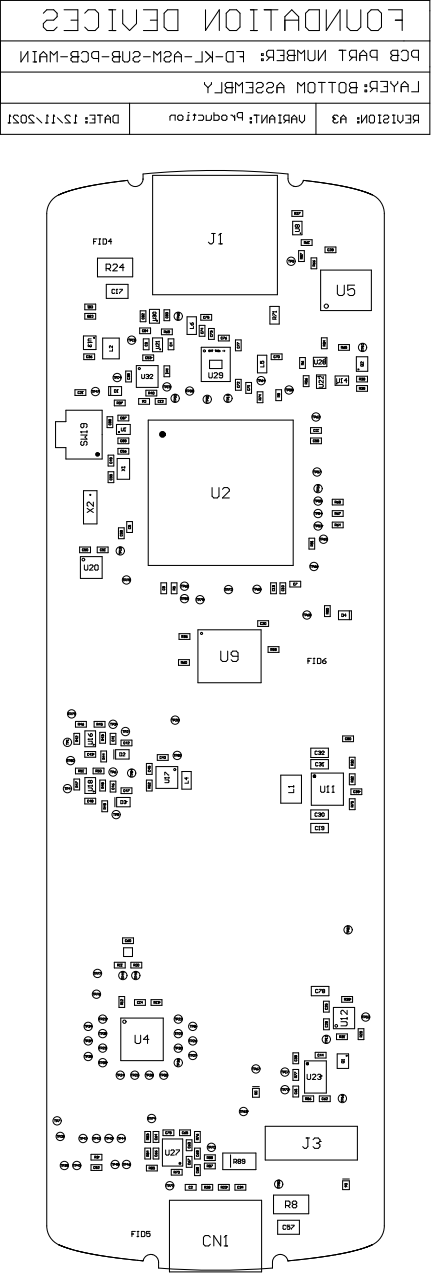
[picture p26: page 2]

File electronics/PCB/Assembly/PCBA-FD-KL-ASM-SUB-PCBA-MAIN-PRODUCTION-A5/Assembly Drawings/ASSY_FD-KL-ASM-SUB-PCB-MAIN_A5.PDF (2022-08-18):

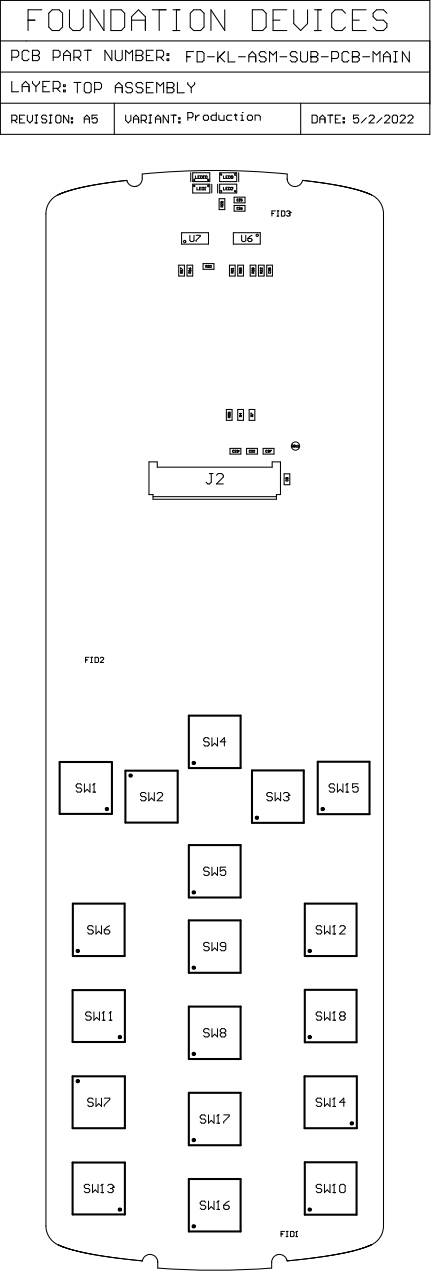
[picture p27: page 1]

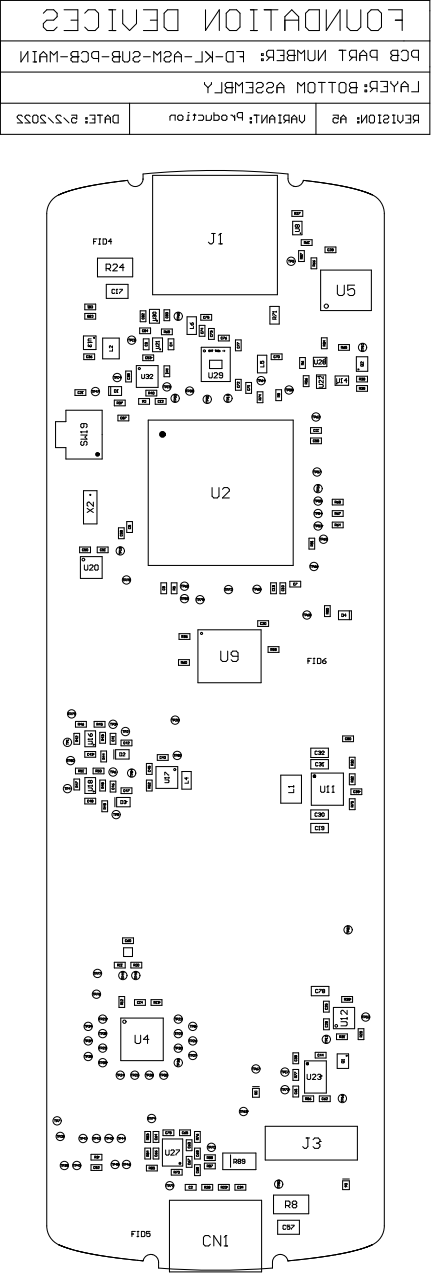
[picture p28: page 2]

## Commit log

2022-08-18 Add electronics files
    [BOM_FD-KL-ASM-SUB-PCB-MAIN_A3.csv, BOM_FD-KL-ASM-SUB-PCB-MAIN_A3.xlsx, BOM_FD-KL-ASM-SUB-PCB-MAIN_A5.csv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]
2022-08-18 Rename folder and add README.md
    [BOM_FD-KL-ASM-SUB-PCB-MAIN_A3.csv, BOM_FD-KL-ASM-SUB-PCB-MAIN_A3.xlsx, BOM_FD-KL-ASM-SUB-PCB-MAIN_A5.csv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]
2022-08-31 Add mechanical files
    [FD-KL-ACTUATOR-BUTTON-POWER-REV-B.stp, FD-KL-ASM-FG-DISPLAY-LCD-IPS-2-INCH.stp, FD-KL-BATTERY-LITHIUM-RECHARGEABLE.stp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]
2022-08-31 Add Bill of Materials (BOM)
    [FD-KL-BOM-UPPER-LVL-REVB .csv, FD-KL-BOM-UPPER-LVL-REVB.xlsx]
2022-08-31 Move BOM and rename one file
    [FD-KL-BOM-UPPER-LVL-REVB.csv, FD-KL-BOM-UPPER-LVL-REVB.xlsx]
